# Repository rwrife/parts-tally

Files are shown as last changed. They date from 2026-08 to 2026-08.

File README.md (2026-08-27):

# Parts Tally

**Parts Tally is a USB-powered ESP32-C3 smart bin scale that counts small workshop parts by calibrated unit weight and serves a private local inventory app—no cloud account required.**

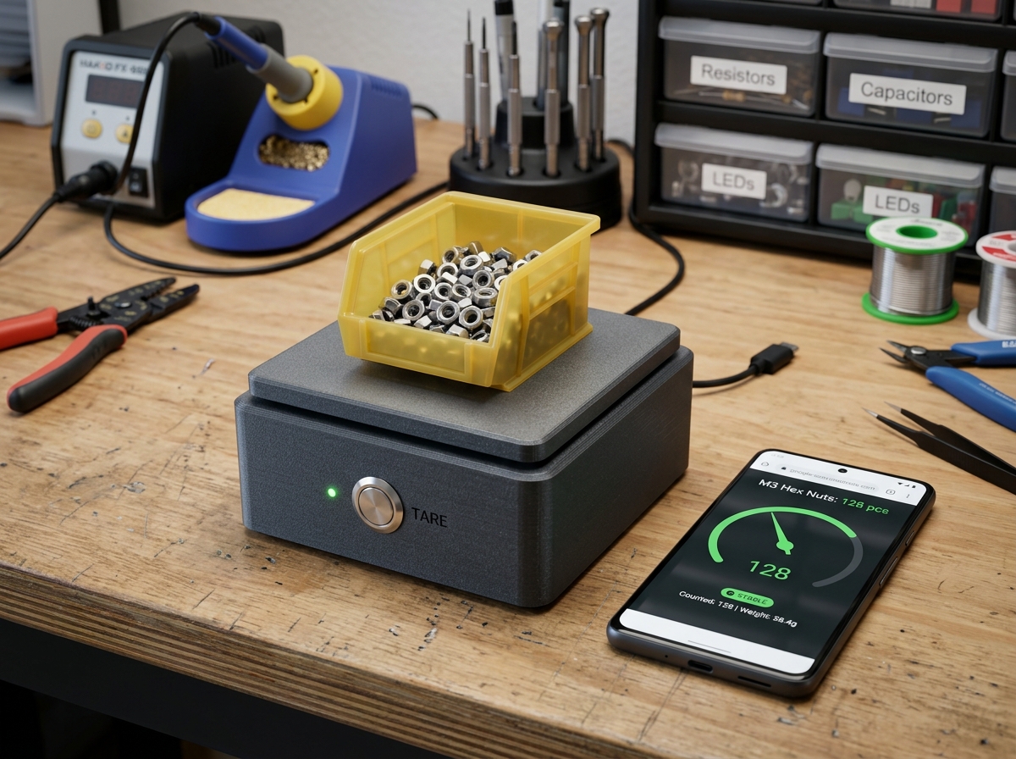
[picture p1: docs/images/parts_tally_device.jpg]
Parts Tally Concept Design


## Motivation

Counting screws, nuts, washers, crimp terminals, and other small repeated parts by hand is slow. Visual estimates are unreliable, while commercial inventory systems are often expensive or cloud-dependent. Parts Tally turns a removable parts bin into a local smart scale: select a saved part profile, tare the empty bin, and see an estimated count plus a low-stock state.

## Target users

- Home workshops and makerspaces
- Electronics benches with reels, connectors, and loose hardware
- Small repair shops that want a lightweight, account-free stock signal
- Hobbyists who need repeatable counts rather than purchasing automation

## Use cases

1. **Fast recount:** place a known bin on the platform, select its profile, and estimate count from net mass / calibrated unit mass.
2. **Low-stock check:** show green/amber/red locally against a user-defined threshold.
3. **Calibration:** weigh an empty bin, then a known sample (for example 20 washers) to derive unit mass.
4. **Portable records:** export profiles and count history as JSON or CSV from the local app.
5. **Manual correction:** override a noisy estimate and preserve an auditable correction without pretending the scale is exact.

## Intended workflow

1. Assemble the low-voltage load-cell platform and connect it by USB-C to a 5 V supply.
2. On first use, the device exposes a temporary local setup access point; the user configures Wi-Fi or continues in direct-device mode.
3. Open the phone-friendly local web app, create a part profile, tare the empty bin, and run a known-count calibration.
4. Place the loaded bin on the platform. The device filters readings, reports stability and uncertainty, then estimates count.
5. Review or correct the count, set a threshold, and export local data when desired.

## MVP

- ESP32-C3 controller with USB power, Wi-Fi, and BLE-capable hardware
- One TAL220B 5 kg 4-wire bar load cell and SparkFun SEN-15242/NAU7802 bridge ADC module
- Physical tare/calibrate button and RGB status indication
- Stable-weight detection, tare, multi-point known-count calibration, and count uncertainty
- On-device local API plus responsive installable PWA
- Local profile/history storage with JSON and CSV export/import
- Offline/direct-device mode after initial assets are loaded
- Reproducible firmware and app builds
- Editable KiCad schematic and custom carrier PCB after the module prototype is validated

## Non-goals

- Trade-certified weighing or legal-for-commerce measurements
- Medical, food-safety, life-safety, or unattended industrial process control
- Exact counting of mixed parts or parts whose unit mass varies substantially
- Mains wiring, battery charging in the first revision, or cloud accounts
- Automatic purchasing or supplier-stock claims

## Hardware at a glance

```text
5 V USB-C supply
       |
XIAO ESP32-C3 ---- planned status RGB LED
   |       |
   |       +------ tare/calibrate button
   |
   +-- SparkFun SEN-15242 / NAU7802 -- TAL220B 5 kg bar load cell
   |
   +-- local Wi-Fi HTTP/WebSocket API ------ phone/desktop PWA
```

Prototype target: approximately **USD $35–$55**, excluding a user-printed enclosure. This is a planning range, not a quote; current prices and availability must be re-verified before ordering.

## Safety limits

Parts Tally is a SELV/USB 5 V bench device. Do not connect it to mains, exceed the load cell's rated load, use it as a structural support, or rely on it for safety-critical stock decisions. Provide overload stops in the mechanical design. A printed enclosure must not carry loads through the PCB. This project is not a certified scale.

## Privacy, permissions, and storage

- No account, analytics, or cloud service is required.
- Profiles, calibration values, thresholds, and history are stored on the device and/or in browser-local storage as documented by the app implementation.
- Network access is limited to local device discovery/setup and the device API.
- BLE/Wi-Fi permissions are requested only when a chosen provisioning flow needs them.
- Export and import are explicit user actions; secrets are excluded from exports.
- Optional future integrations must remain opt-in and preserve a useful offline mode.

## Source-of-truth policy

Final BOM data belongs in **KiCad schematic symbol properties** (`Manufacturer`, `MPN`, supplier fields, and BOM notes) and is exported to `bom/bom.csv`. `bom/preliminary-bom.csv` is only a planning document and must not drift into a competing source of truth.

The hardware release uses real editable KiCad sources—not image-only drawings—including:

- `hardware/kicad/parts-tally.kicad_pro`
- `hardware/kicad/parts-tally.kicad_sch`
- `hardware/kicad/parts-tally.kicad_pcb`

The project, schematic, routed two-layer PCB, custom library, validation notes, OpenSCAD platform source, and schematic-exported BOM now exist under `hardware/kicad/`, `hardware/reports/`, `hardware/mechanical/`, and `bom/`. The tagged release workflow generates and validates Gerber/drill/CPL/PDF/assembly/render artifacts; generated outputs supplement rather than replace editable source. No assembled-board, fabricated-board, or physical-test claim is implied.

## Current status and milestones

1. Requirements, measurement model, and architecture risk review — baselined in the editable documents below; this is documentation/static evidence only
2. Datasheet-backed module-chain selection and synthetic capture harness — complete; physical fixture/bench characterization explicitly pending
3. Editable KiCad schematic and schematic-backed BOM — implemented; CI-native ERC and static review evidence are recorded under `hardware/reports/`
4. Firmware and local protocol with host-side tests
5. Accessible local PWA and import/export — implemented and software-tested with a mock transport; physical-device/browser verification remains pending
6. Carrier PCB, native DRC, and editable mechanical platform — implemented and statically validated; physical fit/assembly/bring-up remains pending
7. Tagged fabrication release package and unexecuted assembly/bring-up procedures — release-candidate automation implemented; physical evidence remains pending

Baseline contracts:

- [System architecture and count/uncertainty model](docs/architecture.md)
- [Reviewed measurable requirements](hardware/requirements.md)
- [Planned module wiring and carrier boundary](hardware/interfaces.md)
- [Datasheet-backed component selection](hardware/selection.md)
- [Planned module build and capture record](hardware/module-prototype.md)
- [Datasheet/source manifest](hardware/datasheets/manifest.json)
- [Unexecuted prototype verification plan](docs/verification-plan.md)
- [Assembly, calibration, and bring-up procedure](docs/assembly-and-bring-up.md)
- [Integrated release verification record](docs/release-verification.md)
- [Release packaging and fabrication assumptions](release/README.md)
- [Licensing and third-party notices](LICENSES.md)
- [Risk register](docs/risk-register.md)
- [Machine-readable architecture contract](docs/architecture-contract.json)

Run `python3 scripts/validate_contract.py` and `python3 -m unittest discover -s tests -v` to validate document, safety, dependency, risk, evidence-state, and synthetic capture-tool consistency.

See [PLAN.md](PLAN.md), [hardware/README.md](hardware/README.md), and the GitHub issue backlog.

## Development quickstart

The implementation toolchains will be pinned in the first project-skeleton issue. The intended commands are:

```bash
# Firmware (PlatformIO)
cd firmware
pio run
pio test -e native

# Companion PWA (TypeScript/Vite, Node 22.23.1 / npm 10.9.8)
cd app
npm ci
npm run lint
npm run typecheck
npm test
npm run build
npx playwright install chromium # first local run
npm run test:e2e
```

See `app/VERIFICATION.md` for the latest exact software verification record. App end-to-end tests use a mock device and do not establish physical integration.

## Contributing

Keep changes issue-scoped and evidence-backed. Never report physical bench testing unless a real assembled prototype and procedure were used; distinguish static analysis, simulation, firmware/app tests, and physical measurements.

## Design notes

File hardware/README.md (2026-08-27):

# Hardware

## System description

Parts Tally measures a removable bin through a 4-wire strain-gauge load cell. A 24-bit bridge ADC digitizes the differential signal. An ESP32-C3 filters readings, applies tare and known-count calibration, estimates quantity, stores local profiles, drives a status LED, and serves the local app.

The first hardware increment selected proven modules; revision A0 now includes an editable carrier layout and parametric mechanical platform so measurement and mechanical risks can be characterized before fabrication. This is still static design evidence, not prototype evidence.

## Controller choice

The selected prototype controller is **Seeed Studio XIAO ESP32-C3, SKU 113991054**. The selected ADC module is **SparkFun SEN-15242** using **Nuvoton NAU7802**; the selected carrier IC is **NAU7802SGI**. The selected load cell orderable SKU is **SparkFun SEN-14729**, containing the HT Sensor TAL220B 5 kg cell. See [`selection.md`](selection.md) and [`datasheets/manifest.json`](datasheets/manifest.json).

## Interfaces

The exact planned logical wiring map and carrier-board ownership boundary are versioned in [`interfaces.md`](interfaces.md), with pre-power and capture steps in [`module-prototype.md`](module-prototype.md). Physical connector orientation and continuity remain pending until real units exist.

- 4-wire load cell bridge to ADC: excitation +/-, signal +/-
- NAU7802 3.3 V I2C: XIAO D4/GPIO6 SDA and D5/GPIO7 SCL
- One debounced physical tare/calibrate button
- One addressable or discrete RGB status indicator with brightness limit
- USB-C 5 V input through the controller module for prototype power/programming
- 2.4 GHz Wi-Fi for local HTTP/WebSocket app; BLE reserved for evaluated provisioning only
- UART/USB recovery and accessible test points on the carrier revision

## Power plan

- SELV 5 V USB input only for MVP
- Use the controller module's regulated rail for logic, subject to measured noise/current validation
- The carrier schematic uses 3.3 V DVDD and a 3.0 V nominal internal-LDO AVDD/excitation setting; measure this boundary condition before PCB release
- Input protection, decoupling, bridge filtering, keyed load-cell connection, and reverse-current blocking are captured in the editable schematic
- No battery or charger in revision A

## Mechanical and enclosure concept

A rigid base holds one end of the TAL220B straight-bar load cell; a top plate/bin cradle attaches to the sensing end. Parametric OpenSCAD source in [`mechanical/`](mechanical/) includes M5 load-cell mounts, PCB standoffs outside the force path, cable strain relief, four non-slip feet, and four adjustable overload stops. The carrier places the XIAO antenna at a board edge with enforced two-layer copper/component keepouts; enclosure adaptations must also keep metal and fasteners out of that volume. Fit, print tolerance, stop gap, and load transfer remain physically unverified.

## Safety limits

- USB/SELV only; never connect to mains wiring
- Do not exceed the selected load cell's rated capacity
- Not structural, legal-for-trade, medical, food-safety, or life-safety equipment
- Do not use counts as the sole control for hazardous or critical stock
- Mechanical stops and a stable, non-slip base are mandatory before load testing

## Editable KiCad deliverables

The carrier-board milestone preserves:

- `kicad/parts-tally.kicad_pro`
- `kicad/parts-tally.kicad_sch`
- `kicad/parts-tally.kicad_pcb`
- project symbol/footprint tables or vendored custom libraries when needed
- ERC and DRC reports with explained exclusions
- schematic PDF and PCB renders as supplements, never substitutes
- fabrication Gerbers, drill files, CPL when applicable, and release archive

The project/schematic, routed `.kicad_pcb`, project-local symbols/footprints, generators, acceptance validators, datasheet extraction, schematic-backed BOM, mechanical source, DRC report, and review renders are present. `scripts/build_release.py` and the tagged release workflow generate and validate Gerber/drill/CPL/PDF/assembly/render outputs without treating those files as physical evidence.

Final Manufacturer, MPN, supplier, price-observation, stock-observation, datasheet, and BOM-note data lives in KiCad symbol properties. `../bom/preliminary-bom.csv` is not authoritative. From the repository root, regenerate the tracked BOM with `python3 hardware/kicad/export_bom.py`, or follow [`kicad/README.md`](kicad/README.md). Assembly order, connector maps, test points, current-limited first power, calibration, recovery, and troubleshooting are in [`../docs/assembly-and-bring-up.md`](../docs/assembly-and-bring-up.md).

## Key layout constraints for the carrier revision

- Keep bridge inputs short, paired, and away from USB/Wi-Fi/high-edge-rate nets
- Follow selected ADC reference layout and decoupling guidance
- Preserve the XIAO/ESP32-C3 antenna keepout on all copper and enclosure metal
- Separate mechanical mounting loads from the PCB
- Add named test points for rails, ADC clock/data, bridge excitation, and ground
- Provide clear connector pin-1/polarity labels and accessible programming recovery

## Current evidence

The editable KiCad project, schematic, routed carrier PCB, project-local symbols/footprints, manufacturer-document/source manifest, schematic-exported BOM, targeted validators, OpenSCAD mechanical source, and static review evidence now exist. See [`kicad/README.md`](kicad/README.md), [`mechanical/README.md`](mechanical/README.md), [`reports/schematic-validation.md`](reports/schematic-validation.md), and [`reports/layout-validation.md`](reports/layout-validation.md).

Native KiCad 9 reports zero ERC/DRC violations and zero unconnected PCB items; repository validators pass. The issue #7 release workflow regenerates Gerber/drill/CPL/PDF/assembly/render outputs from the tagged sources and verifies archive checksums. These are static checks only. No electrical/EMC simulation, physical fixture/assembly, continuity result, measurement, fabrication, calibration, load test, or field evidence exists yet. The design remains explicitly untested in hardware.

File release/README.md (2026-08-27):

# Parts Tally release candidate packaging

`release/manifest.json` freezes the board/firmware/protocol/app compatibility set. The release archive is generated from a tagged checkout by `scripts/build_release.py`; generated files are not preferred editable source.

## Build

Use KiCad 9.0.x with Python and `pcbnew` available. The GitHub workflow uses the pinned `kicad/kicad:9.0` image on an amd64 runner.

```bash
python3 scripts/build_release.py \
  --version v0.1.0-rc.1 \
  --source-ref v0.1.0-rc.1 \
  --source-revision "$(git rev-parse HEAD)" \
  --output dist
python3 scripts/validate_release.py \
  --bundle dist/parts-tally-v0.1.0-rc.1.zip
```

The archive contains:

- Gerber X2 copper, mask, paste, silkscreen, and Edge.Cuts layers;
- separate plated/non-plated Excellon drills plus an SVG drill map;
- KiCad and JLCPCB-format BOMs plus a normalized placement file;
- schematic PDF, assembly SVGs, and PCB renders;
- ERC/DRC/parity reports and a command log;
- editable KiCad/OpenSCAD sources, assembly/bring-up instructions, release report, and license notices;
- a per-file `SHA256SUMS` plus an archive checksum.

## Fabrication/assembly assumptions

The selected validation profile is JLCPCB's documented standard two-layer capability. The source rules are more conservative than its published minimums: 0.15 mm minimum track, 0.20 mm clearance, 0.60/0.30 mm via, and 0.50 mm copper-edge clearance.

This RC is suitable for **quote/DFM review**, not an unattended order:

1. Keep 100 × 60 mm, two layers, 1.6 mm nominal FR-4 unless a reviewed change is made.
2. Review the rendered files and confirm the outline, polarity, pin 1, antenna keepout, and drill split.
3. J1 has two bottom-tented, unfilled 0.60/0.30 mm through-vias inside VBUS pads. For PCBA, obtain explicit assembly-process approval for solder-wicking risk or use documented hand solder/rework. Do not represent tenting as plugging/filling.
4. The JLCPCB BOM intentionally leaves `LCSC Part #` blank for user-sourced items. It is a parity-checked assembly aid, not a guarantee that every part is available for turnkey PCBA.
5. Re-check C189895/SM04B-GHS-TB(LF)(SN), all blank supplier IDs, prices, stock, substitutions, rotations, and feeder class at checkout.
6. No substitute connector/module/ADC inherits this review. Re-run ERC, DRC, BOM/CPL parity, and datasheet pin/package review after any substitution.
7. Order a stencil only if the chosen assembly path needs one. For hand assembly, inspect USB-C and SOIC solder joints before power.

## Evidence boundary

A release archive, render, successful build, static analyzer, or simulated fixture is not physical evidence. Bench and field verification remain pending until an identified physical assembly is tested with dated raw measurements under `docs/verification-plan.md` and `docs/assembly-and-bring-up.md`.

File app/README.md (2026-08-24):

# Parts Tally companion PWA

This is the installable, responsive local companion for the Parts Tally device. It implements the HTTP/WebSocket contract in [`../docs/protocol.md`](../docs/protocol.md) and validates device status, events, and backup data at runtime against generated copies of [`../docs/schemas/api-v1`](../docs/schemas/api-v1).

## Reproducible development

Node 22.23.1 and npm 10.9.8 are pinned in `package.json`; every dependency is an exact version in `package-lock.json`.

```bash
cd app
npm ci
npm run generate
npm run lint
npm run typecheck
npm test
npm run test:a11y
npm run build
npx playwright install chromium   # first local run only
npm run test:e2e
```

`npm run generate` refreshes the runtime JSON Schema copies and their aggregate SHA-256 marker. UI components depend on `DeviceTransport`; only `src/protocol/httpTransport.ts` constructs `fetch` or `WebSocket`. Playwright uses the same adapter interface with an in-memory mock device. Those tests are software evidence only and do not claim a physical ESP32, load cell, ADC, radio, or browser/device combination was tested.

## Data boundaries and privacy

- Profiles, calibration, thresholds, history, measurements, and faults returned by a connected device are device-authoritative.
- The browser caches only the selected address, device ID, and the newest 100 validated profile/history/status records so an offline user can identify the device and inspect a clearly marked snapshot. Cached measurements are never presented as a live count.
- Device secrets, Wi-Fi passwords, setup tokens, session tokens, and authorization headers are memory-only and are not written to browser storage, JSON, CSV, the service-worker cache, or logs.
- JSON backup schema v3 contains device name, profiles, calibration, thresholds, and up to 256 device history entries. Import rejects incompatible schema versions and secret-bearing fields, displays the device preview, then requires an explicit apply action within the protocol's 30-second window.
- CSV export contains history columns only. Both exports require a user action.
- There are no accounts, analytics, ads, telemetry, cloud API, or background tracking. The app requests no camera, microphone, contacts, location, notification, or BLE permission.

## Offline and installation behavior

The generated service worker precaches the application shell (HTML, JavaScript, CSS, and icon). After one successful HTTPS or localhost load, a supporting browser can reopen and install the shell without Internet access. API responses are deliberately not service-worker cached. A device still must be reachable over its direct AP or trusted LAN for authentication, mutations, and current measurements. Browsers may evict installed-site data; JSON backup remains the portable copy.

The device protocol is plaintext HTTP/WebSocket. Use a trusted local network: an on-path observer can see bearer traffic. HTTPS-hosted public pages may also block plaintext local-device requests as mixed content, so device-hosted or explicitly trusted local serving is the practical deployment model.

## Platform scope and limitations

- Android Chromium: install prompts and standalone display are expected, but local-network permission prompts and background suspension vary by vendor/version.
- iOS/iPadOS Safari: installation is via Share → Add to Home Screen; service-worker storage can be evicted and WebSockets are normally suspended when backgrounded. There is no background counting or notification promise.
- Desktop Chromium supports installation; Firefox can use the web app and offline cache but does not consistently offer desktop PWA installation; Safari behavior varies by current macOS release.
- The automated matrix is mobile and desktop Chromium emulation. It does not prove Safari/iOS, Firefox, Android hardware, local-network routing, captive-portal behavior, or physical device integration.

## Accessibility and measurement safety

The UI is keyboard-operable, uses native landmarks/labels/tables/forms, visible focus, at least 44 px controls, text-and-icon state cues, an aria-live update region, responsive layouts, and reduced-motion handling. Vitest runs axe checks, but automation does not replace manual screen-reader, zoom, contrast, touch, and real-device testing.

Every protocol no-count state withholds the numeric count: uncalibrated, unstable, stale, disconnected, saturated, overload indicated, below tare, calibration invalid, and excessive uncertainty. Parts Tally is USB 5 V SELV-only, not legal-for-trade, not certified, and not suitable for safety-critical stock or measurement decisions. Observe load-cell ratings and mechanical overload protection.

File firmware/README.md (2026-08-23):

# Parts Tally firmware

Pinned PlatformIO/C++17 project for Seeed XIAO ESP32-C3 (`seeed_xiao_esp32c3`, Arduino) and native tests. Install exactly `platformio==6.1.18`, then run `pio test -d firmware -e native` and `pio run -d firmware -e seeed_xiao_esp32c3`. Platforms and the ArduinoJson 7.4.2/WebSockets 2.7.1 dependencies are pinned in `platformio.ini`.

Hardware is behind narrow ADC, button, active-low RGB, clock, atomic storage and transport interfaces. Pins mirror `hardware/interfaces.md`: SDA 6, SCL 7, button 3, RGB 4/5/10 and UART TX/RX 21/20. The standard-C++ domain implements health-first faults, sustained-step acceptance, P95-P5/slope/outlier diagnostics, the >=2 s/>=20 sample gate, safe tare/calibration, deterministic rounding, conservative uncertainty and explicit null-count states. Persistence is versioned/checksummed, bounds history to 256 by default and never exports secret members.

## Target integration status

The target build contains the NAU7802 register/DRDY/fault adapter, verified two-slot Preferences records, full-NVS factory erasure, entropy-backed setup session, setup AP, HTTP route dispatch, and sequenced WebSocket server. These paths compile but have not run on a physical XIAO/NAU7802 assembly, so register waveforms, calibration completion, AP association, NVS interruption behavior, route latency, RF coexistence, and RGB/button timings remain bench checks. `/api/v1` policy and route behavior are independently exercised by native tests.

The direct AP starts on every boot. Hold dedicated GPIO3 during power-up to create the five-minute setup session, fetch `/api/v1/setup/session`, then call `/api/v1/setup/provision`. Provisioning supports empty SSID/password direct-only mode or starts asynchronous STA while retaining the AP. Later sessions are obtained from unauthenticated `POST /api/v1/session` using the persisted device secret and exact Origin/JSON checks. WebSocket clients connect to the exact `ws://192.168.4.1:81/api/v1/events` path and send `{"type":"authenticate","token":"SESSION"}` as their initial message; authorization and expiry are tracked per client, and setup sessions cannot stream events.

## Physical reset and USB recovery

The target implements this factory-reset gesture on dedicated GPIO3: power up while holding for 10 seconds, blink red/blue for the final three seconds, cancel if released early, erase the complete NVS partition (settings, profiles, thresholds, history, and Wi-Fi/device secrets), and restart only after successful erasure. A short release requests local tare; an arbitrary later long press cannot factory-reset. No network route resets the device. Host tests cover the state machine, but physical timing and erasure still require target/bench verification. Credentials persist in NVS and are excluded from normal logs/status/export/JSON backup/CSV, but NVS is not a secure element or a defense against physical flash extraction.

OTA is omitted. For USB recovery, power only from USB 5 V SELV, connect GPIO9/BOOT to GND, briefly press RESET, release BOOT, identify the serial port, then run `pio run -d firmware -e seeed_xiao_esp32c3 -t upload --upload-port PORT`. Press RESET without BOOT and inspect serial at 115200. If enumeration fails, use a known data cable, disconnect carrier peripherals, and repeat. Flashing is not guaranteed to erase NVS. BOOT is not the user button. Never connect mains.

This workshop aid is not legal-for-trade, certified, or suitable for safety-critical inventory decisions.

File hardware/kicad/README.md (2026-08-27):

# Parts Tally KiCad source

This directory contains the editable KiCad 9 schematic and routed two-layer carrier PCB for revision A0. The design is static-analysis/DRC reviewed but has not been fabricated, assembled, electrically measured, calibrated, or field tested.

## Files

- `parts-tally.kicad_pro` — KiCad project metadata and board rules.
- `parts-tally.kicad_sch` — editable schematic and BOM source of truth.
- `parts-tally.kicad_pcb` — editable 100 × 60 mm routed board source.
- `lib/parts-tally.kicad_sym` — project-local XIAO ESP32-C3 and NAU7802 symbols.
- `lib/parts-tally.pretty/XIAO_ESP32C3.kicad_mod` — project-local module footprint.
- `generate_schematic.py` — reproducible schematic generator.
- `generate_pcb.py` — reproducible board outline, placement, rules, labels, mounting holes, and antenna keepouts from the KiCad XML netlist.
- `pre_route_critical.py` — fixed VBUS/I2C/+5 V escapes around the USB locator holes and XIAO antenna keepout.
- `route_pcb.py` — netclass-aware Specctra DSN/SES exchange and idempotent GND-pour fill.
- `finish_route.py` — deterministic local TP2 branch left by the autorouter.
- `validate_hardware.py` — schematic pin map, net-label, NC, BOM-property, and extraction checks.
- `validate_pcb.py` — PCB/netlist parity, geometry, mounting, keepout, zone, route-width, and analog-pair checks.
- `export_bom.py` — deterministic export from schematic properties to `../../bom/bom.csv`.

The XIAO library source and adaptation are documented in `lib/README.md`.

## Board design summary

- 100 × 60 mm, two copper layers, four 3.2 mm M3 mounting holes.
- U1 sits at the top-right edge with four layer-specific rule areas. Copper, tracks, vias, and components are prohibited in the transformed XIAO/ESP32-C3 antenna regions.
- J1 is a **power-only** USB-C UFP. Its locator-hole geometry requires two bottom-tented 0.60/0.30 mm via-in-pad transitions to tie the duplicated VBUS pad locations on B.Cu. D+/D-/SBU remain intentionally NC.
- VBUS and protected +5 V use 0.50 mm trunks with short 0.20 mm branches/neck-downs; low-current 3.3 V distribution uses 0.20 mm routing. Thirteen 0.15 mm FreeRouting neck-down segments occur only at constrained fine-pitch pads and remain above the selected prototype process minimum.
- `/LC_S+` and `/LC_S-` measure 10.01/11.04 mm (1.04 mm delta). `/AIN+` and `/AIN-`, including filter branches, measure 37.71/30.91 mm (6.80 mm delta). These are low-bandwidth bridge signals, not timing-matched digital pairs.
- Solid-connected GND pours cover F.Cu and B.Cu; five GND vias join the planes. The bottom plane is the preferred return path.
- TP1–TP10 expose VBUS, protected +5 V, 3V3, GND, AVDD, I2C, bridge inputs, and VBG.
- J2 pin order is 1 E+, 2 E-, 3 S+, 4 S-. Verify the real harness continuity and wire colors before power.

## Validate the committed design

Use KiCad 9 and Python 3.11+:

```bash
python3 -m venv .venv
. .venv/bin/activate
pip install -r hardware/kicad/requirements.txt
python hardware/kicad/validate_hardware.py
python hardware/kicad/export_bom.py --check

kicad-cli sch erc --exit-code-violations \
  -o /tmp/parts-tally-erc.rpt hardware/kicad/parts-tally.kicad_sch
kicad-cli sch export netlist --format kicadxml \
  -o /tmp/parts-tally.xml hardware/kicad/parts-tally.kicad_sch
python hardware/kicad/validate_pcb.py \
  hardware/kicad/parts-tally.kicad_pcb --netlist /tmp/parts-tally.xml
kicad-cli pcb drc --severity-all --all-track-errors --exit-code-violations \
  -o /tmp/parts-tally-drc.rpt hardware/kicad/parts-tally.kicad_pcb
```

The GitHub workflow runs the native KiCad commands in `kicad/kicad:9.0`, avoiding host-version ambiguity. Review evidence is in `../reports/layout-validation.md` and `../reports/generated/`.

## Regenerate placement and reroute

The committed `.kicad_pcb` is the reviewed editable layout source. The placement and critical escapes are reproducible; FreeRouting is nondeterministic, so a new autoroute is a new design revision and must pass all checks and visual review.

```bash
kicad-cli sch export netlist --format kicadxml \
  -o /tmp/parts-tally.xml hardware/kicad/parts-tally.kicad_sch
python hardware/kicad/generate_pcb.py \
  --netlist /tmp/parts-tally.xml --output hardware/kicad/parts-tally.kicad_pcb
python hardware/kicad/pre_route_critical.py hardware/kicad/parts-tally.kicad_pcb
python hardware/kicad/route_pcb.py export-dsn \
  hardware/kicad/parts-tally.kicad_pcb /tmp/parts-tally.dsn
java -jar freerouting-2.3.0.jar --gui.enabled=false \
  -de /tmp/parts-tally.dsn -do /tmp/parts-tally.ses \
  -mp 30 -mt 4 -us Hybrid -hr 1:1 -is prioritized
python hardware/kicad/route_pcb.py import-ses \
  hardware/kicad/parts-tally.kicad_pcb /tmp/parts-tally.ses
python hardware/kicad/finish_route.py hardware/kicad/parts-tally.kicad_pcb
python hardware/kicad/route_pcb.py add-ground-zones \
  hardware/kicad/parts-tally.kicad_pcb
```

The recorded local route used FreeRouting 2.3.0 on Java 25 and KiCad 9.0.9. Do not accept an autorouter success code as evidence: run KiCad DRC and inspect the report.

## Sourcing and mechanics

Every populated symbol carries `Manufacturer`, `MPN`, supplier/source, supplier PN, datasheet, dated cost/stock observations, and BOM notes. `bom/bom.csv` is generated from those properties. `bom/non-schematic-items.csv` separately tracks the load cell, mating parts, printed pieces, cable restraint, feet, overload stops, and fasteners. Re-check all stock and prices before ordering.

Editable enclosure/platform source is under `../mechanical/`; force flows from top plate → load cell → base and does not pass through the PCB. Preserve the antenna no-metal/no-fastener volume when adapting the enclosure.

## Important limitations

This remains a PCB-layout/static-analysis deliverable. Native ERC/DRC and structural checks pass, while the installed KiCad MCP analyzer lacks `pcbnew` and no local EMC/SPICE analyzer scripts are available. Issue #7 adds a tagged KiCad 9 workflow that regenerates and validates the Gerber/drill/CPL archive; those generated files are not preferred editable source or proof of fabrication. There is no assembled prototype, continuity record, USB current measurement, RF/EMC measurement, load test, calibration, thermal test, or field test. The device remains USB/SELV-only and is not legal-for-trade or safety certified.

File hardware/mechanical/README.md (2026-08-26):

# Mechanical platform source

`parts-tally-platform.scad` is the editable, parametric revision-A0 mechanical source for the carrier, TAL220B load cell, top plate/bin cradle, strain relief, non-slip feet, PCB mounts, and adjustable overload stops. Attached bosses, rails, brackets, and contact pads overlap their parent plate by 0.1 mm so each export is one printable manifold volume rather than a collection of merely coplanar shells.

## Evidence and dimensions

- The manufacturer TAL220B drawing at `https://cdn.sparkfun.com/assets/e/5/f/5/6/TAL220B.pdf` (tracked SHA-256 `641b4150169e53e4e1fd33bc859d30ca371204243dc30b9987d6048ffd021181`) specifies a 55 × 12.7 × 12.7 mm body, 40 mm mounting-hole centre spacing, and M5 passages.
- PCB size and hole coordinates come from `../kicad/parts-tally.kicad_pcb`: 100 × 60 mm; board coordinates (4,4), (64,4), (4,56), and (96,56) mm.
- The XIAO antenna reference volume is derived from the KiCad rule areas. It is a mechanical keep-clear volume: no metal, fastener, cable loop, or shield may enter it.

## Force path

The top plate connects only to the load cell's free end. The load cell's fixed end connects to the base. Both printed M5 passages are centered on the drawing's ±20 mm load-cell hole centers; export-time OpenSCAD assertions fail if either mount origin drifts out of alignment. Four solid 12 mm underside pads provide collision surfaces; there are no through-access holes at the contact points. Each lower boss models a 6.2 × 6 mm M4 heat-set-insert pocket plus a 13.2 mm engaged/protruding nylon-tip M4 set screw and jam-nut reference. The modeled screw-tip plane—not the bare boss top—is `stop_nominal_gap` below the pad. Adjust and lock the screws before installing the top platform. Verify all dimensions against the purchased inserts/screws. The PCB is mounted on separate M3 standoffs below the platform and is not a structural member.

`stop_nominal_gap = 0.8` mm is only a printable setup target. Set the real stop gap using a current-limited, controlled load procedure so contact occurs below the TAL220B 120% full-scale safe-overload boundary. Print tolerance is not calibration evidence.

## Export

Open in OpenSCAD and set `part` to `base`, `platform`, `stop_gauge`, or `assembly`. Command-line examples:

```bash
openscad -D 'part="base"' -o generated/parts-tally-base.stl parts-tally-platform.scad
openscad -D 'part="platform"' -o generated/parts-tally-platform.stl parts-tally-platform.scad
openscad -D 'part="assembly"' --imgsize=1600,1000 -o generated/parts-tally-assembly.png parts-tally-platform.scad
python validate_stl.py generated/parts-tally-base.stl generated/parts-tally-platform.stl
```

The validator checks each ASCII STL for finite/non-collinear triangles, one edge-connected shell, exactly two oppositely directed facets per edge, and a single-cycle link around every vertex. It rejects empty, degenerate, open, disconnected, inconsistently wound, and topologically non-manifold output. It does not replace slicer review or detect every possible triangle self-intersection.

## Fabrication gaps

This CAD is static/manufacturer-drawing evidence only. Before fabrication, measure the purchased cell, selected bin, connector/cable bend radii, enclosure wall process, printer/material shrinkage, and fastener stack. No fixture has been printed, assembled, loaded, or measured. Keep the device USB/SELV-only and do not use it as a structural or certified scale.

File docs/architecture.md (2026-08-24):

# Parts Tally system architecture

**Architecture version:** 1.1
**Baseline date:** 2026-08-20
**Status:** Firmware, protocol, and companion PWA implemented with native, contract, accessibility, and mock-browser tests; ESP32-C3 target compile implemented; physical verification pending

This document defines the module-prototype boundary and the later carrier-board boundary. It is not evidence that either assembly exists. The companion machine-readable summary is [`architecture-contract.json`](architecture-contract.json).

## 1. Safety and product boundary

Parts Tally is a USB-powered, SELV-only workshop aid. It is not legal-for-trade, safety-certified, medical, food-safety, life-safety, or suitable for hazardous-process control. It never switches mains and has no battery charger. A displayed count is an estimate derived from calibrated unit mass, not an authoritative inventory or weight.

The design must preserve explicit `unstable`, `stale`, `disconnected`, `saturated`, `overload_indicated`, `uncalibrated`, and `calibration_invalid` states. None may be silently converted into a count.

## 2. Architecture overview

```text
USB 5 V SELV
    |
    +--> controller module power/regulation ----> status LED + button
    |                |
    |                +--> local storage (settings/profiles/history)
    |                +--> local HTTP/WebSocket transport --> PWA
    |
    +--> bridge ADC/reference/excitation --> 4-wire load cell
                    |                         |
                    +--> raw samples          +--> mechanical load path
                              |
                              v
                 health checks -> filtering -> stability gate
                              -> tare/calibration -> mass + uncertainty
                              -> count estimate or explicit no-count state
```

### Subsystem ownership

| Subsystem | Owns | Must not own |
|---|---|---|
| Mechanical assembly | Base, fixed/sensing load-cell mounts, top plate/bin cradle, overload stops, feet, cable strain relief | PCB structural loads or count calculation |
| Load cell + bridge ADC | Excitation, differential bridge conversion, raw conversion samples, hardware fault indications where available | Tare, rounding, profiles, network behavior |
| Firmware drivers | ADC/button/LED/clock/storage/transport adapters and target-specific recovery | Measurement policy embedded in GPIO/network code |
| Measurement domain | Health checks, filtering, stability, tare, calibration, mass, count, uncertainty, no-count decisions | HTTP/WebSocket or flash APIs |
| Device services | Versioned persistence, bounded history, provisioning, authenticated `/api/v1`, event sequencing | Browser-only state as authoritative calibration |
| Companion PWA | Guided setup/calibration, status, corrections, thresholds, export/import preview, accessibility | Direct hardware access or hidden count inference |

## 3. Power and electrical boundaries

1. Input is a compliant 5 V USB SELV source only.
2. The module prototype is powered through the selected controller board's supported USB input.
3. The selected module chain is XIAO ESP32-C3 113991054 plus SparkFun SEN-15242/NAU7802 and SEN-14729/TAL220B. It uses 3.3 V I2C logic and begins with 3.0 V nominal bridge excitation; the boundary-condition voltage and noise remain measurement gates.
4. Normal current is a design target below 500 mA, not a measured claim. Peak and steady current must be measured on real hardware before release.
5. Recovery remains available over the controller's documented USB/UART path without LAN access.
6. The carrier revision adds protection, decoupling, named test points, connector protection, and ground/return strategy from manufacturer application guidance.

## 4. Measurement data flow

### 4.1 Terms

For each accepted ADC sample:

- `r[i]`: raw ADC code with monotonic timestamp.
- `f[i]`: filtered code after fault rejection and bounded outlier filtering.
- `T`: stored tare code for a specific bin/profile.
- `S`: calibrated scale factor in grams per code.
- `m = (f - T) * S`: net mass in grams.
- `Ncal`: known calibration sample count, at least 10.
- `mcal`: stable net mass of the known sample.
- `u = mcal / Ncal`: calibrated unit mass in grams per piece.
- `B`: measured stable noise band in grams, defined as `P95 - P5` over a stationary window after filtering.

No implementation may substitute an arbitrary constant for `S`, `u`, or `B` and still call the result calibrated.

### 4.2 Sample health and filtering

The pipeline processes timestamped samples in this order:

1. Reject or fault stale, missing, impossible, saturated, or disconnected samples before filtering.
2. Apply a bounded outlier rule that cannot conceal a sustained step. The exact algorithm is selected and golden-tested in issue #4.
3. Compute a rolling center, `P95 - P5` noise band, slope, outlier rate, and sample age.
4. Reset the stability dwell timer after a step, health fault, excessive spread, excessive slope, or excessive outlier rate.

The initial ADC baseline is 10 SPS, channel 1, PGA 128; 80 SPS is a separate comparison condition. Stability/noise thresholds are not frozen without characterization. The implementation must use named, persisted, bounded parameters and record the active values in diagnostics.

### 4.3 Stability contract

A reading is `stable` only when all conditions are true:

- at least two seconds and at least 20 accepted samples are in the current stationary window;
- no sensor health fault is active;
- sample age is within the configured stale limit;
- `P95 - P5` is at or below the characterized stability-band limit;
- absolute fitted slope is at or below the characterized drift limit;
- no unacknowledged load step occurred during the dwell period; and
- the outlier rate is within the characterized limit.

The two-second/20-sample floor is a baseline requirement. Issue #2 may tighten it with recorded evidence. It may not be weakened merely to make noisy data appear stable.

### 4.4 Tare and zero behavior

- Tare is accepted only from a stable, healthy, unsaturated reading.
- Tare is profile/bin-specific and records raw tare, timestamp/uptime context, firmware/schema version, and active measurement parameters.
- A net mass whose magnitude is within the active zero band may be displayed as zero mass.
- A negative net mass outside the zero band yields `below_tare` and withholds count; it is not clamped into a valid count.
- A changed bin, fixture, or load path requires a new tare and may require recalibration.

### 4.5 Known-count calibration

Calibration is committed only when:

1. empty-bin tare is valid;
2. the known sample contains `Ncal >= 10` identical pieces;
3. the sample reading is stable and healthy;
4. `mcal > 0` and neither tare nor sample approaches ADC saturation;
5. derived unit mass `u` is at least `20 * B`; and
6. stored values pass finite/range/schema checks.

A failed condition produces an explicit reason and preserves the previous valid calibration.

### 4.6 Count and uncertainty model

For a valid stable net mass and calibration:

```text
q = m / u
n = nearest integer to q, with exact half ties rounded away from zero
```

Negative `n` is never emitted as inventory. The firmware instead reports `below_tare` or zero within the zero band.

The baseline conservative uncertainty is:

```text
Um = max(B, drift_allowance, calibration_residual)
Uq = ceil(Um/u + abs(m)*Uu/(u*u) + 0.5)
```

where `Uu` is the stored unit-mass uncertainty from repeated calibration evidence or a conservative sample-variation bound. The final response contains both `estimatedCount = n` and `uncertaintyPieces = Uq`; it never drops uncertainty to imply exactness.

If repeated calibration evidence is unavailable, `Uu` uses a documented conservative default and the profile is marked `provisional`. Issue #2 must characterize the initial default before release.

### 4.7 Minimum usable part and no-count rules

The minimum usable unit mass for a setup is:

```text
u_min = max(20 * B, characterized_resolution_floor)
```

Count is withheld when any of these applies:

| State | Trigger | Required behavior |
|---|---|---|
| `uncalibrated` | No valid tare/scale/unit mass | Show guided calibration; no count |
| `unstable` | Stability contract fails | Show mass/raw diagnostics if safe; no authoritative count |
| `stale` | Last accepted sample exceeds limit | No count; report age |
| `disconnected` | Open bridge/module/transport evidence | No count; recovery guidance |
| `saturated` | ADC near or at conversion rail | No count; remove load/check wiring |
| `overload_indicated` | Validated raw/mass threshold exceeded | No count; remove load and inspect mechanical stops |
| `below_tare` | Negative mass beyond zero band | No count; check bin/tare |
| `calibration_invalid` | Non-finite/out-of-range/corrupt/migrated-invalid record | Preserve fault and require recalibration |
| `uncertainty_excessive` | `Uq` exceeds configured profile limit | Withhold count; report diagnostics and require a better calibration/part/setup |

## 5. Firmware task and interface boundaries

The implementation in issue #4 uses dependency-injected interfaces:

- `IAdcReader` returns timestamped raw samples and hardware fault metadata.
- `IMeasurementPipeline` consumes samples and returns health, stability, mass, count, uncertainty, and diagnostics.
- `ICalibrationStore` persists versioned tare/calibration records atomically.
- `IClock` provides monotonic time separately from optional wall-clock time.
- `IStorage` provides bounded, migration-tested persistence.
- `IProtocolTransport` maps typed domain commands/events to HTTP/WebSocket.
- `IButton` and `IStatusIndicator` preserve local tare/recovery/status access.

Measurement acquisition must not block watchdog/network servicing. Network failure must not stop local sampling or physical status. Storage writes must not occur on every sample.

## 6. Storage and data authority

| Data | Authority | Browser cache allowed? | Exported? |
|---|---|---|---|
| Device settings/schema | Device | Read-only copy | Yes, excluding secrets |
| Calibration profiles and tare | Device | Read-only/cache for UX | Yes |
| Thresholds | Device | Pending edit until acknowledged | Yes |
| Bounded history/corrections | Device | Paginated cache | Optional JSON; CSV |
| Wi-Fi credentials/device secret/session tokens | Device secure/platform storage | No | Never |
| PWA preferences/selected device | Browser | Yes | Optional app settings only |

Every persistent record has a schema version. Migrations are atomic and tested against corruption/interruption. A corrupt calibration never falls back to a plausible-looking count.
Wi-Fi and device credentials are retained in ESP32 NVS and excluded from logs, status, JSON
backup/export, and CSV. NVS is not a secure element or encryption boundary; physical flash
extraction can expose those secrets.

## 7. Provisioning, API, and app boundary

- Every boot retains a direct AP; a power-up button hold opens the physical-presence setup session,
  and stored credentials additionally start a nonblocking STA attempt.
- No cloud account or Internet connection is required.
- After provisioning, mutating `/api/v1` operations require a per-device secret/session and idempotency identifier.
- WebSocket events are sequenced; clients refresh status after a gap.
- UI components use a typed transport adapter and never call HTTP/WebSocket directly.
- Core button/status behavior remains available without LAN or Internet.
- Protocol v1 documents plaintext-HTTP residual LAN risk; authenticated TLS is not claimed.

The finalized contract is in [`protocol.md`](protocol.md). Framework-independent guards, routes,
and schemas are implemented, and the direct AP/STA plus HTTP/WebSocket adapters compile for the
target. Their execution on ESP32 hardware remains bench work.

## 8. Mechanical load path

```text
bin -> top plate/cradle -> sensing end of load cell
                         -> fixed end of load cell -> rigid base -> feet -> bench
```

The PCB, USB connector, ADC board, cable, and enclosure walls are outside the force path. Adjustable mechanical stops engage before damaging deflection. Off-center and overload tests are prohibited until the fixture, stops, and rated-load evidence exist.

## 9. Module prototype versus carrier revision

| Concern | Module prototype | Carrier revision |
|---|---|---|
| Controller | Seeed XIAO ESP32-C3 SKU 113991054 | Same validated module or justified exact replacement |
| ADC | SparkFun SEN-15242 / Nuvoton NAU7802 | NAU7802SGI plus Rev. 2.6 reference application components in KiCad |
| Wiring | Short labeled harness per `hardware/interfaces.md` | Keyed connector and named nets/test points |
| Power | Supported controller USB input | Reviewed USB/protection/regulation/decoupling |
| RF | Physical clearance around module antenna | Enforced copper/component/mechanical keepout |
| Evidence | Datasheet review + synthetic harness, then bench data if hardware exists | ERC/DRC/analyzers, fabrication, then bench evidence |

## 10. Verification stages and gates

1. **Documentation/static:** this architecture, requirements, risk register, protocol, and contract checks.
2. **Datasheet/selection (#2):** exact MPNs/SKUs, pinouts, application circuits, voltage/current, package, lifecycle, sourcing, and fixture dimensions.
3. **Synthetic/software (#2/#4/#5):** raw-capture parser, golden sample streams, firmware native tests, target compile, protocol compatibility, PWA tests/build.
4. **Schematic/layout (#3/#6):** real KiCad sources, ERC/DRC/analyzers, footprint/pad/pin verification, BOM/datasheet coverage.
5. **Bench:** real assembled fixture with dated raw data for the procedures in `verification-plan.md`.
6. **Field:** separate prolonged workshop use; never inferred from bench or simulation.

No later stage may be claimed from an earlier stage's evidence.

## 11. Open decisions delegated by dependency order

- #2 residual bench work: actual purchased revisions, excitation/noise/RF characterization, fixture evidence, and characterized stability thresholds. These remain explicitly unexecuted because no hardware is available.
- #3: protection/regulation, exact button/status/carrier-connector selections, footprints, debug/test points, and schematic-backed BOM.
- #4: filtering implementation, storage schema, authentication/session details, logging, recovery, and target build.
- #5: accessible workflows, caching behavior, and offline/PWA platform limits.
- #6: PCB stackup/layout/keepouts and mechanical dimensions/overload stops.
- #7: real bring-up, fabrication outputs, licenses, release manifest, and remaining gaps.

## 12. Current evidence

Completed: requirements/architecture contracts; manufacturer-document selection of XIAO 113991054, SEN-15242/NAU7802SGI, and SEN-14729/TAL220B; exact planned module wiring; a source/hash manifest; tested raw-capture/analysis software with synthetic fixtures; firmware native tests and ESP32-C3 target compile; and the installable companion PWA with static, unit/component, accessibility, production-build, and mock-browser verification.

Not completed: PCB layout, electrical simulation, fabrication, assembly, continuity checks, execution of the PWA against physical device networking, execution of the NAU7802/NVS/network adapters on hardware, bench measurements, or field testing. Firmware/app tests and a target compile are software evidence only. Datasheet review is not physical validation.

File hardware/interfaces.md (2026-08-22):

# Module prototype wiring and carrier boundary

**Interface map version:** 1.2<br>
**Status:** module prototype map retained; carrier schematic pin assignments added and statically reviewed; assembly/continuity/bench evidence absent

This file defines logical nets and ownership. Exact selection evidence is in [`selection.md`](selection.md), document hashes/links in [`datasheets/manifest.json`](datasheets/manifest.json), and the pre-power/capture record in [`module-prototype.md`](module-prototype.md). Wire color alone is never pinout evidence.

## Selected module-prototype map

```text
USB 5 V SELV
  -> Seeed XIAO ESP32-C3 SKU 113991054 USB-C

XIAO 3V3 + GND
  -> SparkFun SEN-15242 3V3/VCC + GND

XIAO D4 / GPIO6 / SDA
  -> SEN-15242 SDA / NAU7802 SDIO
XIAO D5 / GPIO7 / SCL
  -> SEN-15242 SCL / NAU7802 SCLK

SEN-15242 E+ / E-
  -> TAL220B red / black excitation leads
TAL220B green / white signal leads
  -> SEN-15242 A+ / A-
```

Selected electrical defaults are 3.3 V DVDD/Qwiic logic, 3.0 V nominal AVDD/bridge excitation, channel 1, PGA 128, and 10 SPS. These are datasheet-reviewed starting settings, not measured values or final thresholds. The carrier uses a dedicated button and discrete RGB indicator; BOOT/RESET remains reserved for recovery.

## Wiring record

| Logical connection | Source terminal/pin | Destination terminal/pin | Voltage/domain | Verification source | Current evidence |
|---|---|---|---|---|---|
| USB input | Compliant USB-C supply | XIAO USB-C | 5 V SELV | Seeed 113991054 datasheet pp. 4–5 | Datasheet/static only |
| ADC supply | XIAO `3V3` | SEN-15242 `3.3V/VCC` | 3.3 V | Seeed p. 5; SparkFun board schematic p. 1 | Datasheet/static only |
| Common ground | XIAO `GND` | SEN-15242 `GND` | 0 V | Board schematics/labels | Static only; continuity pending |
| I2C data | XIAO D4/GPIO6/SDA | SEN-15242 SDA/NAU7802 SDIO | 3.3 V open drain | Seeed pinout workbook; Nuvoton Rev. 2.6 p. 6 | Datasheet/static only |
| I2C clock | XIAO D5/GPIO7/SCL | SEN-15242 SCL/NAU7802 SCLK | 3.3 V open drain | Same | Datasheet/static only |
| Excitation positive | SEN-15242 `E+` | TAL220B red | ~3.0 V nominal | TAL220B p. 1; SparkFun hookup guide | Datasheet/static only |
| Excitation negative | SEN-15242 `E-` | TAL220B black | excitation return | Same | Datasheet/static only |
| Signal positive | TAL220B green | SEN-15242 `A+` | differential analog | Same | Datasheet/static only; polarity trial pending |
| Signal negative | TAL220B white | SEN-15242 `A-` | differential analog | Same | Datasheet/static only; polarity trial pending |
| Physical user input | PTS810 active-low button, 10 kΩ pull-up, 100 nF debounce | XIAO D1/GPIO3 | 3.3 V logic | KiCad schematic; Seeed pin map | Static only; firmware and bench timing pending |
| User status red | ASMT-YTC7 red cathode through 220 Ω | XIAO D2/GPIO4 | 3.3 V active-low sink | KiCad schematic; Broadcom AV02-3819EN | Static only; current/brightness measurement pending |
| User status green | ASMT-YTC7 green cathode through 220 Ω | XIAO D3/GPIO5 | 3.3 V active-low sink | Same | Static only; current/brightness measurement pending |
| User status blue | ASMT-YTC7 blue cathode through 220 Ω | XIAO D10/GPIO10 | 3.3 V active-low sink | Same | Static only; current/brightness measurement pending |
| UART debug | J3 pin 3 TX / pin 4 RX | XIAO D6/GPIO21 and D7/GPIO20 | 3.3 V logic | KiCad schematic; Seeed pin map | Static only; target communication pending |

## Harness and physical controls

- Use CAB-17261 or individually continuity-verified jumpers; record connector orientation and pin labels on the real assembly.
- Keep excitation and signal conductors paired/short and away from USB, antenna, and digital edges.
- Add strain relief so cable movement cannot pull ADC/load-cell terminals.
- Preserve manufacturer antenna clearance from load-cell metal, fasteners, wiring loops, and enclosure features.
- Mount electronics outside the force path and away from overload-stop contact.
- Carrier TP1–TP10 provide access for USB VBUS, protected 5 V, 3V3, GND, AVDD/bridge excitation, I2C data/clock, differential inputs, and VBG; layout/access review remains pending.
- The SEN-15242 spring terminal is a prototype convenience, not the carrier's keyed connector decision.

## Carrier-board boundary

The carrier schematic accepts:

- XIAO ESP32-C3 SKU 113991054 or a separately reviewed exact replacement;
- Nuvoton NAU7802SGI in SOP-16 and the Rev. 2.6 application/reference components;
- one keyed four-position load-cell connector with mating-half documentation;
- one dedicated physical button and one dedicated accessible status indicator;
- USB/recovery access and named test points;
- mechanical mounting that carries no scale force.

The carrier schematic owns protection, decoupling, 3.3 V/AVDD generation, I2C pull-up ownership, filter values, test points, net names, connector mapping, and symbol/footprint properties. The PCB owns return paths, analog spacing, antenna keepout rule areas, connector access, and silkscreen orientation.

## Interface invariants

1. Swapping `S+`/`S-` may change sign but is corrected in the documented wiring, not hidden as an unexplained software quirk.
2. Swapping excitation and signal pairs is prohibited.
3. No GPIO is assigned without checking controller revision and boot/recovery constraints; D4/D5 are selected only for I2C.
4. Never put 5 V Qwiic pull-ups onto XIAO SDA/SCL.
5. A disconnected, stale, saturated, calibration-error, or overload-indicated sensor produces no count.
6. Networking is not required for the physical status/recovery path.
7. The exact built wiring and part markings are recorded with characterization data.
8. 3.0 V AVDD/excitation is a boundary condition that must be measured before PCB release.

## Evidence boundary

This map is implemented in `kicad/parts-tally.kicad_sch` and supported by manufacturer documents. It is not a continuity result, assembly record, bench test, or field test. No physical prototype or photos are available.

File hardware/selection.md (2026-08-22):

# Datasheet-backed measurement-chain selection

**Selection revision:** 1.1<br>
**Reviewed:** 2026-08-21T00:42:08Z<br>
**Evidence class:** manufacturer-document review and current web sourcing; no physical assembly or measurements

## Decision

Use this exact module-prototype chain:

| Function | Manufacturer | Exact orderable MPN/SKU | Selected configuration |
|---|---|---|---|
| Controller board | Seeed Technology Co., Ltd. | **113991054** — Seeed Studio XIAO ESP32-C3 | USB-C 5 V input; 3.3 V rail; D4/GPIO6 SDA and D5/GPIO7 SCL |
| Bridge ADC module | SparkFun Electronics | **SEN-15242** — SparkFun Qwiic Scale, NAU7802 | 3.3 V Qwiic bus, channel 1, PGA 128, start at 10 SPS; characterize 80 SPS separately |
| Bridge ADC for later carrier | Nuvoton Technology Corporation | **NAU7802SGI** | SOP-16, 150 mil; reproduce and validate the Rev. 2.6 application circuit in KiCad |
| Load cell | SparkFun Electronics orderable SKU; HT Sensor underlying cell | **SEN-14729**, containing **TAL220B 5 kg** | Four-wire full bridge; 3–10 V excitation; planned 3.0 V nominal excitation from the ADC module |
| Controller-to-ADC cable | SparkFun Electronics | **CAB-17261** — flexible Qwiic female-jumper cable | Female Qwiic end at SEN-15242; individual jumpers to XIAO header pins |

The carrier schematic now selects **PTS810SJM250SMTRLFS** for the dedicated button, **ASMT-YTC7-0AA02** for the discrete RGB status indicator, and **SM04B-GHS-TB(LF)(SN)** for the keyed load-cell connector. YTC7 replaces the obsolete but electrically pin-compatible YTC2 draft selection. Reusing BOOT/RESET as the product control remains rejected because those pins are part of recovery. J2's exact enclosure/strain-relief interaction remains a PCB/mechanical review item, and its LCSC listing was out of stock on 2026-08-21.

## Why NAU7802 rather than HX711

| Criterion | HX711 | NAU7802 | Decision effect |
|---|---|---|---|
| Supply/interface compatibility | 2.6–5.5 V; DVDD should match MCU supply; custom DOUT/PD_SCK interface | 2.7–5.5 V; standard I2C-style interface; fixed address 0x2A; DVDD follows host logic | Both work at 3.3 V; NAU7802 fits the XIAO I2C pins and allows register diagnostics/calibration |
| Gain/input range | Channel A gain 64/128; at 5 V, ±40/±20 mV; channel B gain 32 | PGA 1–128; full scale ±0.5 × VREF/PGA | Both support a 1 mV/V bridge; final span/headroom still requires real tare/platform data |
| Output rate | 10 or 80 SPS | 10, 20, 40, 80, or 320 SPS | NAU7802 permits controlled latency/noise studies; 10 SPS is the initial low-noise baseline |
| Filtering/noise | Simultaneous 50/60 Hz rejection; 50 nV RMS at 10 SPS and 90 nV at 80 SPS, gain 128 | Simultaneous 50/60 Hz rejection; 50 nV RMS at 10 SPS and 150 nV at 80 SPS, gain 128 | Neither datasheet number predicts assembled performance; run NOISE-01 with Wi-Fi states |
| Calibration/diagnostics | Pin-selected channel/gain; saturation codes documented | Internal/system calibration modes, CAL_ERR, data-ready state, temperature sensor, register configuration | NAU7802 exposes more health and configuration evidence for fail-closed firmware |
| Library support | SparkFun/community libraries exist; simple timing-sensitive DOUT/PD_SCK driver | SparkFun maintains a dedicated register-aware Arduino library and hookup guide for SEN-15242 | NAU7802 exposes more configuration and fault evidence through the selected library path |
| Current sourcing on review date | SparkFun SEN-13879 reported in stock at USD 4.95 and the HX711 IC appeared in stock at LCSC. The old BOM URL incorrectly pointed at retired predecessor SEN-13230 | SEN-15242 reported in stock at USD 5.95; NAU7802SGI appeared in stock at DigiKey/LCSC | Availability does not disqualify HX711; select NAU7802 for interface/diagnostics and correct the malformed old sourcing record |
| Package/carrier suitability | SOP-16 only in the reviewed Avia document | NAU7802SGI SOP-16; Nuvoton also documents PDIP-16 and QFN-16 variants | SOP-16 is hand-assembly friendly and has current manufacturer documentation |

### Source basis

- **NAU7802 Rev. 2.6, p. 4:** 2.7–5.5 V, AVDD regulator, RMS noise, PGA, rejection, I2C, temperature range, package variants.
- **NAU7802 Rev. 2.6, p. 6:** pin table (VIN1±, SDIO, SCLK, DRDY, DVDD, AVDD/LDO).
- **NAU7802 Rev. 2.6, pp. 12–13:** DVDD/AVDD and I2C power/interface behavior.
- **NAU7802 Rev. 2.6, p. 24:** 16-pin bridge application circuit and optional 330 pF filter at 3.3 V AVDD.
- **NAU7802 Rev. 2.6, p. 28:** conversion-rate register values (10/20/40/80/320 SPS) and CAL_ERR.
- **NAU7802 Rev. 2.6, p. 38:** NAU7802SGI ordering code and SOP-16 package.
- **HX711 manufacturer datasheet, pp. 1–5:** supply, noise/rates, pinout, input range, serial timing, saturation, and reference application.

## Electrical and application-circuit checks

### Controller

Seeed's 113991054 product datasheet identifies the exact SKU, 21 mm × 17.8 mm board, 5 V VIN, 3.3 V output capability, 75 mA typical Wi-Fi-active consumption, and −40 to +85 °C operating range (pp. 1, 4–5). The manufacturer pinout workbook maps D4 to GPIO6/SDA and D5 to GPIO7/SCL. The prototype remains USB/SELV-only; the battery input/charger is unused.

### ADC module and logic

Power SEN-15242 from XIAO **3V3**, never 5 V while it is connected to the XIAO I2C pins. SparkFun's Qwiic Scale schematic warns that the module can accept 2.7–5.5 V but a Qwiic bus must not exceed 3.3 V. The board provides 2.2 kΩ I2C pull-ups (hookup guide, “I2C Jumper”). Do not add another strong pull-up bank during the module experiment.

The Nuvoton datasheet requires DVDD to be at least 0.3 V above the selected internal AVDD setting. With 3.3 V module power, configure **3.0 V nominal AVDD** rather than the SparkFun library's commonly shown 3.3 V setting. This also sits at the TAL220B's documented 3 V minimum excitation. Because both constraints meet at the boundary, actual bridge excitation must be measured and any low-voltage behavior recorded before PCB release. If 3.0 V cannot be maintained, the design must use a reviewed external/reference topology rather than silently violating either document.

Initial ADC settings:

- channel 1, PGA 128;
- internal RC oscillator;
- 10 SPS baseline for the documented 50/60 Hz rejection and lowest stated RMS noise;
- perform internal offset calibration after power-up and after sample-rate, gain, supply, or material temperature changes; reject data when `CAL_ERR` is set;
- discard at least the documented post-reset settling conversions before accepting stability;
- compare 80 SPS only as a separate latency/noise condition; do not merge its thresholds with 10 SPS data.

The carrier schematic follows Nuvoton Rev. 2.6 p. 24: 47 Ω series input resistors, 0.1 µF differential input filtering, 0.1 µF VBG bypass, 1 µF DVDD/AVDD capacitors, and the optional 330 pF PGA-output filter between VIN2P and VBG. Firmware must enable `PGA_CAP_EN`; SparkFun-specific jumpers were not reproduced. These values are schematic/static evidence, not measured performance.

### Load cell

The HT Sensor TAL220B sheet specifies for the family/order option reviewed:

- 5 kg selected capacity; aluminum parallel beam, IP65;
- safe overload 120% FS and ultimate overload 150% FS;
- rated output 1.0 ± 0.1 mV/V; excitation 3–10 VDC;
- combined error/non-linearity/hysteresis/repeatability each ±0.05% FS; creep ±0.1% FS over 3 minutes;
- −10 to +55 °C operating and −10 to +40 °C compensated range;
- nominal 200 mm four-wire cable: red E+, black E−, green S+, white S−.

SparkFun's SEN-14729 product record identifies the purchased 5 kg variant as 55 mm × 12.7 mm × 12.7 mm with two M5 through holes. Mechanical CAD must still trace the hole locations and mounting direction from the manufacturer drawing; the dimensions do not prove fixture fit. The project target of 10–35 °C is covered by the selected cell and electronics, but no thermal performance is inferred.

At 3.0 V excitation and 1.0 mV/V nominal rated output, the nominal full-load bridge span is 3.0 mV. This is comfortably below the NAU7802 gain-128 ratiometric full-scale magnitude of 0.5 × VREF/128 (about 11.7 mV for a 3.0 V reference). This is a datasheet calculation, not a measured headroom result; platform/bin dead load, offset, gain tolerance, wiring, and mechanical preload remain bench inputs.

## Availability, lifecycle, and cost snapshot

Observed 2026-08-20T00:24:42Z; web status is volatile and must be checked again immediately before ordering.

| Item | Source evidence | Unit estimate | Availability/lifecycle confidence |
|---|---|---:|---|
| Seeed 113991054 | Seeed product page metadata | USD 4.99 | “In stock” on manufacturer page; exact SKU established |
| SparkFun SEN-15242 | SparkFun product page metadata | USD 5.95 | “In stock” on manufacturer page; product and open hardware/library active |
| SparkFun SEN-14729 | SparkFun product page metadata | USD 15.50 | “In stock” on manufacturer page; some regional resellers report replacement/EOL, so re-check SparkFun/DigiKey before purchase |
| SparkFun CAB-17261 | SparkFun product/search record | USD 1.95 | Planning estimate; stock quantity not captured, so verify before order |
| NAU7802SGI carrier IC | Nuvoton product page plus DigiKey/LCSC listings | TBD—verify at schematic BOM quantity | Current Nuvoton product page/PLP and distributor listings found; no guarantee for future release |
| SparkFun SEN-13879 / HX711 (comparison only) | SparkFun current product page plus Avia datasheet/LCSC listing | USD 4.95 module; not selected | Module and IC reported in stock. Prior CSV mixed SEN-13879 with retired SEN-13230 URL; corrected here |

Selected electrical/cable planning subtotal: **USD 28.39** before USB supply, mechanical parts, shipping, tax, button, status indicator, carrier connector, and fabrication. The module-only subtotal excluding the optional jumper cable is USD 26.44. This supports but does not prove the USD 35–55 complete module-prototype target; all omitted items remain `TBD—verify`.

## Residual risks passed to schematic/firmware/mechanics

1. **Supply/filter margin:** 3.3 V DVDD and 3.0 V AVDD/excitation place the load cell at its minimum specified excitation. Measure excitation/noise; do not assume SparkFun defaults are optimal.
2. **RF coupling:** acquire separate Wi-Fi-off, idle, and active captures. Keep bridge leads short/paired and physically away from the XIAO antenna/USB cable.
3. **Single I2C address:** NAU7802 uses 0x2A. Record bus ownership and pull-ups in the schematic.
4. **Fault inference:** the ADC does not provide a complete load-cell disconnect guarantee. Firmware must combine saturation/stale/calibration/range behavior and later physical fault fixtures.
5. **Mechanical overload:** 120% safe overload is not permission to operate above 5 kg. A derated working load and stops require fixture geometry/tolerance evidence.
6. **Exact purchased cell:** SEN-14729 is the orderable SparkFun SKU, while the underlying HT Sensor ordering code is not fully printed on the storefront. Photograph/record markings only after a real unit exists and block substitutions from inheriting this validation.
7. **No prototype evidence:** no modules, fixture, instruments, photos, raw physical samples, or continuity checks are available in this repository. All bench rows remain unexecuted.

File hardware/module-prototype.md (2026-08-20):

# Planned module-prototype build and capture record

**Wiring revision:** MP-1.0<br>
**Status:** planned and statically reviewed; no physical assembly, continuity result, photograph, or bench data exists

## Exact module wiring

| From | To | Domain | Evidence |
|---|---|---|---|
| USB-C compliant 5 V SELV source | XIAO ESP32-C3 SKU 113991054 USB-C | 5 V input | Seeed 113991054 datasheet pp. 4–5 |
| XIAO `3V3` | SEN-15242 `3.3V/VCC` | 3.3 V logic supply | Seeed datasheet p. 5; SparkFun Qwiic Scale schematic p. 1 |
| XIAO `GND` | SEN-15242 `GND` | 0 V reference | Board pin labels/schematics |
| XIAO D4 / GPIO6 / SDA | SEN-15242 `SDA/SDIO` | 3.3 V open-drain I2C data | Seeed pinout workbook; NAU7802 Rev. 2.6 p. 6 |
| XIAO D5 / GPIO7 / SCL | SEN-15242 `SCL/SCLK` | 3.3 V open-drain I2C clock | Seeed pinout workbook; NAU7802 Rev. 2.6 p. 6 |
| SEN-15242 `E+` | TAL220B red | ~3.0 V excitation positive | TAL220B p. 1; SparkFun hookup guide “Load Cell Connections” |
| SEN-15242 `E-` | TAL220B black | excitation return | Same |
| SEN-15242 `A+` | TAL220B green | differential signal positive | Same |
| SEN-15242 `A-` | TAL220B white | differential signal negative | Same |

Use CAB-17261 or separately continuity-verified jumpers between the Qwiic connector and the XIAO header. Wire color is an assembly aid, never sufficient evidence. Record connector orientation and continuity on the actual units before applying power.

## Diagram

```text
USB 5 V SELV
    |
    v
Seeed XIAO ESP32-C3 (113991054)
  3V3  ------------------------------> 3V3/VCC
  GND  ------------------------------> GND
  D4 / GPIO6 / SDA ------------------> SDA       SparkFun Qwiic Scale
  D5 / GPIO7 / SCL ------------------> SCL       (SEN-15242 / NAU7802)
                                                    E+ ---> red   TAL220B
                                                    E- ---> black TAL220B
                                                    A+ <--- green TAL220B
                                                    A- <--- white TAL220B
```

This diagram is a planned wiring record, not a photograph or proof of assembly.

## Pre-power gate

Do not energize a build until all boxes can be completed against real units:

- [ ] Record XIAO, SEN-15242, and SEN-14729/TAL220B markings/revisions and purchase source.
- [ ] Build a rigid two-ended TAL220B fixture with the load direction from the manufacturer drawing, a separate force path, non-slip base, strain relief, and adjustable overload stops.
- [ ] Confirm electronics/cables are outside the force path and antenna clearance is unobstructed.
- [ ] Inspect for shorts/damage; identify XIAO 3V3/GND/D4/D5 by board orientation, not assumed header order.
- [ ] With power absent, continuity-check Qwiic GND/SDA/SCL/VCC and each load-cell lead to its terminal.
- [ ] Confirm no 5 V pull-up reaches SDA/SCL.
- [ ] First power from a current-limited USB source; record instrument make/model/settings and observed USB 5 V, 3V3, AVDD/E+, and current.
- [ ] While powered and current-limited, configure NAU7802 AVDD to 3.0 V nominal, channel 1, gain 128, 10 SPS; check calibration completion and `CAL_ERR`.
- [ ] Verify signed response with a small safe load. Correct S+/S− wiring if polarity is reversed; do not hide an unexplained reversal in software.
- [ ] Complete the metadata required by `docs/verification-plan.md` before calling any capture bench evidence.

No item above is checked in this revision because no physical hardware is available.

## Raw capture workflow

The capture tool accepts an integer raw code per line, `elapsed_s,raw_code`, or JSON lines. A future serial stream can be recorded without dropping provenance:

```bash
pio device monitor --raw | \
  python3 scripts/capture_samples.py evidence/raw/noise-wifi-off.csv \
    --condition wifi-off \
    --trial zero-01 \
    --metadata hardware_revision=MP-1.0 \
    --metadata controller_sku=113991054 \
    --metadata adc_sku=SEN-15242 \
    --metadata load_cell_sku=SEN-14729 \
    --metadata firmware_revision=${FIRMWARE_REVISION} \
    --metadata fixture_revision=${FIXTURE_REVISION} \
    --metadata adc_rate_sps=10 \
    --metadata pga=128 \
    --metadata ambient_c=${MEASURED_AMBIENT_C} \
    --metadata instrument=${INSTRUMENT_AND_ASSET_ID} \
    --metadata operator=${OPERATOR} \
    --metadata usb_supply=${USB_SUPPLY_AND_ASSET_ID}
```

The CSV and `.meta.json` sidecar are both evidence. The capture tool writes through temporary files, replaces the CSV/sidecar fail-closed, and records the CSV SHA-256 in the sidecar. Never edit raw rows to improve a result; append a new trial and document anomalies.

Analyze without invented stability thresholds:

```bash
python3 scripts/analyze_capture.py evidence/raw/noise-wifi-off.csv \
  --evidence-stage bench \
  --window-samples 20 \
  --output evidence/reports/noise-wifi-off.json
```

For `--evidence-stage bench`, the analyzer verifies the sidecar filename, sample count, SHA-256, signed 24-bit format, zero ignored input lines, and non-placeholder setup metadata before producing a report. The firmware capture stream must therefore contain only supported sample records; do not hide diagnostics with `--ignore-unparseable`. This computes noise, drift, outlier, repeatability, and rolling-window facts but deliberately reports stability as `not_evaluated_thresholds_missing`.

After NOISE-01 establishes reviewed raw-code thresholds, provide both together:

```bash
python3 scripts/analyze_capture.py evidence/raw/noise-wifi-off.csv \
  --evidence-stage bench \
  --window-samples 20 \
  --max-band <characterized-P95-minus-P5-codes> \
  --max-abs-slope <characterized-codes-per-second> \
  --output evidence/reports/noise-wifi-off.json
```

A generated report is not sufficient bench evidence unless its raw capture, sidecar, setup, revisions, instruments, ambient, fixture, and procedure are also present.

## Synthetic verification now available

The tracked `tests/fixtures/synthetic_capture.csv` contains two zero and two reference trials. It is intentionally synthetic and exercises the same metrics and threshold gating:

```bash
python3 scripts/analyze_capture.py tests/fixtures/synthetic_capture.csv \
  --evidence-stage synthetic-software \
  --window-samples 10 --max-band 4 --max-abs-slope 5 \
  --output /tmp/synthetic-report.json
python3 -m unittest discover -s tests -v
```

These commands verify software behavior only. They do not characterize NAU7802, TAL220B, Wi-Fi interaction, mechanics, or the module prototype.

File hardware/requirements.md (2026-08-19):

# Hardware and system requirements

**Requirements version:** 1.0
**Baseline date:** 2026-08-19
**Status:** Reviewed measurable targets; implementation and physical verification pending

The original target list was reviewed for ambiguity and testability before component selection or schematic capture. Requirement IDs remain stable for traceability. Rationale for material wording changes appears at the end.

## Electrical

| ID | Requirement | Verification |
|---|---|---|
| E-01 | Operate only from a compliant USB 5 V SELV source; include no mains interface or onboard battery charging. | Schematic/power-tree review; input inspection; bring-up checklist. |
| E-02 | Design for normal input current below 500 mA. Before release, measure and report steady and peak current for startup, idle sampling, active Wi-Fi, calibration, and status-indicator extremes; do not claim compliance from estimates alone. | Current-limited first power plus recorded instrument data. |
| E-03 | Support exactly one full-bridge, 4-wire load cell through a keyed or unambiguously labeled connector whose mating half, orientation, and E+/E-/S+/S- mapping are documented. | Datasheet/pinout review; continuity record; schematic/PCB inspection. |
| E-04 | Detect stale, open/disconnected, persistently out-of-range, and saturated sensor data and withhold count in each state. | Synthetic fixtures plus DISC-01 and SAT-01. |
| E-05 | Provide a physical tare/calibrate/recovery input and text/icon/color-capable local status behavior that remains usable without Internet or LAN. | Firmware target test plus WIFI-01 and accessibility review. |
| E-06 | Expose manufacturer-supported USB/UART recovery and accessible, labeled test points for USB input, each regulated rail, ground, ADC clock/data, bridge excitation, and safe bridge-input observation. | Schematic/PCB review and bring-up access inspection. |
| E-07 | Carrier schematic/PCB must pass KiCad ERC/DRC and applicable analyzers with zero unexplained violations; every narrow waiver is tracked with rationale and scope. | Recorded tool reports from exact source revision. |

## Measurement

| ID | Requirement | Verification |
|---|---|---|
| M-01 | The initial candidate full-scale load is 5 kg. The released safe working load must be explicitly derated from the selected load-cell datasheet, fixture geometry, fasteners, and overload-stop evidence. | Datasheet/fixture calculation plus controlled OVR-01 evidence. |
| M-02 | Tare must include the intended base-independent platform/bin dead load with documented headroom from ADC and mechanical limits. Tare is accepted only while stable and healthy. | Datasheet/span analysis; tare misuse tests; bench headroom record. |
| M-03 | Known-count calibration requires at least 10 identical samples and records sample count, stable net mass, unit mass, uncertainty/provisional state, tare/profile identity, active parameters, schema version, and time context. | Persistence/schema tests and COUNT-01 records. |
| M-04 | Publish stable/unstable and all no-count fault states. Never silently convert unstable, stale, disconnected, saturated, overload-indicated, below-tare, or invalid-calibration data into an authoritative count. | Golden synthetic tests, protocol/UI tests, physical fault tests. |
| M-05 | Initial repeatability target: for uniform parts whose calibrated unit mass is at least 20 times the measured stable P95-P5 noise band, stable estimates are within ±1 piece in the declared bench trial set. Report uncertainty and all misses; this target is pending REP-01/COUNT-01 evidence. | NOISE-01, REP-01, COUNT-01 with raw data. |
| M-06 | Characterize and publish zero/span noise, warm-up drift, at least 10-minute creep, repeatability, hysteresis, off-center loading, cable disturbance, and Wi-Fi activity effects using the procedures in `docs/verification-plan.md`. | Raw bench data and generated summary. |
| M-07 | Detect configured overload/out-of-range indication and withhold count. Mechanical overload stops remain mandatory; firmware indication is not structural protection. | Synthetic threshold tests and safe OVR-01. |
| M-08 | Count uses the reviewed tare/unit-mass/rounding/uncertainty model in `docs/architecture.md`; exact half ties round away from zero and negative inventory counts are never emitted. | Deterministic unit/golden tests. |
| M-09 | Minimum usable unit mass is `max(20 * measured stable noise band, characterized resolution floor)`; lighter/variable parts are rejected or clearly marked unsuitable rather than assigned false precision. | Calibration validation tests and COUNT-01. |

## Mechanical

| ID | Requirement | Verification |
|---|---|---|
| K-01 | Target a prototype base no larger than 180 mm × 140 mm; publish actual overall and bin-contact dimensions when CAD exists. | CAD measurement and assembly drawing. |
| K-02 | Force path runs only through bin/top plate, sensing/fixed load-cell mounts, rigid base, and feet—not PCB, connectors, enclosure walls, or cable. | CAD review and physical load-path inspection. |
| K-03 | Use replaceable common metric fasteners where compatible with the selected load cell; publish editable CAD, fastener schedule, and dimensioned assembly drawings. | Source/archive inspection and assembly trial. |
| K-04 | Provide non-slip feet, cable strain relief, and openings/bend radii that do not pinch or load the sensor cable. | CAD/assembly inspection plus CABLE-01. |
| K-05 | Preserve controller manufacturer antenna keepout from copper, components, load-cell metal, fasteners, cables, and enclosure features; carrier constraints must be enforceable rule areas rather than notes alone. | Datasheet citation, PCB keepout audit, mechanical clearance inspection. |
| K-06 | Provide adjustable or dimensionally controlled overload stops that engage before damaging cell deflection while not contacting during validated normal loading. | Drawing/tolerance review and safe OVR-01/post-test checks. |

## Connectivity and data

| ID | Requirement | Verification |
|---|---|---|
| C-01 | Physical tare/recovery/status and ongoing measurement remain usable when Internet and LAN are unavailable; no cloud account/service is required. | WIFI-01 and target behavior test. |
| C-02 | First-run setup is local and requires deliberate physical presence for credential establishment/reset. | Provisioning and security tests. |
| C-03 | API uses versioned `/api/v1`; mutating operations require an authenticated per-device session after provisioning, request validation, and idempotency/replay controls. | Protocol compatibility/security tests. |
| C-04 | Device/app recover from Wi-Fi interruption and event sequence gaps without losing valid profiles/calibration or inventing history. | WIFI-01, persistence and mock-device E2E tests. |
| C-05 | Export profiles/history as versioned JSON and counts/history as CSV with explicit units/corrections; credentials, session tokens, and Wi-Fi settings are excluded. | Export/import schema and secret-scanning tests. |
| C-06 | Retention limits are bounded and documented; users can preview import, clear history with confirmation, and distinguish device-authoritative data from browser cache. | Persistence tests and app E2E/accessibility checks. |
| C-07 | Stable/unstable, disconnected, saturated, overload, stale, authentication, and incompatible-version states are conveyed by text/icon and not color alone. | Automated accessibility checks and component/E2E tests. |

## Environmental and use limits

| ID | Requirement | Verification |
|---|---|---|
| V-01 | Indoor dry workshop/office use only; no condensation, washdown, outdoor, or hazardous-location claim. | Documentation/release review. |
| V-02 | Initial validated-use target is 10–35 °C non-condensing. Selected parts must have manufacturer ratings covering a wider margin; bench evidence must record ambient temperature rather than extrapolate. | Datasheet audit and bench logs. |
| V-03 | Product and UI state that it is not legal-for-trade or certified for commerce, medical, food-safety, hazardous-process, life-safety, or structural use. | Documentation/UI/release string checks. |
| V-04 | App warns that mixed, corroded, wet, contaminated, damaged, or materially variable parts may not count reliably. | Content and accessibility tests. |

## Cost and reproducibility

| ID | Requirement | Verification |
|---|---|---|
| R-01 | Module-prototype planning target is USD $35–$55 excluding user-printed enclosure. Every estimate has source/date or `TBD—verify`; re-price before ordering. | Timestamped sourcing record and BOM review. |
| R-02 | Target total under USD $75 including ordinary cables/fasteners and excluding phone/computer/tools; separately list non-schematic items and assumptions. | Consolidated electrical/non-electrical cost rollup. |
| R-03 | Before pre-fab signoff, every populated electrical BOM line has Manufacturer, exact MPN, package/footprint, supplier/source, datasheet, and validation/BOM note in KiCad symbol properties. | Schematic-backed BOM and datasheet coverage audit. |
| R-04 | KiCad schematic properties are electrical BOM source of truth; tracked `bom/bom.csv` is exported from them. Preliminary planning CSV never becomes competing truth. | Reproducible export/diff check. |
| R-05 | Release includes editable KiCad/mechanical CAD, firmware/app source, pinned build instructions, license notices, generated fabrication outputs, checksums, and a manifest tying compatible revisions. | Tagged archive and integrity validation. |
| R-06 | Evidence labels distinguish documentation/static analysis, datasheet review, simulation, software tests, target compile, bench testing, and field testing. | PR/release report validation. |

## Review rationale and changes from initial targets

| Change | Rationale |
|---|---|
| E-02 now names operating modes and requires measured peak/steady evidence. | “Below 500 mA” was not testable without modes, instrumentation, and an explicit no-estimate rule. |
| E-03/E-06 now require connector orientation, mating half, and named test points. | Generic “support” and “expose” language could pass while remaining unbuildable or unsafe to probe. |
| M-02/M-03 now define acceptance gates and stored metadata. | Tare/calibration needed deterministic rejection, traceability, and corruption behavior. |
| M-05 defines the noise band as stable P95-P5 and ties the target to a declared trial set. | “Noise band” and “verified by bench trials” were ambiguous and could hide cherry-picked results. |
| M-08/M-09 added. | Count rounding, uncertainty, negative values, and minimum usable mass were previously architecture prose rather than requirements. |
| K-06 added. | “Stops mandatory” lacked a testable normal-clearance/damaging-deflection relationship. |
| C-02/C-03/C-07 tightened. | Local-first did not by itself define physical presence, authenticated mutation, event/auth fault accessibility, or replay behavior. |
| R-06 added. | Prevents static/synthetic evidence from being reported as physical prototype testing. |
| All physical verification references named plan IDs. | Makes later evidence reproducible and exposes every pending gap. |

## Current evidence

Only this reviewable baseline and its automated contract checks exist. Component selection, datasheet verification, electrical design, software implementation, simulation, fabrication, bench characterization, and field testing are pending their dependency-ordered issues.

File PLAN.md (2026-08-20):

# Parts Tally implementation plan

## Scope

Build a reproducible, local-first parts-counting platform in two increments:

1. **Module prototype:** XIAO ESP32-C3 + external bridge-ADC breakout + 5 kg bar load cell, mounted under a mechanically isolated platform. This validates noise, creep, calibration, filtering, and the app workflow before PCB commitment.
2. **Carrier-board revision:** an editable KiCad project that hosts the chosen controller/module, bridge ADC, protected load-cell connector, USB/power interface as appropriate, button, status LED, programming/debug access, and test points.

## Architecture

The versioned baseline is [docs/architecture.md](docs/architecture.md), with measurable requirements in [hardware/requirements.md](hardware/requirements.md), logical prototype/carrier interfaces in [hardware/interfaces.md](hardware/interfaces.md), planned evidence in [docs/verification-plan.md](docs/verification-plan.md), and residual risks in [docs/risk-register.md](docs/risk-register.md). `docs/architecture-contract.json` is checked in CI to prevent drift in safety scope, dependency gates, no-count states, test IDs, and evidence labels.

### Measurement path

`load cell bridge -> 24-bit ADC -> ESP32-C3 sampler -> outlier/filter/stability pipeline -> calibrated mass -> count estimate + uncertainty`

Calibration records include empty-bin tare, sample count, sample net mass, derived unit mass, timestamp, and optional tolerance. Count output must be withheld or marked unstable when drift/noise exceeds configured limits.

### Device services

- Non-blocking measurement task and watchdog-safe state machine
- Persistent configuration and profile storage with schema versioning
- Temporary setup AP for first-run provisioning; local LAN API thereafter
- Versioned JSON command/event protocol over HTTP and WebSocket
- Physical button actions available even when networking is unavailable
- Signed/hash-checked firmware artifacts and documented USB recovery path

### Companion app

- TypeScript PWA built with Vite and a small accessible component layer
- Responsive calibration wizard, live stable/unstable indication, profile list, thresholds, history, and import/export
- IndexedDB or browser storage only for app preferences/cache; authoritative device records are explicitly identified
- No mandatory backend, account, telemetry, or Internet dependency

## Technology choices

- **ESP32-C3 / XIAO ESP32C3:** inexpensive Wi-Fi/BLE-capable RISC-V MCU module with USB development path and a small module-prototype footprint.
- **PlatformIO + Arduino framework initially:** fast module bring-up and host-native tests; hardware-facing code remains behind interfaces so ESP-IDF migration is possible.
- **SparkFun SEN-15242 / NAU7802 selected:** 3.3 V I2C module with register calibration/diagnostics; initial 10 SPS/PGA128 and 3.0 V AVDD settings. HX711/SEN-13879 remains a documented comparison, not an additional requirement.
- **KiCad:** editable schematic/PCB, native symbol properties as the BOM source of truth, ERC/DRC evidence, and fabrication exports.
- **TypeScript/Vite PWA:** phone and desktop access without app-store distribution or cloud hosting.
- **JSON/CSV:** human-portable local backups with explicit schema versions.

## Planned repository layout

```text
app/                    PWA source and tests
bom/                    preliminary planning BOM, then exported bom.csv
config/                 example non-secret device/app configuration
 docs/                  protocol, bring-up, assembly, verification
firmware/               PlatformIO project and native tests
hardware/
  kicad/                real .kicad_pro/.kicad_sch/.kicad_pcb sources
  mechanical/           printable/measured fixture sources
  README.md
  requirements.md
```

No fake KiCad source files will be committed merely to satisfy a filename checklist.

## Milestones and dependency order

1. **Requirements and risk review**
   - Define load range, count accuracy targets, stability criteria, overload strategy, local networking, and cost gate.
2. **Datasheet-backed selection and module experiment**
   - Validate controller, bridge ADC, load cell, interfaces, voltage levels, mechanics, lifecycle, and availability.
3. **Schematic and BOM**
   - Create real KiCad sources, populate manufacturer/MPN fields, complete power/protection/debug/test-point design, run ERC, and export `bom/bom.csv`.
4. **Firmware and protocol**
   - Implement measurement pipeline, calibration, persistence, provisioning/API, update/recovery, native tests, and target build.
5. **Companion PWA**
   - Build setup/calibration/count/history/export workflows with accessible keyboard/screen-reader/touch behavior and mocked-device tests.
6. **PCB and mechanical integration**
   - Define outline/mounting, preserve RF keepout, route analog bridge signals carefully, provide ground strategy/testability, run DRC, and publish renders marked as renders.
7. **Bring-up and release**
   - Assembly, measured test procedure, troubleshooting, real evidence, Gerbers/drills/CPL as applicable, schematic PDF, validated BOM, release archives, and licenses.

## Testing strategy

### Static analysis

- KiCad ERC and DRC, with every waiver documented
- KiCad schematic/PCB analyzers and cross-domain checks
- BOM coverage validation against schematic properties and manufacturer datasheets
- Firmware formatting/static analysis and TypeScript lint/type checks

### Simulation and software tests

- Host-native tests for filtering, stability detection, calibration, count rounding/uncertainty, persistence migrations, and protocol parsing
- Golden vectors with synthetic drift, vibration, overload, and disconnect cases
- PWA unit/component tests and mock-device end-to-end flows
- Protocol schema compatibility tests

### Bench testing (only after hardware exists)

- Repeatability and hysteresis at multiple loads
- Warm-up drift, creep over time, off-center loading, cable disturbance, and power-cycle recovery
- Known-count trials across several uniform part types
- Wi-Fi loss/recovery and local-only behavior
- Overload-stop and enclosure load-path inspection

Field use is separate from bench validation and will not be claimed until performed.

## Packaging and distribution

- Firmware: versioned binary plus source-build instructions and hashes
- PWA: static bundle served by the device or installable from a local host; no mandatory public service
- Hardware: tagged KiCad sources, schematic PDF, Gerber/drill archive, CPL if assembly is supported, schematic-exported BOM, assembly drawings, and enclosure source
- Release archive: licenses and a manifest tying firmware, app, and board revisions together

## Risks and mitigations

This summary is navigational. The versioned [risk register](docs/risk-register.md) is authoritative for risk IDs, owners, verification stages, and residual status.

| Risk | Mitigation |
|---|---|
| Unit-mass variation makes counts misleading | Report uncertainty, require known-count calibration, allow correction, document unsuitable parts |
| Load-cell creep, vibration, or off-center force | Stability gate, filtering, warm-up guidance, rigid fixture, overload stops, bench characterization |
| Analog noise from Wi-Fi/USB power | Short differential wiring, quiet supply/layout, ground strategy, sampling schedule, compare ADC candidates |
| Platform load reaches PCB | Separate mechanical load path; PCB only senses/connects |
| Lost local credentials or bad update | Physical recovery/provisioning action, USB flashing path, versioned config backups |
| Sourcing changes | Manufacturer/MPN properties, datasheets, lifecycle/availability check before each release |
| Scope expansion into warehouse software | Keep MVP single-device, local profiles/history, no purchasing/ERP/cloud service |

## Explicit non-goals

- Certified measurement or sale-by-weight
- Mixed-part recognition, camera classification, or AI-based counting
- Multi-tenant cloud fleet management
- Battery charging, mains power, or unattended safety control
- Production claims before real prototypes and measured evidence

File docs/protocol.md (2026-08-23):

# Parts Tally local protocol v1

**Status:** implemented in firmware and native/contract-tested; target networking, NVS, button,
ADC, and WebSocket behavior still require physical verification.

The device exposes a direct AP on every boot and serves local UTF-8 JSON over HTTP under
`/api/v1`; WebSocket events use port 81 at `/api/v1/events`. If stored Wi-Fi credentials exist,
the target also starts an asynchronous STA association without taking down the AP. LAN failure
therefore does not remove the direct API. No Internet service is required. Transport is plaintext,
so a trusted local network is required and an on-path observer can see bearer traffic.

## Sessions and provisioning

Holding the dedicated GPIO3 button at power-up opens a five-minute physical-presence setup
session. `GET /api/v1/setup/session` requires no bearer but returns the setup token only while that
session is active. A setup token is accepted only under `/api/v1/setup/*`; an authenticated token is
accepted only on normal API routes.

`POST /api/v1/setup/provision` requires the setup bearer, exact configured Origin,
`application/json`, and an idempotency key. Its envelope includes `wifiSsid`, `wifiPassword`, and a
new `deviceSecret` of 16–128 characters. An empty SSID with an empty password selects direct-only
mode. Success atomically persists credentials, invalidates setup scope, starts STA when an SSID was
provided, and returns a fresh five-minute authenticated token.

`POST /api/v1/session` requires no prior bearer or idempotency key, but does require exact Origin,
`application/json`, the standard command envelope, and the persisted `deviceSecret`. Success returns
a fresh entropy-generated five-minute authenticated token. Wrong credentials return 401. Target
tokens come from `esp_random`; native tests inject deterministic token generation.

All other routes require an unexpired authenticated bearer. Mutations also require exact Origin,
`application/json`, a body no larger than 8192 bytes, and an `Idempotency-Key` of 1–128 characters.
The last 64 successful/client-error mutation results are replayed; server failures are not cached,
so the same idempotency key can retry after storage recovery. Reuse for different request content
returns 409.

## Routes

- `GET /api/v1/status`
- `GET /api/v1/profiles`
- `GET /api/v1/history?after=SEQUENCE&limit=COUNT` (`after` is an unsigned 64-bit decimal;
  `limit` defaults to 50 and must be 1–100; each parameter may appear at most once and no other
  query parameters are accepted)
- `GET /api/v1/export`
- `POST /api/v1/actions/tare`
- `POST /api/v1/actions/calibrate` (`knownCount` is 10–1,000,000; a fresh device with no scale
  factor also requires finite positive `knownSampleMassGrams` and derives its scale from that mass)
- `POST /api/v1/profiles`
- `PATCH /api/v1/profiles/{id}`
- `DELETE /api/v1/profiles/{id}`
- `POST /api/v1/counts/{eventId}/correction` (requires profile, bounded count, and a nonempty
  reason of at most 200 characters)
- `POST /api/v1/import/preview`
- `POST /api/v1/import/apply` (requires the exact preview token, unchanged import payload, same
  authenticated session, and use within 30 seconds)
- `DELETE /api/v1/history` (requires exact `CLEAR HISTORY` confirmation)

Mutation bodies contain `protocol`, `requestId`, and `deviceId`. Route-body schemas are in
`docs/schemas/api-v1`; checked fixtures cover every route family. Export/import schema v3 preserves
device name, complete profile calibration fields, per-profile thresholds, and up to 256 history
entries. Every history entry has a unique `eventId`; a correction has its own event ID and stores
the referenced count event in `relatedEventId`. Import validates those references, profile
ownership, and uniqueness. It rejects secret-bearing fields at any depth and keeps the device's
current credentials.

Wi-Fi SSID/password and device secret persist in ESP32 NVS but are absent from status, normal logs,
JSON export/import backup, and CSV data. NVS persistence is not encryption or a secure element: an
attacker with physical access and flash-extraction capability may recover credentials. Session
tokens are short-lived and not persisted.

## Measurements, events, and local button

No-count states are `uncalibrated`, `unstable`, `stale`, `disconnected`, `saturated`,
`overload_indicated`, `below_tare`, `calibration_invalid`, and `uncertainty_excessive`. In each,
`estimatedCount` and `uncertaintyPieces` are `null`.

WebSocket clients connect to the exact `/api/v1/events` path without credentials in the URL, then
must immediately send `{"type":"authenticate","token":"..."}`. Authorization is tracked per
client; setup tokens never authorize streaming, and expired or superseded authenticated sessions
receive no broadcasts.

The target broadcasts sequenced `measurement.updated` events at no more than 4 Hz and emits
`fault.raised` or `status.updated` on state transitions. Other defined event types are
`measurement.stability_changed`, `profile.changed`, `threshold.changed`, `fault.cleared`, and
`device.restarting`. A sequence gap makes clients refresh status, profiles, and their history cursor.
Stable count changes create bounded, persisted count-history events; corrections require both an
existing profile and the event ID of a count event owned by that same profile.

A short release of GPIO3 requests a local tare. Factory reset is recognized only when GPIO3 was
already held at power-up and remains held for ten seconds; releasing cancels it. Later long presses
do not erase storage. Reset erases NVS and restarts. These behaviors are host-tested state-machine
logic, not a claim of measured physical timing.

The device is USB 5 V SELV-only, not legal-for-trade, and not suitable for safety-critical use.

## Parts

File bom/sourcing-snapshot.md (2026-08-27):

# Sourcing snapshot — 2026-08-22 UTC

This file records what was actually checked while preparing the issue #3 schematic. It is not a quotation, purchase order, lifecycle guarantee, or fabrication status.

## Live LCSC product-page observations

The following public product pages were fetched on 2026-08-21–22 UTC. The first published price break and displayed stock were copied into the KiCad symbol properties and exported BOM.

| LCSC | MPN | First price break | Displayed stock | Source |
|---|---|---:|---:|---|
| C5180029 | NAU7802SGI | 1 @ $1.7781 | 1,427 | https://www.lcsc.com/product-detail/C5180029.html |
| C3020560 | USB4105-GF-A | 1 @ $1.0659 | 926 | https://www.lcsc.com/product-detail/C3020560.html |
| C189895 | SM04B-GHS-TB(LF)(SN) | 1 @ $1.1182 | **0** | https://www.lcsc.com/product-detail/C189895.html |
| C17313 | MF-MSMF050-2 | 10 @ $0.0668 each | 47,400 | https://www.lcsc.com/product-detail/C17313.html |
| C15759 | B140-13-F | 5 @ $0.0856 each | 59,660 | https://www.lcsc.com/product-detail/C15759.html |
| C107696 | RC0603FR-07220RL | 100 @ $0.0061 each | 417,400 | https://www.lcsc.com/product-detail/C107696.html |
| C3335156 | TSW-104-07-G-S | 1 @ $0.6472 | 337 | https://www.lcsc.com/product-detail/C3335156.html |
| C97949 | GRM31CR61A106KA01L | 1 @ $0.3351 | 22 | https://www.lcsc.com/product-detail/C97949.html |
| C5555828 | ASMT-YTC7-0AA02 | 1 @ $1.7772 | 79 overseas stock | https://jlcpcb.com/partdetail/BroadcomLimited-ASMT_YTC70AA02/C5555828 |

J2's preferred LCSC listing was out of stock and is explicitly flagged in the schematic/BOM. An alternate source must be verified before ordering.

The original draft selected ASMT-YTC2-0AA02, which a current authorized-distributor lookup identified as obsolete. It was replaced with ASMT-YTC7-0AA02. Broadcom AV02-3819EN confirms the same 3.0 × 2.8 mm PLCC-6 geometry and exact lead sequence used by the KiCad symbol/footprint; JLCPCB listed C5555828 as an in-stock extended part on 2026-08-22 UTC.

## Other lines

DigiKey and manufacturer pages were discoverable, but no distributor API credentials were available in the scheduled environment and DigiKey blocked automated price/stock retrieval. Those BOM costs are clearly marked as public-listing/search **estimates**, and stock is marked unverified rather than invented. Re-check all such lines before ordering. The Seeed module price is the public direct-store list price observed during this review.

`bom/non-schematic-items.csv` deliberately uses `TBD` wherever an enclosure, harness, supply, or hardware choice has not been sourced. No stock, price, assembly, prototype, or fabrication result is claimed for those items.

## Layout-milestone public-search refresh — 2026-08-26T00:25:19Z

Public search results were refreshed for the four layout-critical assembled parts. Search-index snippets are transient and sometimes disagree, so this was not treated as an API-backed quote and the dated quantity-one observations in KiCad were not overwritten:

- C3020560 / USB4105-GF-A: the exact LCSC result reported “in stock” and “from $0.6043”; another indexed URL reported $0.6584. No exact stock count was exposed.
- C5180029 / NAU7802SGI: the exact LCSC result reported “in stock” and “from $0.8277”; a category URL reported $0.8792. No exact stock count was exposed.
- C189895 / SM04B-GHS-TB(LF)(SN): exact and category results both reported “in stock,” but indexed prices conflicted ($1.0754 versus $0.2887). The BOM retains its dated out-of-stock observation and requires checkout-time verification rather than converting an unstable snippet into a sourcing claim.
- 113991054 / XIAO ESP32-C3: the manufacturer page reported USD $4.99 and “1+ in stock”; LCSC still mapped the MPN to C18212168 without exposing a defensible quantity/price in the result.

The local LCSC resolver was not used because it required accepting bulk-catalog terms on the user's behalf. Current public observations must still be rechecked immediately before ordering.

## Release-candidate public-search refresh — 2026-08-27 UTC

The release run again declined the bulk catalog because accepting third-party catalog terms was not authorized. Public search results were used only to recheck exact mappings:

- **C189895 / JST SM04B-GHS-TB(LF)(SN):** the exact LCSC result said “Out of Stock,” while another indexed LCSC URL called the same MPN “In-stock”; the JLCPCB result confirmed the exact extended-part mapping but exposed no reliable quantity. This remains an unresolved checkout-time blocker for turnkey PCBA, not a basis for substitution.
- **C5180029 / Nuvoton NAU7802SGI:** the exact mapping resolved, but snippets mixed current and alternate C2614351 pages and conflicting prices/quantities. No BOM stock/price was updated.
- **C3020560 / GCT USB4105-GF-A:** the exact mapping resolved and public snippets reported stock, but counts/prices varied. No API-grade quote was available and no BOM stock/price was updated.

No stock, price, lifecycle, purchase, or fabrication claim is inferred from this refresh. Recheck every line through the chosen supplier immediately before ordering and review all blank JLCPCB BOM identifiers as user-sourced parts.

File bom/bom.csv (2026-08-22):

Reference | Qty | Value | Footprint | Manufacturer | MPN | Supplier | Supplier PN | Estimated Unit Cost USD | Extended Cost USD | Price Observed UTC | Stock Observed | Cost Basis | Datasheet | BOM Comments
C1 | 1 | 4.7uF 10V X5R | Capacitor_SMD:C_1206_3216Metric | Murata | GRM31CR61A475KA01L | DigiKey | 490-3902-1-ND | 0.20 | 0.2000 | 2026-08-21 | Not verified — distributor API credentials unavailable | Public distributor listing/search estimate; not a quote | https://www.murata.com/en-global/products/capacitor/mlcc/overview/lineup | Protected 5 V bulk capacitor; total carrier input capacitance remains below 10 uF nominal.
C2,C4,C10 | 3 | 100nF 50V X7R | Capacitor_SMD:C_0603_1608Metric | Murata | GRM188R71H104KA93D | DigiKey | 490-1519-1-ND | 0.02 | 0.0600 | 2026-08-21 | Not verified — distributor API credentials unavailable | Public distributor listing/search estimate; not a quote | https://search.murata.co.jp/Ceramy/image/img/A01X/G101/ENG/GRM188R71H104KA93-01.pdf | High-frequency bypass on protected 5 V rail. | High-frequency bypass on the 3V3 rail. | Button hardware debounce; firmware still applies bounded debounce and long-press timing.
C3 | 1 | 10uF 10V X5R | Capacitor_SMD:C_1206_3216Metric | Murata | GRM31CR61A106KA01L | LCSC | C97949 | 0.3351 | 0.3351 | 2026-08-21 | 22 | 1 @ $0.3351 | https://search.murata.co.jp/Ceramy/image/img/A01X/G101/ENG/GRM31CR61A106KA01-01.pdf | Local bulk capacitor on the XIAO 3V3 output; regulator is on the module.
C5,C6 | 2 | 1uF 16V X7R | Capacitor_SMD:C_0603_1608Metric | Murata | GRM188R71C105KA12D | DigiKey | TBD—verify before order | 0.08 | 0.1600 | 2026-08-21 | Not verified — distributor API credentials unavailable | Public distributor listing/search estimate; not a quote | https://www.murata.com/en-global/products/capacitor/mlcc/overview/lineup | DVDD local bypass; Nuvoton Rev. 2.6 p.24. | AVDD/LDO local bypass; low-ESR, Nuvoton Rev. 2.6 pp.6,24.
C7,C8 | 2 | 100nF 50V X7R | Capacitor_SMD:C_0603_1608Metric | Murata | GRM188R71H104KA93D | DigiKey | TBD—verify before order | 0.02 | 0.0400 | 2026-08-21 | Not verified — distributor API credentials unavailable | Public distributor listing/search estimate; not a quote | https://www.murata.com/en-global/products/capacitor/mlcc/overview/lineup | VBG bypass per Nuvoton Rev. 2.6 p.24. | Differential bridge-input filter after the two 47 Ω series resistors.
C9 | 1 | 330pF 50V C0G | Capacitor_SMD:C_0603_1608Metric | Murata | GRM1885C1H331JA01D | DigiKey | TBD—verify before order | 0.05 | 0.0500 | 2026-08-21 | Not verified — distributor API credentials unavailable | Public distributor listing/search estimate; not a quote | https://www.murata.com/en-global/products/capacitor/mlcc/overview/lineup | Optional PGA-output Cfilter between VIN2P and VBG; enable PGA_CAP_EN; Nuvoton p.24.
C11 | 1 | 1uF 16V X7R | Capacitor_SMD:C_0603_1608Metric | Murata | GRM188R71C105KA12D | DigiKey | 490-3897-1-ND | 0.08 | 0.0800 | 2026-08-21 | Not verified — distributor API credentials unavailable | Public distributor listing/search estimate; not a quote | https://www.murata.com/en-global/products/capacitor/mlcc/overview/lineup | Local VBUS input bypass; total nominal input capacitance remains below 10 uF.
D1 | 1 | SMF5.0A | Diode_SMD:D_SOD-123F | Littelfuse | SMF5.0A | DigiKey | F8583CT-ND | 0.30 | 0.3000 | 2026-08-21 | Not verified — distributor API credentials unavailable | Public distributor listing/search estimate; not a quote | https://www.littelfuse.com/assetdocs/tvs-diodes-smf-datasheet?assetguid=7eb8a5b6-bdd0-4561-8f19-0c3cc6f9b2af | VBUS transient clamp; place at J1 with short return to ground.
D2 | 1 | B140-13-F | Diode_SMD:D_SMA | Diodes Incorporated | B140-13-F | LCSC | C15759 | 0.0856 | 0.0856 | 2026-08-21 | 59660 | 5 @ $0.0856 each | https://www.diodes.com/assets/Datasheets/ds13002.pdf | Series reverse-current block prevents carrier USB input from being back-fed by U1 USB.
D3 | 1 | RGB STATUS | LED_SMD:LED_Avago_PLCC6_3x2.8mm | Broadcom Limited | ASMT-YTC7-0AA02 | JLCPCB | C5555828 | 1.7772 | 1.7772 | 2026-08-22 | 79 | 1 @ $1.7772; JLCPCB extended part | https://docs.broadcom.com/docs/AV02-3819EN | Current YTC7 replacement for obsolete YTC2. Datasheet lead map: 1 KB, 2 KG, 3 KR, 4 AR, 5 AG, 6 AB. Independently driven active-low cathodes; text/icon fault detail remains in the PWA.
F1 | 1 | 500mA hold | Fuse:Fuse_1812_4532Metric | Bourns | MF-MSMF050-2 | LCSC | C17313 | 0.0668 | 0.0668 | 2026-08-21 | 47400 | 10 @ $0.0668 each | https://www.bourns.com/docs/product-datasheets/mf-msmf.pdf | 500 mA hold / 1 A trip PPTC; preserves <500 mA normal-current design target.
J1 | 1 | USB-C POWER ONLY | Connector_USB:USB_C_Receptacle_GCT_USB4105-xx-A_16P_TopMnt_Horizontal | Global Connector Technology | USB4105-GF-A | LCSC | C3020560 | 1.0659 | 1.0659 | 2026-08-21 | 926 | 1 @ $1.0659 | https://gct.co/files/drawings/usb4105.pdf | Power-only UFP. CC1/CC2 each use 5.1k Rd. D+/D-/SBU are intentionally NC. Shell to GND.
J2 | 1 | LOAD CELL E+/E-/S+/S- | Connector_JST:JST_GH_SM04B-GHS-TB_1x04-1MP_P1.25mm_Horizontal | JST | SM04B-GHS-TB(LF)(SN) | LCSC | C189895 | 1.1182 | 1.1182 | 2026-08-21 | 0 | 1 @ $1.1182; out of stock | https://www.jst-mfg.com/product/pdf/eng/eGH.pdf | Keyed carrier connector. Pin 1 E+, 2 E-, 3 S+ (green), 4 S- (white). LCSC C189895 was out of stock when checked; verify DigiKey/alternate stock before ordering. Mating housing and contacts are external BOM items.
J3 | 1 | UART DEBUG 3V3 | Connector_PinHeader_2.54mm:PinHeader_1x04_P2.54mm_Vertical | Samtec | TSW-104-07-G-S | JLCPCB | C3335156 | 0.6472 | 0.6472 | 2026-08-21 | 337 | 1 @ $0.6472 | https://suddendocs.samtec.com/prints/tsw-1xx-xx-xxx-x-xx-xx-mkt.pdf | Optional 3.3 V UART header: pin 1 3V3, 2 GND, 3 TX (D6/GPIO21), 4 RX (D7/GPIO20). Do not apply 5 V logic.
R1,R2 | 2 | 5.1k 1% | Resistor_SMD:R_0603_1608Metric | Yageo | RC0603FR-075K1L | DigiKey | 311-5.10KHRCT-ND | 0.02 | 0.0400 | 2026-08-21 | Not verified — distributor API credentials unavailable | Public distributor listing/search estimate; not a quote | https://www.yageo.com/upload/media/product/productsearch/datasheet/rchip/PYu-RC_Group_51_RoHS_L_16.pdf | USB-C CC1 Rd; 5.1 kΩ to GND per USB Type-C sink power role. | USB-C CC2 Rd; 5.1 kΩ to GND per USB Type-C sink power role.
R3,R4 | 2 | 47R 1% | Resistor_SMD:R_0603_1608Metric | Yageo | RC0603FR-0747RL | DigiKey | 311-47.0HRCT-ND | 0.02 | 0.0400 | 2026-08-21 | Not verified — distributor API credentials unavailable | Public distributor listing/search estimate; not a quote | https://www.yageo.com/upload/media/product/productsearch/datasheet/rchip/PYu-RC_Group_51_RoHS_L_16.pdf | Bridge input series filter resistor per Nuvoton Rev. 2.6 p.24.
R5,R6 | 2 | 4.7k 1% | Resistor_SMD:R_0603_1608Metric | Yageo | RC0603FR-074K7L | DigiKey | 311-4.70KHRCT-ND | 0.02 | 0.0400 | 2026-08-21 | Not verified — distributor API credentials unavailable | Public distributor listing/search estimate; not a quote | https://www.yageo.com/upload/media/product/productsearch/datasheet/rchip/PYu-RC_Group_51_RoHS_L_16.pdf | Carrier-owned 3.3 V I2C pull-up; do not parallel strong module pull-ups.
R7 | 1 | 10k 1% | Resistor_SMD:R_0603_1608Metric | Yageo | RC0603FR-0710KL | DigiKey | 311-10.0KHRCT-ND | 0.02 | 0.0200 | 2026-08-21 | Not verified — distributor API credentials unavailable | Public distributor listing/search estimate; not a quote | https://www.yageo.com/upload/media/product/productsearch/datasheet/rchip/PYu-RC_Group_51_RoHS_L_16.pdf | External pull-up for dedicated active-low button.
R8,R9,R10 | 3 | 220R 1% | Resistor_SMD:R_0603_1608Metric | Yageo | RC0603FR-07220RL | LCSC | C107696 | 0.0061 | 0.0183 | 2026-08-21 | 417400 | 100 @ $0.0061 each | https://www.yageo.com/upload/media/product/productsearch/datasheet/rchip/PYu-RC_Group_51_RoHS_L_16.pdf | RGB channel current limiting; final brightness/current is a bench-verification item.
SW1 | 1 | TARE/CAL/RECOVERY | Button_Switch_SMD:SW_SPST_PTS810 | C&K (Littelfuse) | PTS810SJM250SMTRLFS | DigiKey | CKN10502CT-ND | 0.20 | 0.2000 | 2026-08-21 | Not verified — distributor API credentials unavailable | Public distributor listing/search estimate; not a quote | https://www.ckswitches.com/media/1476/pts810.pdf | Dedicated user button, active low; firmware differentiates short/long hold. Not the XIAO BOOT/RESET control.
U1 | 1 | Seeed XIAO ESP32-C3 | parts-tally:XIAO_ESP32C3 | Seeed Technology Co., Ltd. | 113991054 | Seeed Studio | 113991054 | 4.99 | 4.9900 | 2026-08-21 | Not verified — distributor API credentials unavailable | Public distributor listing/search estimate; not a quote | https://files.seeedstudio.com/Bazaar/product_pdf/113991054.pdf | Module USB-C is the supported programming/recovery port; battery pads are DNP/unused.
U2 | 1 | NAU7802SGI | Package_SO:SOIC-16_3.9x9.9mm_P1.27mm | Nuvoton Technology Corporation | NAU7802SGI | LCSC | C5180029 | 1.7781 | 1.7781 | 2026-08-21 | 1427 | 1 @ $1.7781 | https://www.nuvoton.com/export/resource-files/en-us--DS_NAU7802_DataSheet_EN_Rev2.6.pdf | Configure internal LDO for 3.0 V AVDD, channel 1, PGA128, internal RC, 10 SPS; check CAL_ERR.

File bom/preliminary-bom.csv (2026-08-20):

candidate_status | quantity | function | candidate_part_or_module | manufacturer | mpn_or_sku | package_or_module | estimated_unit_cost_usd | price_observed_utc | source_url | notes
Selected module prototype | 1 | Wi-Fi/BLE MCU and USB development board | Seeed Studio XIAO ESP32-C3 | Seeed Technology Co. Ltd. | 113991054 | XIAO module board | 4.99 | 2026-08-20T00:24:42Z | https://www.seeedstudio.com/Seeed-XIAO-ESP32C3-p-5431.html | Manufacturer page reported InStock; exact SKU and datasheet reviewed; USB 5V SELV input; use 3V3/D4-SDA/D5-SCL; battery input unused
Selected module prototype | 1 | Strain-gauge bridge digitizer | SparkFun Qwiic Scale - NAU7802 | SparkFun Electronics | SEN-15242 | Qwiic breakout module | 5.95 | 2026-08-20T00:24:42Z | https://www.sparkfun.com/sparkfun-qwiic-scale-nau7802.html | Manufacturer page rendered In stock; selected over HX711 for I2C/register calibration and diagnostic behavior; underlying carrier IC NAU7802SGI; start at 3.3V DVDD / 3.0V AVDD, PGA128, 10SPS
Comparison only — do not order | 0 | Alternative bridge digitizer | SparkFun Load Cell Amplifier - HX711 | SparkFun Electronics | SEN-13879 | Breakout module | 4.95 | 2026-08-20T00:24:42Z | https://www.sparkfun.com/sparkfun-load-cell-amplifier-hx711.html | Current page rendered In stock. Prior CSV incorrectly paired active SEN-13879 with retired predecessor SEN-13230 URL. HX711 remains viable but is not selected; do not populate as an additional requirement
Selected module prototype | 1 | Force/weight sensor | Load Cell 5kg Straight Bar TAL220B | SparkFun Electronics orderable SKU; HT Sensor underlying cell | SEN-14729 | Straight-bar load cell | 15.50 | 2026-08-20T00:24:42Z | https://www.sparkfun.com/load-cell-5kg-straight-bar-tal220b.html | Manufacturer page rendered In stock; TAL220B datasheet reviewed: 5kg, 3-10V excitation, 1.0±0.1mV/V, 120% safe overload, red E+/black E-/green S+/white S-. Re-check actual markings and availability before order
Selected module prototype | 1 | Controller-to-ADC harness | Flexible Qwiic Cable Female Jumper 4-pin | SparkFun Electronics | CAB-17261 | Qwiic-to-female-jumper cable | 1.95 | 2026-08-20T00:24:42Z | https://www.sparkfun.com/products/17261 | Planning price from current indexed SparkFun record; stock quantity not captured—verify before ordering; continuity-check actual cable and never trust color alone
Deferred to schematic/mechanics | 1 | Local status indicator | Dedicated RGB status indicator | TBD | TBD | TBD | TBD—verify |  |  | No part selected in issue #2; choose exact LED/module after GPIO/current/brightness/enclosure review. Do not repurpose recovery LED as sole product status
Deferred to schematic/mechanics | 1 | Tare/calibrate input | Dedicated momentary pushbutton | TBD | TBD | Panel or PCB mount | TBD—verify |  |  | No part selected in issue #2; choose exact button after enclosure/debounce/recovery review. Do not repurpose BOOT/RESET as sole product control
Deferred to carrier board | 1 | Load-cell connector | 4-position keyed locking connector pair | TBD | TBD | TBD | TBD—verify |  |  | SEN-15242 spring terminals are used only for the module prototype. Select carrier connector/mating half with keyed pinout and strain relief after mechanical interface review
Non-schematic item | 1 | USB-C 5V cable and compliant supply | User-supplied or sourced | TBD | TBD | External | TBD—verify |  |  | SELV only; record supply/cable and current-limit settings in every bench setup; excluded from selected electrical subtotal
Non-schematic item | 1 | Base/top plate and overload-stop set | Locally fabricated | TBD | TBD | Editable mechanical fixture | TBD—verify |  |  | No fixture exists; publish editable CAD later; rigid load path must bypass electronics and stops must protect the cell before physical loading
Non-schematic item | 1 | Fastener/feet/strain-relief set | TBD | TBD | M5 cell mounting plus enclosure hardware | TBD—verify |  |  | TAL220B product record states two M5 through holes; exact lengths/tolerances follow the future fixture drawing; do not order from this placeholder

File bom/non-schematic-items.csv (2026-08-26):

Reference | Qty | Item | Manufacturer | MPN | Supplier_or_source | Estimated_unit_cost_USD | Status | Notes
EXT1 | 1 | 4-wire 5 kg load cell | HT Sensor Technology | TAL220B-5KG | SparkFun SEN-14729 | TBD | prototype item | Bench characterization/calibration required; wire colors must be continuity-checked before connection.
EXT2 | 1 | JST GH mating housing | JST | GHR-04V-S | DigiKey 455-1564-ND | TBD | required | Mates with J2; order contacts separately.
EXT3 | 4 | JST GH crimp contact | JST | SSHL-002T-P0.2 | DigiKey 455-2148-1-ND | TBD | required | Requires suitable crimp tooling or pre-crimped leads.
EXT4 | 1 | USB-C cable and SELV USB supply | TBD | TBD | User-supplied | TBD | required | Use a compliant SELV USB source; no mains circuitry is present on the carrier.
EXT5 | 1 | Printed base and top plate/bin cradle | OpenSCAD source | parts-tally-platform.scad | User-fabricated | TBD | design source complete | Material/process and bin fit remain unverified; loads bypass the PCB.
EXT6 | 2 | M5 load-cell fastener set | TBD | ISO metric M5 | Hardware supplier | TBD | required | Length and washer stack must be selected after measuring the purchased TAL220B and printed bosses.
EXT7 | 4 | M3 PCB standoff and screw set | TBD | ISO metric M3 | Hardware supplier | TBD | required | Fits 3.2 mm PCB holes; keep separate from scale force path.
EXT8 | 4 | M4 nylon-tip overload set screw jam nut and heat-set insert set | TBD | M4 x 16 set screw plus insert | Hardware supplier | TBD | required | Modeled insert pocket is 6.2 x 6 mm and modeled screw engagement/projection is 13.2 mm; verify purchased hardware. Adjust the tip below the 120% FS safe-overload boundary before installing the platform; do not rely on the printed 0.8 mm gap alone.
EXT9 | 4 | Non-slip foot with M4 attachment | TBD | TBD | Hardware supplier | TBD | required | Actual durometer, height, and mounting style require selection and level verification.
EXT10 | 2 | M3 cable-clamp fastener | TBD | ISO metric M3 | Hardware supplier | TBD | required | Secures the load-cell cable without pinching it; verify bend radius and pull relief.

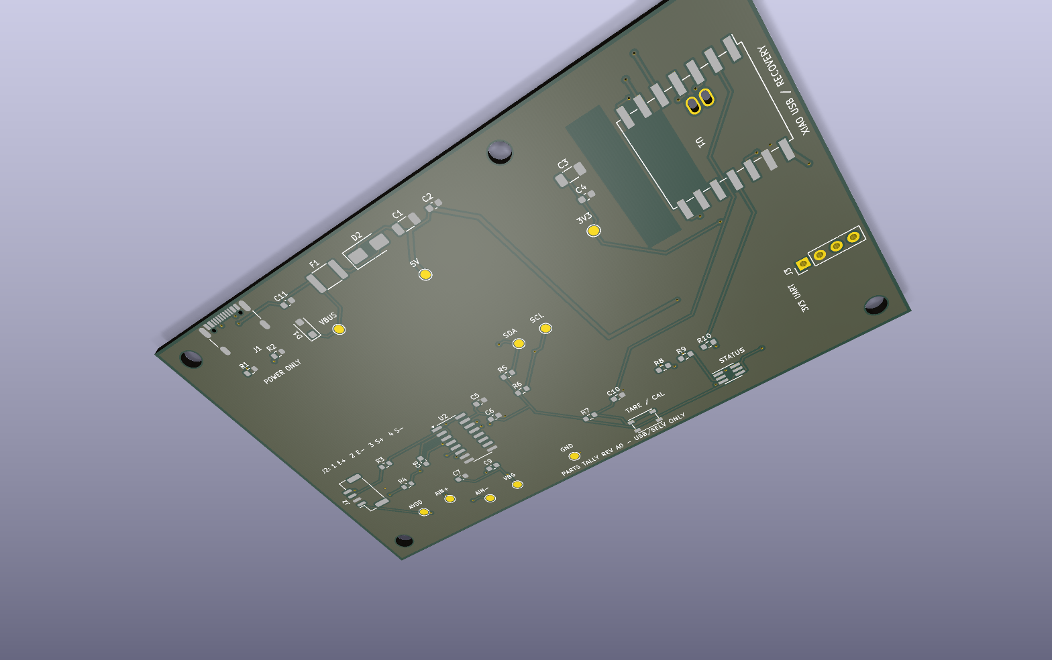
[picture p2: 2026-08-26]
hardware/reports/generated/parts-tally-isometric.png

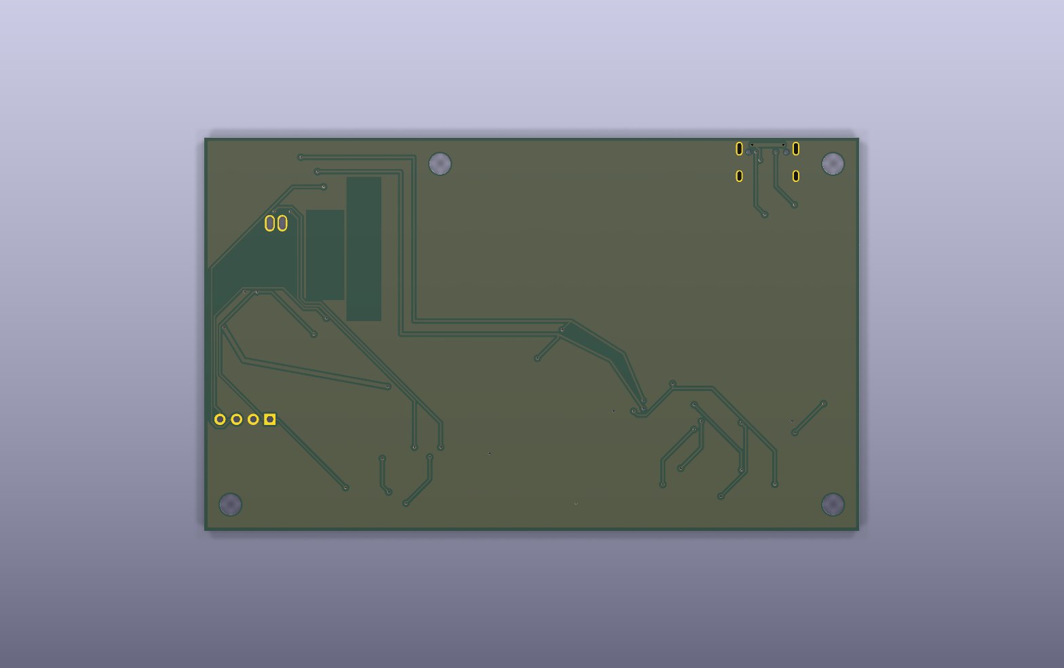
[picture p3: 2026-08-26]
hardware/reports/generated/parts-tally-bottom.png

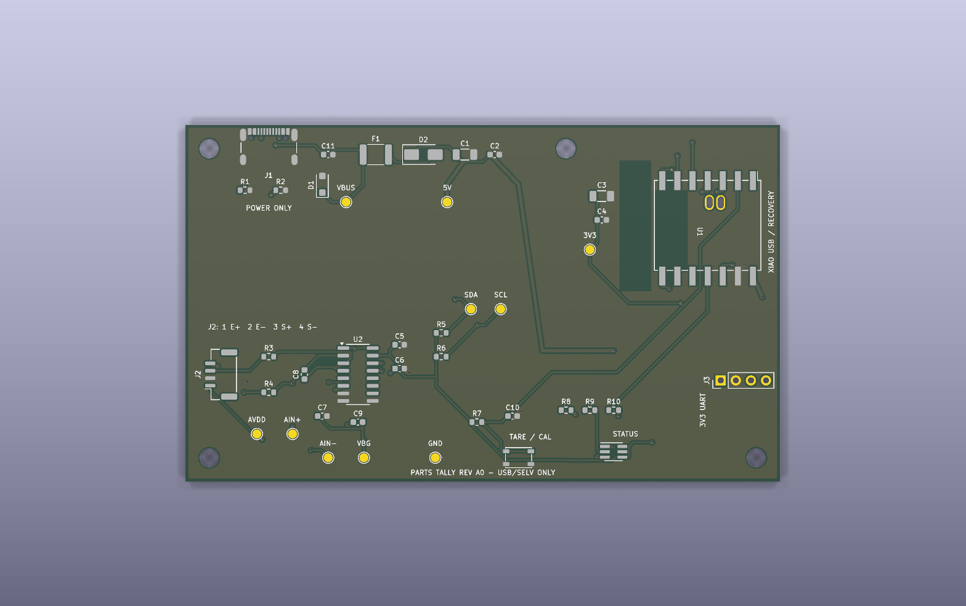
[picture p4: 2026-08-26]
hardware/reports/generated/parts-tally-top.png

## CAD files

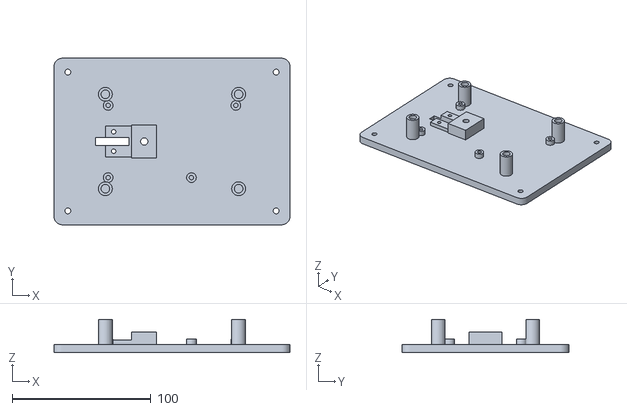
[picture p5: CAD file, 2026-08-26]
hardware/mechanical/generated/parts-tally-base.stl
170.0 x 120.0 x 24.0

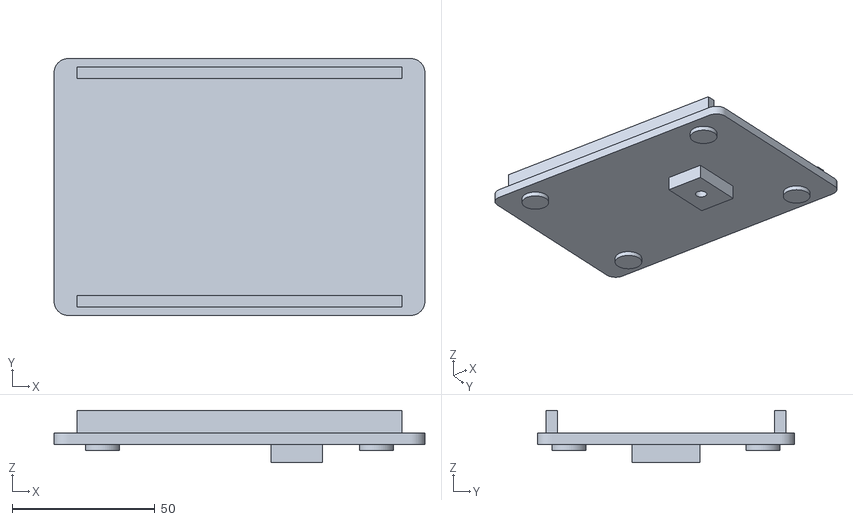
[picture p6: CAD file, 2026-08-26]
hardware/mechanical/generated/parts-tally-platform.stl
130.0 x 90.0 x 18.3

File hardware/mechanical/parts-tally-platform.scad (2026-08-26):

// Parts Tally parametric scale platform, revision A0.
// Editable source; all dimensions are millimetres.
//
// Manufacturer basis: HT Sensor TAL220B drawing (SparkFun-hosted PDF,
// SHA-256 641b4150...21181) gives 55 x 12.7 x 12.7 mm body, 40 mm
// mounting-hole spacing, and M5 passages.  Measure the purchased cell before
// fabrication.  This model is unbuilt and carries no physical-test claim.

$fn = 48;
part = "assembly"; // assembly | base | platform | cell | board | stop_gauge
join_overlap = 0.1; // ensure touching features compile as one printable solid

base_size = [170, 120, 6];
base_corner_r = 6;
platform_size = [130, 90, 4];
platform_corner_r = 5;
platform_z = 34;

load_cell_size = [55, 12.7, 12.7];
load_cell_hole_spacing = 40;
load_cell_hole_d = 5.2;
load_cell_z = 15;
fixed_hole_x = -load_cell_hole_spacing / 2;
free_hole_x = load_cell_hole_spacing / 2;
free_bracket_height = platform_z-load_cell_z-load_cell_size[2];
cell_mount_size = [18, 24];
fixed_mount_origin = [fixed_hole_x-cell_mount_size[0]/2,
                      -cell_mount_size[1]/2];
free_mount_origin = [free_hole_x-cell_mount_size[0]/2,
                     -cell_mount_size[1]/2];
assert_epsilon = 0.000001;

// Keep both printed M5 passages exactly collinear with the load-cell drawing.
// These assertions run during every OpenSCAD export and fail closed if a
// future origin/size edit moves either mount away from its cell hole.
assert(abs(fixed_mount_origin[0]+cell_mount_size[0]/2-fixed_hole_x) < assert_epsilon);
assert(abs(fixed_mount_origin[1]+cell_mount_size[1]/2) < assert_epsilon);
assert(abs(free_mount_origin[0]+cell_mount_size[0]/2-free_hole_x) < assert_epsilon);
assert(abs(free_mount_origin[1]+cell_mount_size[1]/2) < assert_epsilon);

pcb_size = [100, 60, 1.6];
pcb_z = 10;
// Coordinates are the actual KiCad hole locations translated by board centre.
pcb_holes = [[-46,-26], [14,-26], [-46,26], [46,26]];
pcb_standoff_od = 7;
pcb_hole_d = 3.2;

foot_holes = [[-75,-50], [75,-50], [-75,50], [75,50]];
foot_hole_d = 4.2;
stop_positions = [[-48,-34], [-48,34], [48,-34], [48,34]];
stop_boss_od = 10;
stop_contact_pad_od = 12;
stop_contact_pad_thickness = 2;
stop_nominal_gap = 0.8; // set physically below 120% FS; do not trust print tolerance
stop_contact_plane_z = platform_z-stop_contact_pad_thickness;
stop_boss_height = 18;
stop_boss_top = base_size[2]+stop_boss_height;
stop_insert_od = 6.2; // verify against the selected M4 heat-set insert
stop_insert_depth = 6;
stop_set_screw_d = 4;
stop_set_screw_contact_z = stop_contact_plane_z-stop_nominal_gap;
stop_set_screw_length = stop_set_screw_contact_z-(stop_boss_top-stop_insert_depth);
assert(abs(stop_contact_plane_z-stop_set_screw_contact_z-stop_nominal_gap) < assert_epsilon);
assert(stop_set_screw_length > 12 && stop_set_screw_length < 16);
assert(stop_contact_pad_od > stop_set_screw_d);

module rounded_plate(size, radius, height) {
    linear_extrude(height)
        hull()
            for (x=[-size[0]/2+radius, size[0]/2-radius],
                 y=[-size[1]/2+radius, size[1]/2-radius])
                translate([x,y]) circle(r=radius);
}

module base() {
    difference() {
        union() {
            rounded_plate([base_size[0], base_size[1]], base_corner_r, base_size[2]);
            // PCB standoffs are separate from the load-cell force path.
            for (p=pcb_holes)
                translate([p[0], p[1], base_size[2]-join_overlap])
                    difference() {
                        cylinder(h=pcb_z-base_size[2]+join_overlap, d=pcb_standoff_od);
                        cylinder(h=pcb_z-base_size[2]+0.2, d=pcb_hole_d);
                    }
            // Fixed-end cell support: only this boss loads the base.
            translate([fixed_mount_origin[0], fixed_mount_origin[1],
                       base_size[2]-join_overlap])
                cube([cell_mount_size[0], cell_mount_size[1],
                      load_cell_z-base_size[2]+join_overlap], center=false);
            // Adjustable overload-stop bosses bypass both cell and PCB at limit.
            for (p=stop_positions)
                translate([p[0],p[1],base_size[2]-join_overlap])
                    difference() {
                        cylinder(h=stop_boss_height+join_overlap, d=stop_boss_od);
                        translate([0,0,stop_boss_height-stop_insert_depth])
                            cylinder(h=stop_insert_depth+join_overlap,
                                     d=stop_insert_od);
                    }
            // Two-piece cable clamp land; cable exits toward the left side.
            translate([-48,-11,base_size[2]-join_overlap])
                cube([20,22,3+join_overlap]);
        }
        for (p=foot_holes)
            translate([p[0],p[1],-0.1]) cylinder(h=base_size[2]+0.2, d=foot_hole_d);
        // Fixed M5 cell passage.
        translate([fixed_hole_x,0,-0.1])
            cylinder(h=load_cell_z+1, d=load_cell_hole_d);
        // Strain-relief cable channel and M3 clamp holes.
        translate([-55,-3,-0.1]) cube([24,6,base_size[2]+4]);
        for (y=[-7,7]) translate([-42,y,-0.1]) cylinder(h=base_size[2]+5,d=3.2);
    }
}

module platform() {
    difference() {
        union() {
            rounded_plate([platform_size[0], platform_size[1]], platform_corner_r,
                          platform_size[2]);
            // Bin cradle rails keep a removable bin centred without claiming a fit.
            for (y=[-platform_size[1]/2+5, platform_size[1]/2-5])
                translate([-platform_size[0]/2+8,y-2,platform_size[2]-join_overlap])
                    cube([platform_size[0]-16,4,8+join_overlap]);
            // Free-end bracket connects only to the load cell.
            translate([free_mount_origin[0],free_mount_origin[1],
                       -free_bracket_height])
                difference() {
                    cube([cell_mount_size[0],cell_mount_size[1],
                          free_bracket_height+join_overlap]);
                    translate([cell_mount_size[0]/2,cell_mount_size[1]/2,-0.1])
                        cylinder(h=platform_z, d=load_cell_hole_d);
                }
            // Solid underside pads provide a real collision surface for the
            // adjustable M4 stop heads; adjustment is made before installing
            // the top platform, so no access hole defeats the stop.
            for (p=stop_positions)
                translate([p[0],p[1],-stop_contact_pad_thickness])
                    cylinder(h=stop_contact_pad_thickness+join_overlap,
                             d=stop_contact_pad_od);
        }
    }
}

module load_cell_reference() {
    color([0.7,0.7,0.72])
    difference() {
        translate([-load_cell_size[0]/2,-load_cell_size[1]/2,0]) cube(load_cell_size);
        for (x=[fixed_hole_x,free_hole_x])
            translate([x,0,-0.1]) cylinder(h=load_cell_size[2]+0.2,d=load_cell_hole_d);
    }
}

module pcb_reference() {
    color([0.05,0.35,0.15,0.75])
    difference() {
        translate([-pcb_size[0]/2,-pcb_size[1]/2,0]) cube(pcb_size);
        for (p=pcb_holes)
            translate([p[0],p[1],-0.1]) cylinder(h=pcb_size[2]+0.2,d=pcb_hole_d);
    }
    // XIAO antenna mechanical keepout, transformed from the KiCad rule area.
    // No fastener, cable loop, shield, or metal enclosure feature may enter.
    color([1,0.3,0.1,0.28])
        translate([23,-19,pcb_size[2]]) cube([12,28,12]);
}

module feet_reference() {
    color([0.1,0.1,0.1])
    for (p=foot_holes)
        translate([p[0],p[1],-3]) cylinder(h=3,d=16);
}

module stop_hardware_reference() {
    // Reference only: M4 nylon-tip set screws in heat-set inserts, locked with
    // jam nuts. The screw-tip plane—not the boss top—defines the nominal gap.
    for (p=stop_positions) {
        color([0.75,0.55,0.18])
            translate([p[0],p[1],stop_boss_top-stop_insert_depth])
                cylinder(h=stop_insert_depth,d=stop_insert_od);
        color([0.55,0.57,0.6])
            translate([p[0],p[1],stop_boss_top-stop_insert_depth])
                cylinder(h=stop_set_screw_length,d=stop_set_screw_d);
        color([0.45,0.45,0.47])
            translate([p[0],p[1],stop_boss_top])
                cylinder(h=3,d=7,$fn=6);
    }
}

module stop_gap_gauge() {
    // Print only as a setup aid; verify the real stop under controlled loading.
    cube([30,12,stop_nominal_gap]);
}

module assembly() {
    color([0.18,0.2,0.22]) base();
    feet_reference();
    translate([0,0,load_cell_z]) load_cell_reference();
    translate([0,0,pcb_z]) pcb_reference();
    stop_hardware_reference();
    color([0.82,0.84,0.86,0.75]) translate([0,0,platform_z]) platform();
}

if (part == "base") base();
else if (part == "platform") platform();
else if (part == "cell") load_cell_reference();
else if (part == "board") pcb_reference();
else if (part == "stop_gauge") stop_gap_gauge();
else assembly();

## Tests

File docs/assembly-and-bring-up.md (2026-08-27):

# Parts Tally A0 assembly, calibration, and bring-up

**Applies to:** carrier A0, firmware 0.2.0, protocol `parts-tally/v1`, app 0.1.0
**Evidence state:** instructions and acceptance plan only; no physical prototype, continuity record, instrument data, or field result exists.

This is a USB/SELV-only, non-certified counting aid. It is not legal-for-trade. Never connect mains, exceed the TAL220B 5 kg rated load, use the platform structurally, or use the count as the sole control for safety-critical stock.

## 1. Parts and tools

Use the exact schematic-backed parts in `bom/bom.csv` and non-schematic items in `bom/non-schematic-items.csv`. Before ordering, re-check every supplier ID and stock observation; C189895 has conflicting public availability results. Required bench equipment:

- current-limited 5 V SELV USB supply or USB power analyzer with current limiting;
- DMM with continuity/diode/voltage modes and identified probes;
- 3.3 V UART adapter (never 5 V logic) for J3 if USB recovery is insufficient;
- known masses or uniform counted parts whose provenance/count is recorded;
- rigid printed base/platform, specified fasteners, strain relief, non-slip feet, and four adjusted overload stops;
- ESD-safe soldering/rework equipment and magnification.

Record instrument make/model/asset ID, settings, UTC time, operator, ambient temperature, all hardware markings, firmware commit, fixture revision, and applied references before calling any result bench evidence.

## 2. Board and connector orientation

### Power and controller

```text
USB-C J1 VBUS
  -> D1 TVS and C11
  -> F1 500 mA hold PPTC
  -> D2 reverse-current Schottky
  -> TP2 +5V_XIAO -> U1 XIAO regulator
  -> TP3 +3V3 -> U2 DVDD and digital pull-ups
  -> U2 internal LDO -> TP5 AVDD_3V0 / bridge excitation
```

J1 is power-only: D+/D-/SBU are intentionally unconnected. Use U1's own USB-C port for programming/recovery. Do not connect both USB inputs without first reviewing the intended power path.

### Load-cell connector J2

View pin numbering from the board silkscreen/assembly drawing and verify the purchased connector drawing; do not infer it from wire color alone.

```text
J2 pin 1  E+  AVDD_3V0  -> TAL220B red    (excitation +)
J2 pin 2  E-  GND        -> TAL220B black  (excitation return)
J2 pin 3  S+  LC_S+      -> TAL220B green  (signal +)
J2 pin 4  S-  LC_S-      -> TAL220B white  (signal -)
```

Continuity-check every harness conductor end-to-end before insertion. Swapping S+/S- reverses sign; correct the documented harness rather than hiding an unexplained reversal in firmware. Swapping excitation and signal pairs is prohibited.

### UART J3 and user controls

```text
J3.1 +3V3     J3.2 GND     J3.3 UART_TX (D6/GPIO21)
J3.4 UART_RX (D7/GPIO20; 3.3 V logic only)
SW1 dedicated active-low tare/calibrate/recovery input (D1/GPIO3)
D3 red/green/blue channels are active-low through R8/R9/R10 (220 ohm)
```

### Named test points

| TP | Net | Expected powered state | Purpose |
|---|---|---|---|
| TP1 | VBUS | approximately USB input, nominal 5 V | connector-side input |
| TP2 | +5V_XIAO | below TP1 by F1/D2 losses | protected module input |
| TP3 | +3V3 | nominal 3.3 V | controller/ADC logic |
| TP4 | GND | 0 V reference | probe reference |
| TP5 | AVDD_3V0 | nominal 3.0 V after firmware config | ADC analog supply/excitation |
| TP6 | I2C_SDA | 3.3 V idle; open-drain traffic | bus data |
| TP7 | I2C_SCL | 3.3 V idle; open-drain traffic | bus clock |
| TP8 | AIN+ | low-level bridge input; do not short/inject | filtered ADC input + |
| TP9 | AIN- | low-level bridge input; do not short/inject | filtered ADC input - |
| TP10 | VBG | ADC reference node; compare only with NAU7802 procedure | diagnostic/reference |

These are expected design states, not measured tolerances. Record actual values and the DMM reference point. Stop on negative/unstable rails, excessive current, smoke, heat, odor, or unexpected continuity.

## 3. Mechanical assembly

1. Print `hardware/mechanical/parts-tally-platform.scad` outputs using a documented material/process. Inspect for cracks, warping, blocked insert pockets, and dimensional error.
2. Fit the two TAL220B mounting passages at the documented 40 mm center spacing. Confirm the load direction against the manufacturer drawing.
3. Attach the fixed end to the base and the sensing end only to the platform. The force path must be bin -> platform -> sensing end -> fixed end -> base -> feet. The PCB and cables must not carry load.
4. Mount the PCB on independent M3 standoffs. Preserve the XIAO antenna no-metal/no-fastener volume.
5. Install strain relief without pinching the load-cell cable. Keep bridge conductors paired and away from USB/radio wiring.
6. Install M4 inserts, nylon-tip set screws, jam nuts, and solid platform contact pads. The CAD's 0.8 mm nominal gap is not an acceptance measurement.
7. With a controlled conservative proof load below the TAL220B 120% FS safe-overload boundary, adjust all four stops evenly and lock them. Never use the 150% ultimate overload as a test target.
8. Confirm no rocking, PCB contact, cable tension, or fastener contact bypasses the load cell.

## 4. Soldering and assembly controls

1. Inspect bare boards against Edge.Cuts, drill map, assembly SVGs, and Gerbers before population.
2. Verify polarized/oriented parts: D1/D2, D3 pin 1/channel map, J1, J2 pin 1, U2 pin 1, U1 orientation, and J3 pin 1.
3. J1 has two bottom-tented but unfilled through-vias in VBUS pads. Obtain assembler approval for solder wicking or hand-solder/rework and inspect both sides. Tenting is not plugging.
4. Clean flux around U2 bridge inputs and high-impedance/reference nodes. Inspect for solder bridges and contamination under magnification.
5. Do not install the load cell until unpowered board checks pass.

## 5. Bring-up checklist

Every box below is initially unchecked. A future operator must copy this checklist into a dated unit record rather than editing this baseline to imply execution.

### A. Unpowered inspection and continuity

- [ ] Record PCB serial/markings, exact populated MPNs, assembly source, and photos of the real unit.
- [ ] Inspect orientation, solder joints, antenna keepout, via-in-pad joints, connector damage, and mechanical separation.
- [ ] Confirm no short between GND and TP1/TP2/TP3/TP5; record resistance after capacitor charging settles.
- [ ] Confirm J1 shell/GND and J2 pin 2 connect to TP4.
- [ ] Confirm J2 pins 1/2/3/4 reach TP5/GND/bridge paths as documented and are not mutually shorted.
- [ ] Continuity-check all four harness wires and connector orientation.
- [ ] Confirm the load cell/fixture/stops/strain relief are installed and the PCB is outside the force path.

### B. Current-limited USB first power

- [ ] Disconnect the load cell initially unless the reviewed procedure requires it connected.
- [ ] Set a documented 5 V current limit; begin conservatively and never exceed the design's 500 mA normal-current target.
- [ ] Apply power while observing current. Stop immediately on current limiting, heat, odor, smoke, unstable rails, or unexpected LED behavior.
- [ ] Record TP1, TP2, TP3, quiescent/current-limited supply current, and component temperatures by a stated method.
- [ ] Program firmware 0.2.0 through U1 USB-C; retain full build/upload logs and binary hash.

### C. Programmer and recovery

- [ ] Verify normal USB enumeration and upload.
- [ ] If normal upload fails, use the XIAO manufacturer's BOOT/RESET recovery sequence; SW1 is not a substitute for board recovery controls.
- [ ] If needed, connect J3 using 3.3 V UART only and cross TX/RX correctly.
- [ ] Verify factory reset/session recovery does not create an authoritative count and preserves explicit setup state.

### D. ADC and raw readings

- [ ] Configure U2 for 3.0 V nominal AVDD, channel 1, PGA 128, internal RC, 10 SPS, and required calibration; reject `CAL_ERR`.
- [ ] Record TP5 and bridge excitation across J2 pins 1-2. Stop if the load-cell 3 V minimum or U2 DVDD-to-AVDD margin is not met.
- [ ] Verify SDA/SCL idle near 3.3 V and capture bus traffic if diagnostics are needed.
- [ ] Record unedited signed 24-bit raw readings at zero load; verify no stale/disconnected/saturated fault.
- [ ] Apply a small safe load. Confirm the sign and return-to-zero response; correct S+/S- wiring if reversed.

### E. Tare and calibration

- [ ] Warm up for the characterized period; until WARM-01 exists, record elapsed warm-up rather than claiming it is sufficient.
- [ ] Place the intended empty bin, wait for a stable state, and tare.
- [ ] Add at least 10 identical known parts; use more when unit mass/noise requires it. Enter the exact known count.
- [ ] Reject calibration while unstable, disconnected, stale, saturated, overload-indicated, or below the `20B` unit-mass/noise criterion.
- [ ] Remove/reapply the sample and record raw code, net grams, estimated count, uncertainty, state, and actual count.

### F. Network/app and known-count trials

- [ ] Provision only on the intended local network/direct mode; record firmware/app revisions.
- [ ] Connect app 0.1.0 to protocol `parts-tally/v1`; verify explicit disconnected/stale/fault UI states.
- [ ] Exercise reconnect and event-gap refresh without retaining a stale authoritative count.
- [ ] Run COUNT-01 with at least three uniform part types and preserve every miss/correction.
- [ ] Execute the remaining `docs/verification-plan.md` matrix (repeatability, hysteresis, drift, creep, off-center, cable, disconnect, saturation, overload indication, Wi-Fi interruption).

## 6. Calibration procedure and evidence capture

Use `scripts/capture_samples.py` exactly as documented in `hardware/module-prototype.md`. Preserve the CSV and `.meta.json` sidecar together. For bench classification, metadata must be non-placeholder and the analyzer verifies sample count, input format, sidecar name, and SHA-256. Never edit raw rows; create a new trial and document anomalies.

Do not choose stability/noise thresholds from synthetic fixtures. NOISE-01 establishes `B` and drift limits from real Wi-Fi-off/idle/active captures. The ±1 piece objective applies only when unit mass and the declared uncertainty trial set support it.

## 7. Troubleshooting and recovery

| Symptom | Safe checks | Recovery / escalation |
|---|---|---|
| Supply current limit trips | Remove USB; inspect J1, D1, F1, D2, U1 orientation and rail shorts | Do not increase the limit to force startup; isolate the short and repeat unpowered checks |
| TP1 present, TP2 absent/low | Check F1 continuity, D2 polarity/drop, solder wicking at J1 vias | Repair only with documented rework; replace damaged protection parts |
| TP3 absent | Check U1 orientation, +5V_XIAO, module USB conflict | Recover/program U1 separately; do not backfeed 3V3 |
| TP5 absent/wrong | Confirm U2 DVDD, firmware LDO setting, CAL_ERR, C5/C6/U2 joints | Stop bridge tests; correct config/assembly before connecting the load cell |
| I2C NACK at 0x2A | Check 3.3 V pull-ups, SDA/SCL continuity/swap, U2 supply and address | Power-cycle after correcting wiring; do not add stronger pull-ups blindly |
| Raw code saturated/stale | Check J2 mapping, open/short bridge, excitation, U2 state | Withhold count; repair harness/sensor or ADC path and recalibrate |
| Load produces negative sign | Reconfirm physical load direction and J2 pins 3/4 | Correct S+/S- harness documentation; do not silently mask an unknown reversal |
| Reading changes with cable motion | Check strain relief, connector seating, cable routing/contamination | Fix mechanics and rerun CABLE-01/NOISE-01 |
| Count shown while faulted | Capture protocol/UI evidence | Treat as release blocker; firmware/app must withhold authoritative count |
| App cannot reconnect | Check local URL, credentials/session expiry, event gap handling | Use explicit refresh/re-auth; verify physical status remains useful offline |
| Firmware upload fails | Use U1 USB-C, known cable, manufacturer BOOT/RESET recovery | Use 3.3 V UART diagnostics only; preserve upload logs |
| Platform bottoms or rocks | Remove load; inspect feet, load path, stop adjustment | Rebuild/adjust fixture below safe load; do not continue calibration |

## 8. Completion boundary

This document is complete as an executable procedure, but every physical checkbox remains unexecuted. A future release may change bench/field status only by adding dated raw evidence, setup metadata, instrument identification, actual results, anomalies, and hashes. Renders, static validation, software tests, and simulated data never satisfy that requirement.

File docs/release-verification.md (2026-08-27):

# Integrated release verification record

**Release candidate:** v0.1.0-rc.1
**Compatibility:** carrier A0 / firmware 0.2.0 / protocol `parts-tally/v1` / app 0.1.0
**Evidence cutoff:** populated by the issue #7 PR and tagged release workflow

## Verdict

The release process is reproducible and fail-closed: a package is produced only after native KiCad ERC/DRC/schematic parity, repository hardware/BOM validators, BOM/CPL parity, manifest/document contracts, and archive integrity pass. Firmware/app checks run in their pinned workflows. This supports an **RC for fabrication quote/DFM and first-article build**, not a declaration that hardware works.

## Static analysis

Required commands:

```bash
python3 scripts/validate_contract.py
python3 -m unittest discover -s tests -v
python3 hardware/kicad/validate_hardware.py
python3 hardware/kicad/export_bom.py --check
python3 scripts/validate_release.py
pio check -d firmware -e native --fail-on-defect high
pio test -d firmware -e native
pio run -d firmware -e seeed_xiao_esp32c3
cd app && npm ci && npm run lint && npm run typecheck && npm test && npm run build && npm run test:e2e
```

The release workflow additionally runs KiCad 9 ERC, exports the XML netlist, executes `validate_pcb.py`, runs DRC with all severities/all track errors/schematic parity, plots fabrication files, normalizes CPL, checks exact BOM/CPL parity, compiles the OpenSCAD solids, validates manifold topology, and verifies every archive checksum/ZIP member.

Exact run URLs and tool output are recorded in the PR and tag Actions pages. The archive includes KiCad ERC/DRC reports and the exact fabrication command log. Results must not be copied into this source file before the corresponding run exists.

## Datasheet/BOM verification

- The schematic remains the BOM source of truth and `bom/bom.csv` is checked for drift.
- Every populated symbol carries Manufacturer, MPN, supplier/source, supplier PN, Datasheet, dated cost/stock observation, and BOM comments.
- NAU7802SGI has a 96/100 structured extraction with all 16 pins checked against Nuvoton Rev. 2.6.
- Critical XIAO, USB-C, JST GH, RGB LED, protection, and load-cell mappings are backed by manufacturer documents cited in `hardware/datasheets/manifest.json` and `hardware/reports/schematic-validation.md`.
- The bulk LCSC catalog was not accessed because accepting third-party catalog terms was not authorized. Public searches on 2026-08-27 confirmed the exact C189895/JST mapping but returned contradictory stock snippets; no current stock or price claim is made.
- Full structured extraction is not available for every passive/module. Those checks remain manufacturer-link/manual consistency checks, not machine-extracted verification.

## Fabrication/DFM basis

Selected comparison profile: documented JLCPCB standard two-layer capability. Design values are 0.15 mm minimum track, 0.20 mm minimum clearance, 0.60/0.30 mm vias, 0.50 mm copper-edge clearance, 100 × 60 mm, two layers, and 1.6 mm nominal board thickness. Native DRC is authoritative; the release validator also checks the frozen profile is not below published process minima.

The principal assembly exception is J1's two bottom-tented, unfilled through-vias in VBUS pads. Tenting does not equal filling/plugging. PCBA requires explicit assembler process acceptance or documented hand rework and inspection. CPL rotations remain an operator review item during first-order assembly review.

## Simulation

**Not performed.** No SPICE simulator was installed on the execution host, no validated component models/parasitics were available for a meaningful whole-chain result, and no simulated result is substituted for physical characterization. Static application-circuit calculations are identified as such in the hardware review.

## Bench testing

**Not performed — no physical prototype exists.** There is no assembly record, continuity result, instrument record, rail/current measurement, ADC capture, load fixture, calibration, repeatability, hysteresis, warm-up, creep, off-center, disconnect, overload, reconnect, or known-count evidence. `docs/assembly-and-bring-up.md` and `docs/verification-plan.md` preserve the unexecuted procedures.

## Field testing

**Not performed — no physical prototype exists.** There is no field deployment, environmental observation, long-term drift record, user trial, radio-range result, or operational safety evidence.

## Known limitations / release gaps

1. First-article fabrication, assembly, mechanical fit, stop adjustment, and continuity are pending.
2. USB current/inrush, diode losses, 3.3 V rail, 3.0 V AVDD/excitation boundary, RGB brightness/current, and thermal behavior are unmeasured.
3. Load-cell noise, RF coupling, calibration quality, drift, creep, hysteresis, off-center response, and useful unit-mass limits are uncharacterized.
4. Conducted/radiated EMC and antenna detuning are unmeasured; only static keepout/return-path evidence exists.
5. J2 availability and all prices/stock must be rechecked before ordering; no substitution inherits this review.
6. The PCBA BOM includes user-sourced blanks; an operator must review part matching and rotations.
7. The device is USB/SELV-only, not certified, not legal-for-trade, and unsuitable for safety-critical stock control.

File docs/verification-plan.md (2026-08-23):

# Prototype verification plan

**Plan version:** 1.1
**Baseline date:** 2026-08-20
**Execution status:** UNEXECUTED — no physical prototype, instrument data, or raw samples are present

This plan defines evidence required by later issues. A checked-in plan, synthetic fixture, render, successful build, or static analyzer is not bench evidence.

## Evidence rules

Every executed bench record must include:

- UTC date/time, operator, hardware/firmware/app revisions, controller/ADC/load-cell MPNs and revisions;
- fixture drawing/revision, fasteners, overload-stop setting, bin/platform identity, applied masses/known parts;
- USB supply, ambient temperature, warm-up time, instrument make/model/asset identifier and relevant settings;
- unedited timestamped raw ADC samples plus derived outputs and active filter/stability parameters;
- exact command/script version, pass/fail calculation, anomalies, and links to photos only when photos depict the real setup;
- separate declarations for static analysis, simulation, software tests, bench tests, and field tests.

Raw data must be retained in an open format. Reports may summarize but never replace it.

## Safety prerequisites for physical work

Do not execute load tests until all are true:

1. exact load-cell datasheet/rated load and wiring are verified;
2. rigid base, fixed/sensing mounts, top plate, non-slip feet, strain relief, and mechanical overload stops are installed;
3. PCB/modules/cables are outside the force path;
4. unpowered inspection and continuity checks pass;
5. first power uses a current-limited USB source;
6. overload tests use a controlled fixture and stop below the manufacturer's damaging limit.

## Static and synthetic gate

| ID | Stage | Procedure | Pass criterion | Current status |
|---|---|---|---|---|
| DOC-01 | Documentation/static | Run `python3 scripts/validate_contract.py` and `python3 -m unittest discover -s tests -v`. | Both exit 0; all required IDs/documents/contracts agree. | Implemented by this issue; result belongs in PR evidence. |
| SYN-01 | Synthetic software | Feed deterministic zero, step, vibration, drift, creep, disconnect, saturation, stale, and restart fixtures to the measurement domain. | Golden outputs preserve no-count states, bounded recovery, and deterministic count/uncertainty. | Implemented in software: native golden tests assert zero, sustained steps, vibration, drift, creep, disconnect, saturation, overload, stale, restart/migration/corruption, calibration, count rounding, malformed messages, all route families, security, idempotency, sessions, export, and import. Physical characterization remains pending. |
| PROTO-READY-01 | Pre-bench | Review datasheets, wiring, mechanical load path, stops, instrument list, and raw capture path. | Reviewer signs all prerequisites; exact revisions recorded. | Partial: exact selected chain, planned wiring, capture path, and datasheet review exist. No purchased revisions, fixture/stops, instruments, continuity, or signoff exist. |

## Characterization matrix

Unless a selected datasheet imposes a tighter limit, use loads at approximately 0%, 10%, 25%, 50%, 75%, and 90% of the validated safe working load. Do not infer kilograms from raw ADC codes before calibration.

| ID | Measurement | Repeatable procedure | Planned metric / pass rule | Current status |
|---|---|---|---|---|
| NOISE-01 | Zero-load noise | Warm up per selected-device guidance; record at least 10 minutes at empty stable tare with Wi-Fi off, idle, and active traffic conditions. | Report sample rate, raw/code and gram standard deviation, P95-P5 band `B`, peak-to-peak, slope, outlier rate, and RF-condition deltas. Establish thresholds; no advance pass value is fabricated. | Unexecuted |
| REP-01 | Repeatability | Apply/remove each reference load at least 10 times, approaching consistently and allowing stability gate to settle. | For parts meeting `u >= 20B`, known-count estimates meet the ±1-piece target in the declared confidence/trial set; report all misses. | Unexecuted |
| HYS-01 | Hysteresis | Measure the same points on ascending and descending load cycles, at least 3 cycles. | Report maximum same-point difference in grams and pieces; acceptance threshold set from load-cell datasheet/application needs before execution. | Unexecuted |
| WARM-01 | Warm-up drift | From cold power-on, record unloaded and one mid-load reference for at least 30 minutes without retare. | Report offset/span change versus time and derived minimum warm-up guidance. Release requirement is evidence-based guidance, not assumed zero drift. | Unexecuted |
| CREEP-01 | 10-minute creep | Apply a stable mid/high reference load and record continuously for at least 10 minutes after initial settling. | Report change at 1, 5, and 10 minutes plus slope and count effect; set/verify policy for count withholding or guidance. | Unexecuted |
| OFFCENTER-01 | Off-center loading | Place the same safe reference load at center and documented corners/edges of the intended bin contact area. | Report maximum deviation and count impact. Any test risking fixture damage is skipped, not improvised. | Unexecuted |
| CABLE-01 | Cable disturbance | At zero and a reference load, perform a scripted gentle cable movement without changing applied load. | No silent authoritative count change; report induced band/offset and validate strain relief/recovery. | Unexecuted |
| DISC-01 | Disconnect/open bridge | Safely disconnect each supported sensor/module connection using an approved fixture. | Device reaches `disconnected` or another explicit no-count fault within a characterized time; no stale count remains authoritative; reconnection is explicit. | Unexecuted |
| SAT-01 | ADC saturation/out-of-range | Use a safe electrical fixture or bounded mechanical condition approved from the datasheet; do not overload the cell. | `saturated`/out-of-range is reported and count withheld; recovery requires valid stable samples. | Unexecuted |
| OVR-01 | Overload indication/stops | Exercise the validated overload-indication threshold while mechanical stops protect the load cell. Never exceed rated/damaging limits. | `overload_indicated`, count withheld, stops engage as designed, and post-test zero/span checks show no damage. | Unexecuted |
| WIFI-01 | Wi-Fi interruption | During stable sampling, disable AP/LAN, create event gaps, reconnect, and repeat power/network transitions. | Physical status and local measurement continue; profiles/calibration persist; client detects sequence gap and refreshes without inventing missed history. | Unexecuted |
| COUNT-01 | Known-count trials | For at least three uniform part types spanning usable unit masses, calibrate with documented `Ncal`, then blind-test multiple counts and corrections. | Report estimated count, uncertainty, actual count, stable/no-count state, errors, and whether ±1 target applies. Mixed/variable parts are explicitly unsuitable. | Unexecuted |

## Calibration misuse and recovery checks

Later firmware/app tests must also cover:

- known count below 10;
- calibration while unstable, disconnected, stale, saturated, or overload-indicated;
- negative net mass beyond zero band;
- unit mass below `20B`;
- corrupt, interrupted, old-schema, and non-finite calibration records;
- bin/profile mismatch and changed mechanical fixture;
- request replay/idempotency, credential rotation, factory reset, and USB recovery;
- import preview with incompatible schema and secret-like fields.

Each must fail safely, retain the last valid state where appropriate, and avoid producing an authoritative count.

## Requirement traceability

| Requirement | Primary test evidence |
|---|---|
| E-02 | Supply current measurements during NOISE-01/WIFI-01 plus first-power log |
| E-04 | DISC-01, SAT-01, stale synthetic fixture |
| M-02/M-03 | PROTO-READY-01, calibration misuse tests, COUNT-01 |
| M-04/M-05 | NOISE-01, REP-01, COUNT-01, synthetic tests |
| M-06 | WARM-01, CREEP-01, HYS-01, OFFCENTER-01, CABLE-01 |
| M-07 | SAT-01, OVR-01 |
| K-02/K-04/K-05 | Fixture inspection, OFFCENTER-01, CABLE-01, RF condition comparison |
| C-01/C-04 | WIFI-01 and power-cycle synthetic/target tests |
| V-02 | Ambient record across all bench tests; selected-part ratings review |

## Pending evidence statement

As of this baseline, all physical rows are **Unexecuted**. There is no claim of module assembly, sensor characterization, prototype testing, fabrication, or field use. Issue #2 may execute only the subset supported by hardware actually available; missing work remains a named gap.

The issue #2 software subset is repeatable with:

```bash
python3 scripts/analyze_capture.py tests/fixtures/synthetic_capture.csv \
  --evidence-stage synthetic-software --window-samples 10 \
  --max-band 4 --max-abs-slope 5 --output /tmp/synthetic-report.json
python3 -m unittest discover -s tests -v
```

This is synthetic software evidence only. It does not change any physical row to executed.

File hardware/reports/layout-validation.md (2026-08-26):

# Carrier PCB and mechanical layout validation

**Project:** Parts Tally revision A0 (KiCad 9, single-sheet schematic, two-layer PCB)

**Review date:** 2026-08-26 UTC

**Scope:** issue #6 carrier PCB, static PCB/schematic cross-check, and editable mechanical source

**Physical evidence:** none

## Verdict and blockers

**No critical or warning-level electrical/layout blocker was found by the checks that ran.** The editable PCB is ready for peer review and issue #7 fabrication-package work, but it is **not fabrication-approved or prototype-tested**.

| Severity | Item | Required action |
|---|---|---|
| WARNING before fabrication | J1’s locator holes force two 0.60/0.30 mm through-vias into VBUS pads. The B.Cu ends are tented, but unfilled via-in-pad can wick solder. | In issue #7, confirm the assembler’s tenting/plugging process or select hand-solder/rework guidance before ordering. |
| WARNING before ordering | Current public results for JST C189895 conflict between in-stock and out-of-stock snippets. | Recheck the exact JST MPN and source at checkout; do not silently substitute the footprint. |
| TEST GAP | No board, fixture, or enclosure has been built. | Execute continuity, power, noise, RF, mechanical fit, overload-stop, calibration, and stability tests on hardware. |

## Overview

The 100 × 60 mm board carries a power-only USB-C input, protected 5 V path, Seeed XIAO ESP32-C3 module, NAU7802 bridge ADC, keyed JST GH load-cell connector, RGB status LED, button, UART header, and ten named test points. U1 is at a board edge with explicit copper/track/via and component rule areas on both layers. Parametric OpenSCAD source provides a 170 × 120 mm printed base, load-cell mounts, 130 × 90 mm bin platform, PCB standoffs outside the force path, cable clamp, feet, and adjustable overload stops.

## Previous review delta

The 2026-08-22 schematic review explicitly lacked a PCB, DRC, mechanical CAD, EMC-layout basis, and manufacturing layout evidence.

- **Fixed/new evidence:** editable routed `.kicad_pcb`; 0-violation native DRC; exact schematic↔PCB pad-net validator; antenna rule areas; GND pours; M3 board mounts; review renders; editable mechanical source.
- **Still open:** physical module/connector fit, AVDD/excitation measurement, bridge noise, USB inrush, RF interaction, thermal behavior, calibration/drift, harness continuity, overload-stop setup, and complete fabrication DFM.
- **No prior PCB analyzer JSON:** a structured run-to-run PCB diff was not possible.

During the 2026-08-26 inherited-work review, the base's fixed-end M5 passage was found offset from the TAL220B drawing center because a non-centered boss origin was interpreted as its center. The same review found that the first stop formula produced a 4.8 mm gap, access holes removed the intended contact surfaces, and a later draft measured the gap from the bare boss rather than the adjustment hardware. The source now places fixed/free passages at the drawing's ±20 mm centers and models each stop as an M4 heat-set insert, nylon-tip set screw, jam nut, and solid 12 mm underside pad. The asserted 0.8 mm nominal gap is from the modeled screw-tip plane to the pad. Both OpenSCAD solids were recompiled successfully. These defects were resolved before publication; purchased-hardware fit and real stop adjustment remain unverified.

## Verification basis

### Tools actually run

| Check | Evidence basis | Result |
|---|---|---|
| `validate_hardware.py` | raw schematic + manufacturer-backed assertions from issue #3 | PASS: 45 symbols, 31 populated BOM components, 106 labeled connections, 15 intentional NCs, 16 NAU7802 pins, 6 RGB pins, 16 XIAO footprint pads, exact critical pad sets |
| KiCad 9 ERC | native KiCad | 0 violations |
| `validate_pcb.py` | raw PCB + exported KiCad XML netlist | PASS: 128 physical pads / 124 unique IDs checked against 123 schematic nodes plus J2's explicitly unnetted `MP` hold-down ID; 41 schematic footprints + 4 board-only holes |
| KiCad 9 DRC | native KiCad, all severities and all track errors | **0 violations, 0 unconnected items, 0 footprint errors** |
| KiCad 9 schematic parity | native KiCad | **0 parity issues** after H1–H4 were marked board-only |
| OpenSCAD CLI + `validate_stl.py` | source compile + independent mesh topology | base: 4,672 facets/2,322 vertices; platform: 1,212 facets/608 vertices; each is one edge-connected, consistently wound 2-manifold shell with 0 boundary/overused/orientation/vertex-link errors |
| KiCad render/SVG export | generated review artifacts | top, bottom, isometric PNGs and top/bottom copper SVGs generated successfully |

### Datasheet basis inherited and rechecked

The critical pin/application review remains grounded in the manufacturer sources recorded in `hardware/datasheets/manifest.json` and `hardware/reports/schematic-validation.md`:

- **NAU7802SGI, Nuvoton Rev. 2.6:** pin table p.6, limits p.7, I2C p.13, channel-1 application p.24, package p.37. Structured extraction exists at `hardware/datasheets/extracted/NAU7802SGI.json`.
- **XIAO ESP32-C3 113991054:** Seeed pin documentation/schematic for D4 SDA, D5 SCL, D6 TX, D7 RX, 3V3/GND/VUSB.
- **USB4105-GF-A, JST GH, ASMT-YTC7, and protection parts:** manufacturer URLs are stored on schematic symbols. Physical pad-net parity was checked for every PCB pad; the manufacturer documents, not KiCad libraries, remain physical pinout ground truth.
- **TAL220B-5KG:** manufacturer drawing dimensions used by the OpenSCAD source are 55 × 12.7 × 12.7 mm, 40 mm hole-center spacing, and 5.2 mm passages for M5 hardware. Printed fit remains unverified.

## Component and connectivity summary

- 41 schematic footprints + four intentional board-only M3 mounting holes.
- 128 physical PCB pads / 124 unique pad IDs checked against 123 schematic netlist nodes plus J2's explicitly allowlisted, unnetted `MP` hold-down ID; duplicate USB shell/VBUS, switch, and `MP` pads account for the higher physical-pad count.
- 40 named/generated nets.
- 332 track segments and 46 vias, including five GND vias.
- Track width distribution: 13 × 0.15 mm neck-down segments, 296 × 0.20 mm, 14 × 0.25 mm, 9 × 0.50 mm.
- Two filled solid-connected GND pours and four antenna rule areas.
- Zero native unrouted items.

## Power tree and current paths

```text
USB-C J1 VBUS
  -> D1 TVS + C11
  -> F1 500 mA hold PPTC
  -> D2 reverse-current Schottky
  -> +5V_XIAO (C1/C2, TP2)
  -> XIAO module regulator
  -> +3V3 (C3/C4/C5, TP3, J3)
     -> U2 DVDD
     -> U2 internal LDO -> AVDD_3V0/excitation (C6, TP5, J2 E+)
```

Raw-file layout checks show 0.50 mm trunks on VBUS and protected +5 V, short 0.20 mm branches/neck-downs, and 0.20 mm low-current 3.3 V distribution. This is a USB/SELV-only board; no mains creepage or isolation requirement applies. Actual current, diode dissipation, and inrush were not measured.

## Precision analog and return strategy

- `/LC_S+` = 10.01 mm and `/LC_S-` = 11.04 mm; **1.04 mm delta**.
- `/AIN+` = 37.71 mm and `/AIN-` = 30.91 mm, including filter branches; **6.80 mm delta**.
- Bridge routes are low-bandwidth measurement nets rather than timing-constrained digital pairs. They are kept in the U2/J2 region and away from the XIAO antenna area.
- B.Cu is the preferred GND return plane; F.Cu adds local ground copper. Solid pad connections avoid a starved thermal at edge-mounted J3 GND and provide low-impedance return paths.
- No split analog/digital ground domain was introduced; the NAU7802 application circuit and board use one GND domain.

## RF/antenna constraints

Four layer-specific KiCad rule areas enforce:

1. no copper pour, tracks, vias, or pads beneath the transformed XIAO antenna region; and
2. no components/copper in the module clearance region.

Native DRC passes with both pours filled. The OpenSCAD assembly marks a no-metal/no-fastener antenna volume. RF performance, enclosure detuning, and radiated/conducted EMC remain unmeasured.

## Mechanical and overload design

The top platform attaches only to the load-cell sensing end; the PCB attaches to independent base standoffs. Intended force flow is:

```text
bin -> top plate/cradle -> free load-cell end -> fixed load-cell end -> base -> feet
```

The PCB is not a structural link. Four M4 adjustable stops are modeled with a nominal 0.8 mm CAD gap, but the README requires bench adjustment under a conservative proof load rather than trusting printer tolerance. Cable clamp holes are separate from the strain element. No print, fit check, finite-element analysis, or real load test has occurred.

The fixed and free M5 passages are centered on the TAL220B drawing's −20 mm and +20 mm hole centers. Each nylon-tip M4 set screw faces a solid 12 mm-diameter, 2 mm-thick underside pad; no adjustment hole passes through the collision surface. The reference model uses a 6.2 × 6 mm insert pocket and 13.2 mm screw engagement/projection. OpenSCAD assertions bind each printed mount origin to the cell centers and verify the screw-tip-to-pad gap equals 0.8 mm. Purchased insert/screw dimensions and proof-load adjustment are still mandatory.

## Thermal and manufacturing assessment

- No high-power regulator, MOSFET, exposed thermal pad, or mains component is present. U2 is SOIC-16 and U1 is a module. A junction-temperature script was not run; actual USB-path losses remain load-dependent.
- Minimum route is 0.15 mm; general routing is 0.20 mm; vias are 0.60/0.30 mm. Fabricator capability has not yet been checked against a selected process.
- J1 VBUS uses two bottom-tented through via-in-pad transitions. This is the main assembly-process concern.
- Ten test points cover input/protected rails, GND, AVDD, I2C, bridge inputs, and VBG; J3 provides 3.3 V UART.
- Connector functions and pin 1 are labeled on F.SilkS. Review PNG/SVG artifacts are generated from the committed board.

## Sourcing and BOM

Schematic symbol properties remain the source of truth; `bom/bom.csv` is generated from them. `bom/non-schematic-items.csv` now separately includes printed base/platform, load-cell hardware, PCB standoffs, cable-clamp hardware, feet, and overload-stop hardware with TBD cost where no part was actually selected.

A 2026-08-26 public-search refresh confirmed current product mappings for J1, J2, U2, and U1 but did not provide API-grade quotes. Conflicting indexed prices and the dated J2 stock observation remain explicit. No stock, price, or lifecycle status is represented as guaranteed.

## False positives / reviewer overrides

- Early parity runs reported H1–H4 as extra footprints. They are intentional mechanical holes and are now marked board-only; final parity reports zero issues.
- KiCad library-sync checks report board-local overrides on footprints loaded by the deterministic generator, plus the project-local XIAO nickname in the headless container. `lib_footprint_mismatch` and `lib_footprint_issues` are explicitly ignored at project level; this does not suppress copper, clearance, connectivity, keepout, or footprint-placement DRC. `validate_hardware.py` protects the two-waiver set, resolves every populated footprint, checks critical pad sets, and `validate_pcb.py` compares every electrical pad to the exported schematic netlist.
- The two GND pours initially produced one starved thermal at J3. This was not waived: both planes now use solid pad connections and final DRC is clean.
- Early post-route GND stitch vias were reported dangling before fills. The generator no longer preplaces them; the final route has five connected GND vias and filled planes.
- FreeRouting’s internal “violations” count was not accepted as authoritative. The imported result was iterated until native KiCad DRC reported zero violations and zero opens.
- Issue #3’s I2C voltage-domain, DRDY pull-up, and RGB-limiting analyzer findings remain documented detector false positives; native ERC and the raw pin/net assertions pass.

## Not performed / review limits

- **KiCad MCP PCB audit:** attempted twice; failed because the MCP environment lacked the `pcbnew` module.
- **`analyze_schematic.py`, `analyze_pcb.py --full`, cross-analysis, thermal analyzer:** not present in the installed skill directory; no JSON claims were fabricated.
- **EMC analyzer:** not available locally. Plane continuity/antenna keepouts were checked through raw board structure and native DRC only.
- **SPICE:** not run; `ngspice`, `ltspice`, and `xyce` were unavailable.
- **Gerber/drill/CPL analysis:** intentionally not run because issue #6 does not create fabrication release files; issue #7 owns that gate.
- **Lifecycle audit:** not rerun; distributor APIs/bulk catalog were unavailable without credentials or accepting terms on the user’s behalf.
- **Full per-MPN extraction:** only the critical NAU7802 has a structured extraction; other manufacturer checks are inherited manual review.
- **Physical validation:** no continuity, power, USB, RF/EMC, thermal, noise, calibration, fit, overload, environmental, or field test.
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

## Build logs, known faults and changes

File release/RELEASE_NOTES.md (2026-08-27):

# Parts Tally v0.1.0-rc.1

This is the first integrated hardware/firmware/app **release candidate** for quote, peer review, fabrication review, and eventual physical bring-up.

## Compatibility

- carrier board A0
- firmware 0.2.0
- protocol `parts-tally/v1`
- companion app 0.1.0
- persistent-state schema 3 / calibration schema 2

## Included

- editable KiCad 9 schematic/PCB/project and project-local libraries;
- editable OpenSCAD fixture source and generated reference STLs;
- KiCad-generated Gerber X2, separate PTH/NPTH drill files, drill map, placement/CPL, schematic PDF, assembly drawings, and renders;
- schematic-backed BOM plus a JLCPCB-format parity-checked BOM;
- firmware/app source, protocol schemas, assembly/bring-up procedure, release manifest, license notices, reports, and SHA-256 checksums.

## Verification state

Static hardware validators, native KiCad ERC/DRC/parity, firmware native tests/static analysis/target compile, app lint/type/unit/accessibility/e2e/build, protocol contract tests, mechanical compilation/manifold checks, and archive integrity are required release gates. See `docs/release-verification.md` and the GitHub Actions run attached to the tag.

No physical prototype exists. Continuity, USB current, rails, bridge excitation, ADC raw behavior, noise, repeatability, hysteresis, warm-up drift, creep, off-center response, disconnect/saturation/overload handling, RF/EMC, thermal, calibration, known-count, and field tests remain pending. No render or software/static result is presented as physical evidence.

## Fabrication warnings

- J1 uses two bottom-tented but unfilled through-vias in VBUS pads. Obtain explicit assembler approval for solder-wicking risk or use documented hand rework/inspection.
- The JLCPCB BOM has blank LCSC IDs for user-sourced parts and is not a turnkey order.
- Public C189895 stock results remain contradictory. Re-check the exact JST connector and all sourcing facts at checkout.
- Preserve USB/SELV-only, non-certified, non-legal-for-trade scope and explicit uncertainty/fault states.

Closes #7.

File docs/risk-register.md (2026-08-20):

# Parts Tally risk register

**Register version:** 1.1
**Baseline date:** 2026-08-20

Likelihood and impact are design-time estimates (`Low`, `Medium`, `High`) rather than measured probabilities. Residual risk cannot be closed until the named evidence exists.

| ID | Hazard / failure mode | L | I | Consequence | Preventive/detective controls | Verification stage and evidence | Owner / issue | Residual status |
|---|---|---:|---:|---|---|---|---|---|
| RISK-ANALOG-01 | USB, digital, or RF noise corrupts the bridge measurement | High | High | Unstable or biased counts that appear plausible | Selected NAU7802 at initial 10 SPS/PGA128; 3.3 V DVDD/3.0 V AVDD boundary review; short paired bridge wiring; ground/return strategy; RF-condition measurements; stability/uncertainty gate | Datasheet review #2; NOISE-01; schematic/ERC #3; PCB/EMC/DRC #6 | Hardware/measurement (#2/#3/#4/#6) | Open; ADC selected and static checks complete, but excitation/noise/RF interaction unmeasured |
| RISK-RF-01 | Antenna is blocked by copper, cell metal, fasteners, or enclosure | Medium | Medium | Poor provisioning/reconnect, sampling interactions | XIAO 113991054 selected; preserve manufacturer antenna clearance; prototype clearance; enforceable all-layer/component/mechanical rule areas; avoid analog routing near antenna | Manufacturer guidance #2; layout audits #6; WIFI-01 and NOISE-01 | Hardware/mechanical (#2/#6) | Open; controller selected but fixture/enclosure geometry absent |
| RISK-MECH-01 | Overload/off-center force damages cell or routes load through PCB/connectors | Medium | High | Damage, sudden shift, misleading calibration, possible falling bin | TAL220B 5 kg selected; separate base/cell/top-plate load path; rated-load derating; rigid mounts; non-slip feet; adjustable stops; strain relief; prohibit unsupported loading | Datasheet/fixture review #2; CAD/DRC #6; OFFCENTER-01/OVR-01; post-test zero/span | Mechanical (#2/#6/#7) | Open; 120% safe-overload document exists but no fixture/stops/load evidence |
| RISK-CAL-01 | Wrong bin/sample count, unstable tare, or corrupt calibration is committed | Medium | High | Consistently wrong counts | Guided `Ncal >= 10`; stable/healthy gates; unit mass `>=20B`; atomic versioned storage; retain prior valid record; calibration audit metadata | Synthetic misuse/migration tests #4; COUNT-01; app E2E #5 | Firmware/app (#4/#5) | Open; domain and UI not implemented |
| RISK-CRED-01 | Lost/leaked local secret, unsafe reset, or insecure update locks out device or exposes mutation | Medium | Medium | Unauthorized changes or unrecoverable setup | Physical-presence setup/reset; per-device secret; no secrets in URL/log/export/cache; credential rotation; USB recovery; integrity/authenticity if OTA exists | Threat/protocol review #4; protocol tests; log/export tests; recovery procedure #7 | Firmware/app (#4/#5/#7) | Open; TLS/residual LAN decision pending |
| RISK-SOURCE-01 | Prototype candidate is retired, unavailable, wrong revision, or unsuitable for carrier | High | Medium | Unbuildable design or invalid pin/application assumptions | Exact 113991054/SEN-15242/NAU7802SGI/SEN-14729 selection; manufacturer source/hash manifest; 2026-08-20 price/stock snapshot; HX711 comparison; schematic properties as final BOM source | Selection record #2; BOM/datasheet audit #3/#7 | Hardware/BOM (#2/#3/#7) | Reduced but open: selection/source mismatch corrected; transient stock and actual purchased revisions must be rechecked |
| RISK-COUNT-01 | Unit variation, mixed/wet/corroded parts, drift, or rounding makes count misleading | High | High | User acts on incorrect stock state | Explicit uncertainty; no-count faults; minimum usable unit mass; known-count calibration; correction audit reason; unsuitable-part warning; non-certified disclaimer | Synthetic golden tests #4; REP-01/COUNT-01; accessible status tests #5; field evidence #7 | Measurement/product (#1/#4/#5/#7) | Open; only design model exists |

## Escalation rules

- A risk with High impact cannot be marked closed using only documentation or a render.
- A datasheet mitigates part-selection uncertainty but does not prove a specific assembly or layout.
- Synthetic tests prove deterministic policy behavior, not sensor performance.
- Bench tests require raw data and exact revisions; field evidence remains separate.
- Any newly discovered serious-harm use case is rejected rather than expanded into scope.

## Review cadence

Review this register at the start and end of issues #2 through #7. Each PR must update controls, evidence links, and residual status without deleting historical risks merely because work moved to another stage.

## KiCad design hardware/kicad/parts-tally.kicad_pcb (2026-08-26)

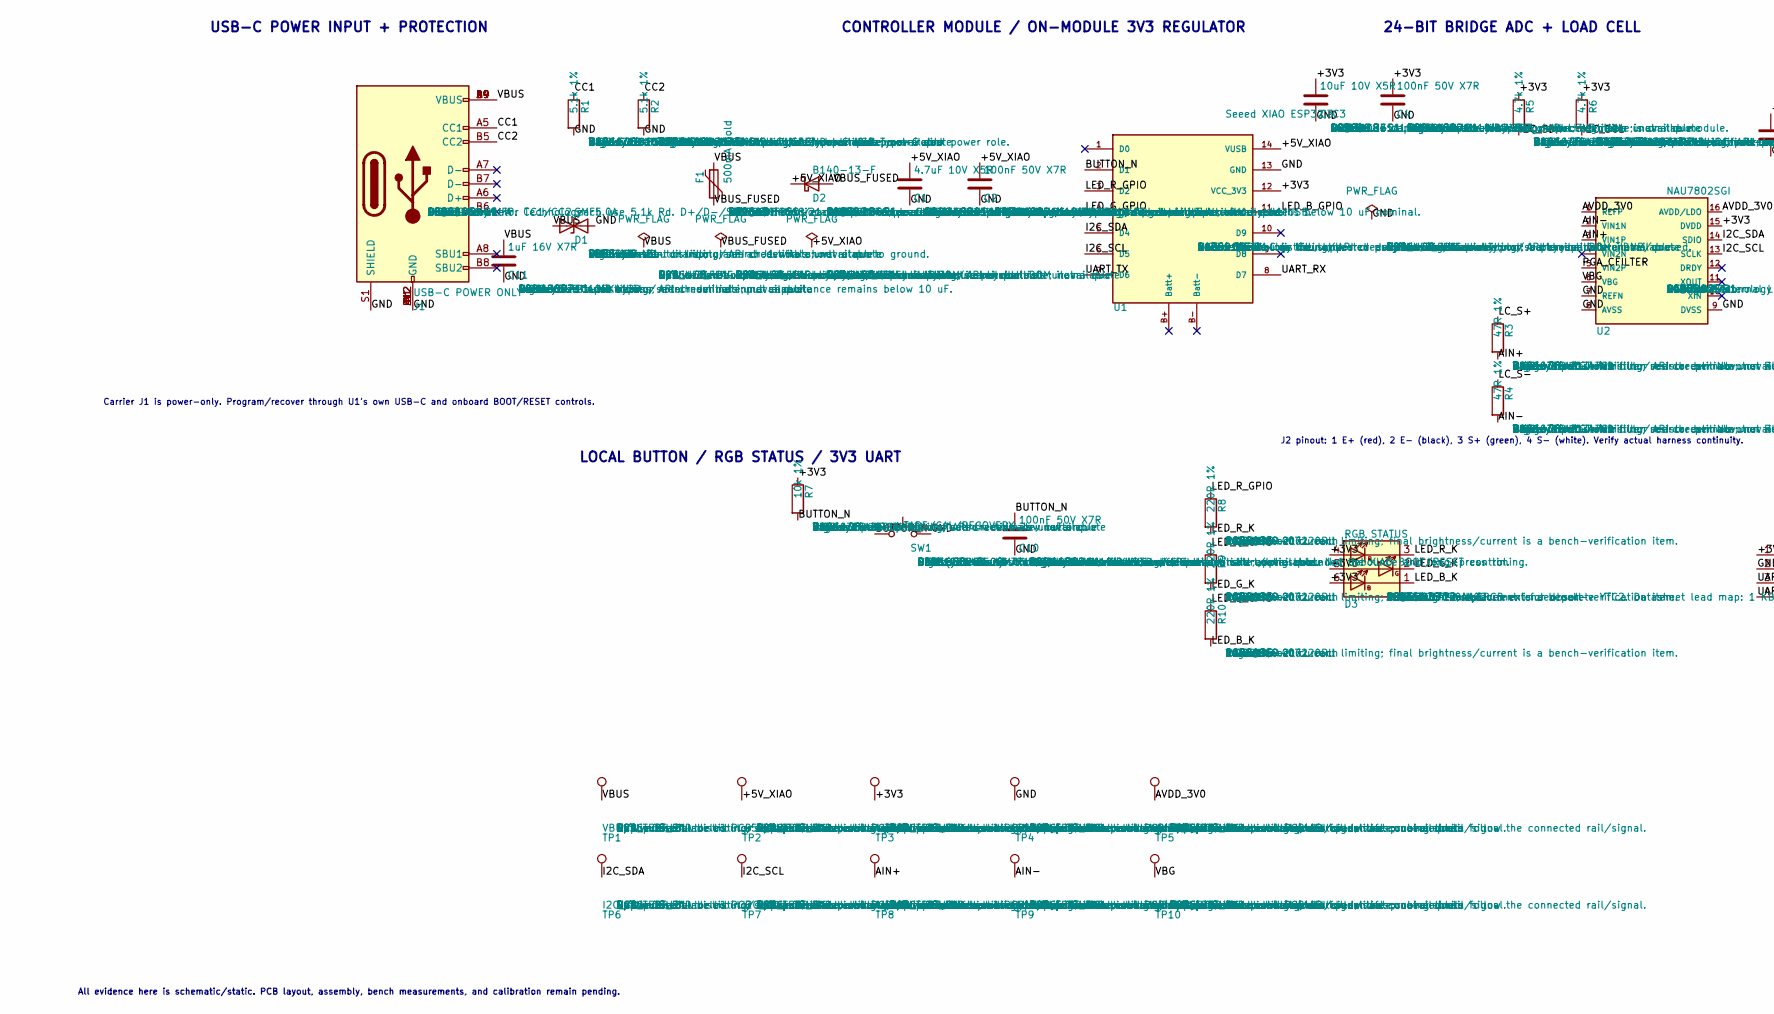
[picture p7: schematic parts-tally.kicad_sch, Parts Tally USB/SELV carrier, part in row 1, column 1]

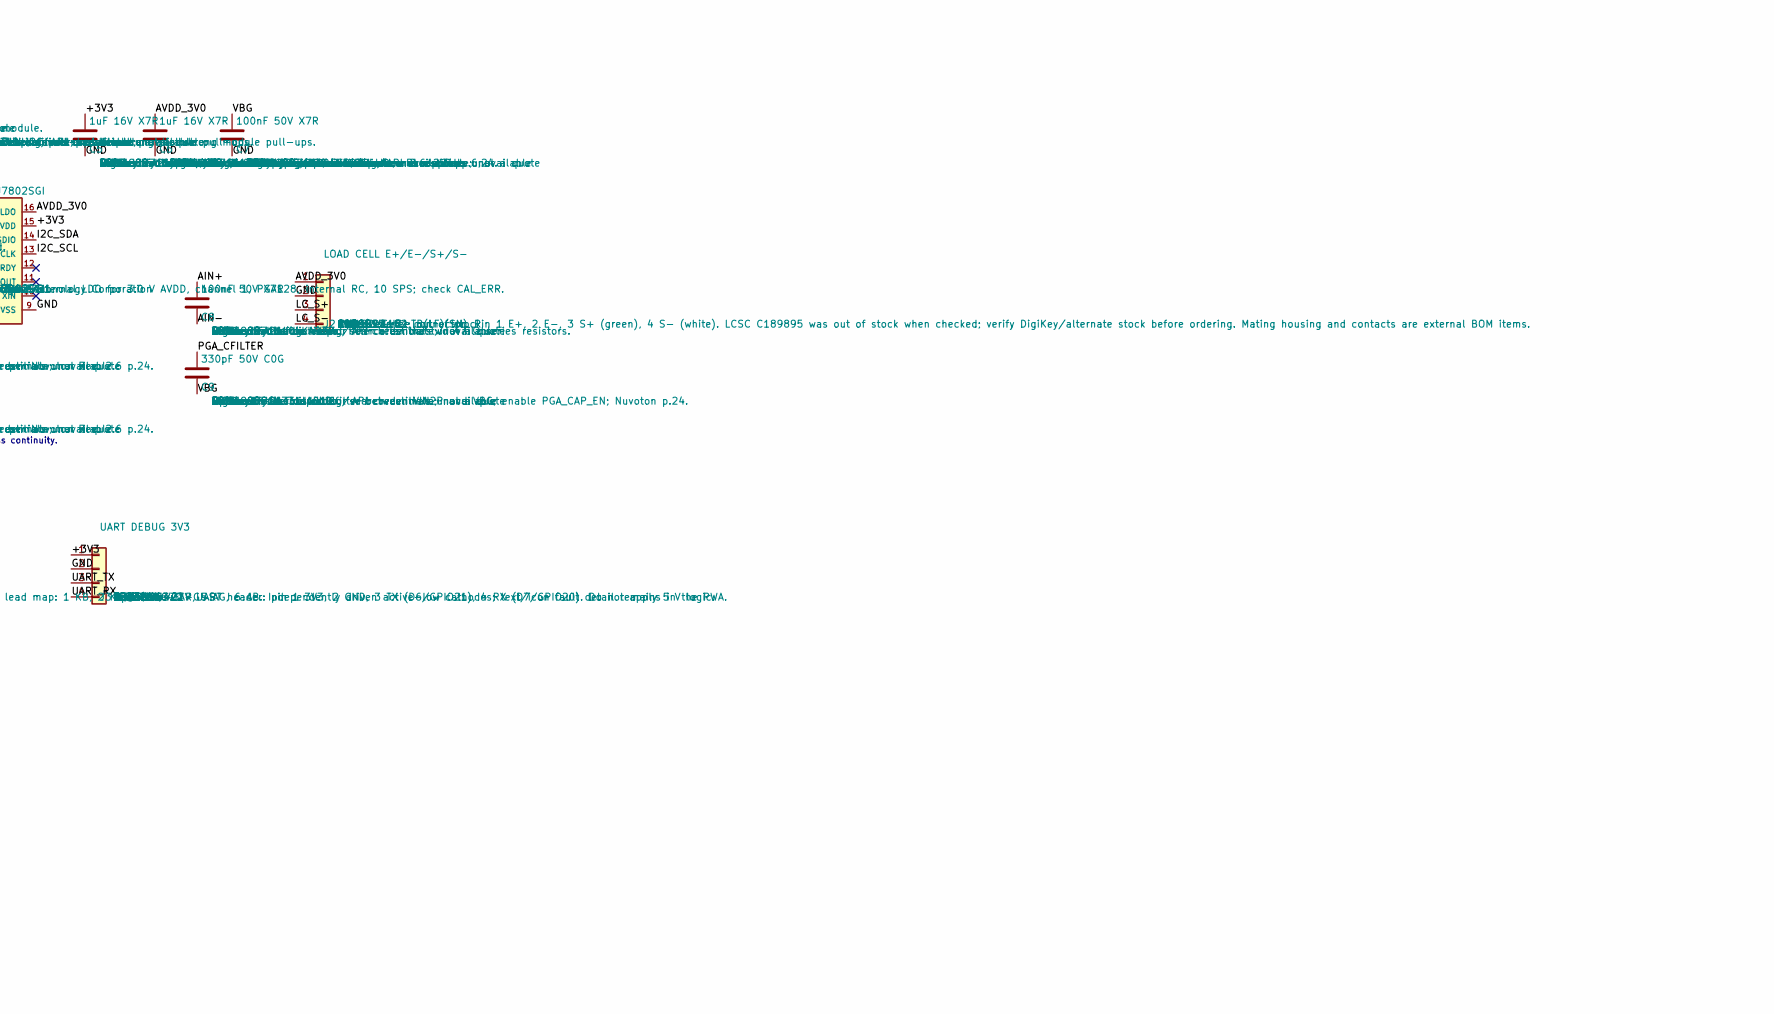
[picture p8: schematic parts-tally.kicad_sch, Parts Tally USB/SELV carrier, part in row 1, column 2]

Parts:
C1: 4.7uF 10V X5R; C_1206_3216Metric; MPN GRM31CR61A475KA01L
C2, C4, C7, C8, C10: 100nF 50V X7R; C_0603_1608Metric; MPN GRM188R71H104KA93D
C3: 10uF 10V X5R; C_1206_3216Metric; MPN GRM31CR61A106KA01L
C5, C6, C11: 1uF 16V X7R; C_0603_1608Metric; MPN GRM188R71C105KA12D
C9: 330pF 50V C0G; C_0603_1608Metric; MPN GRM1885C1H331JA01D
D1: SMF5.0A; D_SOD-123F; MPN SMF5.0A
D2: B140-13-F; D_SMA; MPN B140-13-F
D3: RGB STATUS; LED_Avago_PLCC6_3x2.8mm; MPN ASMT-YTC7-0AA02
F1: 500mA hold; Fuse_1812_4532Metric; MPN MF-MSMF050-2
J1: USB-C POWER ONLY; USB_C_Receptacle_GCT_USB4105-xx-A_16P_TopMnt_Horizontal; MPN USB4105-GF-A
J2: LOAD CELL E+/E-/S+/S-; JST_GH_SM04B-GHS-TB_1x04-1MP_P1.25mm_Horizontal; MPN SM04B-GHS-TB(LF)(SN)
J3: UART DEBUG 3V3; PinHeader_1x04_P2.54mm_Vertical; MPN TSW-104-07-G-S
R1, R2: 5.1k 1%; R_0603_1608Metric; MPN RC0603FR-075K1L
R3, R4: 47R 1%; R_0603_1608Metric; MPN RC0603FR-0747RL
R5, R6: 4.7k 1%; R_0603_1608Metric; MPN RC0603FR-074K7L
R7: 10k 1%; R_0603_1608Metric; MPN RC0603FR-0710KL
R8, R9, R10: 220R 1%; R_0603_1608Metric; MPN RC0603FR-07220RL
SW1: TARE/CAL/RECOVERY; SW_SPST_PTS810; MPN PTS810SJM250SMTRLFS
TP1: VBUS; TestPoint_Pad_D1.5mm; MPN PCB_TEST_PAD
TP2: +5V_XIAO; TestPoint_Pad_D1.5mm; MPN PCB_TEST_PAD
TP3: +3V3; TestPoint_Pad_D1.5mm; MPN PCB_TEST_PAD
TP4: GND; TestPoint_Pad_D1.5mm; MPN PCB_TEST_PAD
TP5: AVDD_3V0; TestPoint_Pad_D1.5mm; MPN PCB_TEST_PAD
TP6: I2C_SDA; TestPoint_Pad_D1.5mm; MPN PCB_TEST_PAD
TP7: I2C_SCL; TestPoint_Pad_D1.5mm; MPN PCB_TEST_PAD
TP8: AIN+; TestPoint_Pad_D1.5mm; MPN PCB_TEST_PAD
TP9: AIN-; TestPoint_Pad_D1.5mm; MPN PCB_TEST_PAD
TP10: VBG; TestPoint_Pad_D1.5mm; MPN PCB_TEST_PAD
U1: Seeed XIAO ESP32-C3; XIAO_ESP32C3; MPN 113991054
U2: NAU7802SGI; SOIC-16_3.9x9.9mm_P1.27mm; MPN NAU7802SGI

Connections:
/+3V3: C3.1, C4.1, C5.1, D3.4 (AR), D3.5 (AG), D3.6 (AB), J3.1, R5.1, R6.1, R7.1, TP3.1, U1.12 (VCC_3V3), U2.15 (DVDD)
/+5V_XIAO: C1.1, C2.1, D2.1 (K), TP2.1, U1.14 (VUSB)
/AIN+: C8.1, R3.2, TP8.1, U2.3 (VIN1P)
/AIN-: C8.2, R4.2, TP9.1, U2.2 (VIN1N)
/AVDD_3V0: C6.1, J2.1, TP5.1, U2.1 (REFP), U2.16 (AVDD/LDO)
/BUTTON_N: C10.1, R7.2, SW1.1, U1.2 (D1)
/CC1: J1.A5 (CC1), R1.1
/CC2: J1.B5 (CC2), R2.1
/GND: C1.2, C2.2, C3.2, C4.2, C5.2, C6.2, C7.2, C10.2, C11.2, D1.2 (A2), J1.A1 (GND), J1.A12 (GND), J1.B1 (GND), J1.B12 (GND), J1.S1 (SHIELD), J2.2, J3.2, R1.2, R2.2, SW1.2, TP4.1, U1.13 (GND), U2.7 (REFN), U2.8 (AVSS), U2.9 (DVSS)
/I2C_SCL: R6.2, TP7.1, U1.6 (D5), U2.13 (SCLK)
/I2C_SDA: R5.2, TP6.1, U1.5 (D4), U2.14 (SDIO)
/LC_S+: J2.3, R3.1
/LC_S-: J2.4, R4.1
/LED_B_GPIO: R10.1, U1.11 (D10)
/LED_B_K: D3.1 (KB), R10.2
/LED_G_GPIO: R9.1, U1.4 (D3)
/LED_G_K: D3.2 (KG), R9.2
/LED_R_GPIO: R8.1, U1.3 (D2)
/LED_R_K: D3.3 (KR), R8.2
/PGA_CFILTER: C9.1, U2.5 (VIN2P)
/UART_RX: J3.4, U1.8 (D7)
/UART_TX: J3.3, U1.7 (D6)
/VBG: C7.1, C9.2, TP10.1, U2.6 (VBG)
/VBUS: C11.1, D1.1 (A1), F1.1, J1.A4 (VBUS), J1.A9 (VBUS), J1.B4 (VBUS), J1.B9 (VBUS), TP1.1
/VBUS_FUSED: D2.2 (A), F1.2

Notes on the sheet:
USB-C POWER INPUT + PROTECTION
CONTROLLER MODULE / ON-MODULE 3V3 REGULATOR
24-BIT BRIDGE ADC + LOAD CELL
LOCAL BUTTON / RGB STATUS / 3V3 UART
Carrier J1 is power-only. Program/recover through U1's own USB-C and onboard BOOT/RESET controls.
J2 pinout: 1 E+ (red), 2 E- (black), 3 S+ (green), 4 S- (white). Verify actual harness continuity.
All evidence here is schematic/static. PCB layout, assembly, bench measurements, and calibration remain pending.

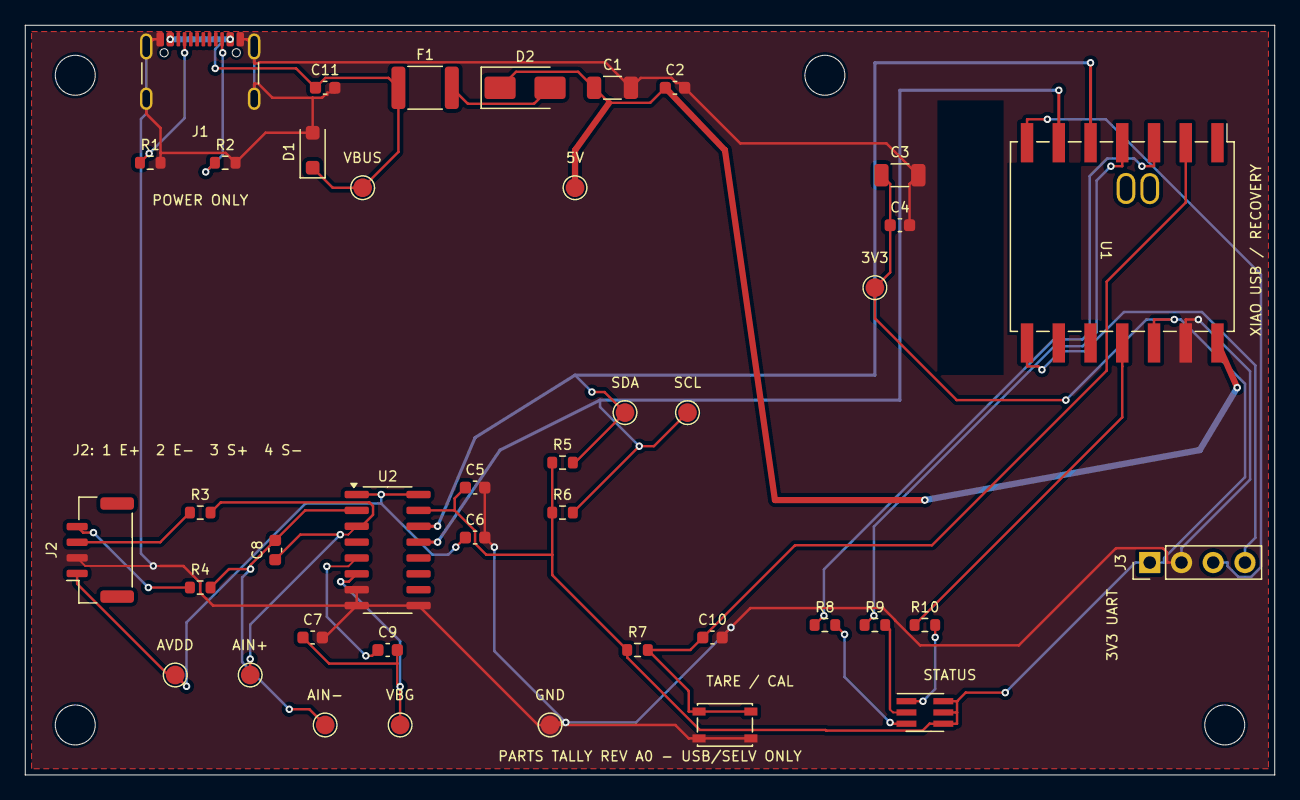
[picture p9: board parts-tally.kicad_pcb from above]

Board: 2 copper layers, 100.0 x 60.0 mm, 45 parts (0 on the bottom side), 25 nets.

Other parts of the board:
H1, H2, H3, H4: M3 PCB MOUNT - NOT IN SCALE FORCE PATH; MountingHole_3.2mm_M3

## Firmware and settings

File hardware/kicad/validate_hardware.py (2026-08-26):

#!/usr/bin/env python3
"""Static acceptance checks for the issue #3 editable KiCad schematic."""

from __future__ import annotations

import json
import os
import re
import sys
from collections import defaultdict
from pathlib import Path

ROOT = Path(__file__).resolve().parents[2]
SCHEMATIC = ROOT / "hardware" / "kicad" / "parts-tally.kicad_sch"
PROJECT = ROOT / "hardware" / "kicad" / "parts-tally.kicad_pro"
CUSTOM_LIBRARY = ROOT / "hardware" / "kicad" / "lib" / "parts-tally.kicad_sym"
XIAO_FOOTPRINT = ROOT / "hardware" / "kicad" / "lib" / "parts-tally.pretty" / "XIAO_ESP32C3.kicad_mod"
EXTRACTION = ROOT / "hardware" / "datasheets" / "extracted" / "NAU7802SGI.json"
BOM = ROOT / "bom" / "bom.csv"


def fail(message: str) -> None:
    print(f"ERROR: {message}", file=sys.stderr)
    raise SystemExit(1)


def prop(component, name: str) -> str:
    value = component.get_property(name)
    if isinstance(value, dict):
        value = value.get("value")
    return "" if value is None else str(value)


def rounded_point(x: float, y: float) -> tuple[float, float]:
    return (round(float(x), 2), round(float(y), 2))


def pin_point(component, symbol_definition, pin_number: str) -> tuple[float, float]:
    if component.rotation != 0:
        fail(f"{component.reference} is rotated; validator transform needs extension")
    pin = symbol_definition.get_pin(pin_number)
    if pin is None:
        fail(f"{component.reference} has no pin {pin_number}")
    return rounded_point(component.position.x + pin.position.x, component.position.y - pin.position.y)


def main() -> int:
    os.environ.setdefault("KICAD_SYMBOL_DIR", "/usr/share/kicad/symbols")
    from kicad_sch_api import get_symbol_cache, load_schematic

    if not SCHEMATIC.exists():
        fail(f"missing schematic: {SCHEMATIC}")
    project = json.loads(PROJECT.read_text(encoding="utf-8"))
    erc_severities = project.get("erc", {}).get("rule_severities", {})
    expected_waivers = {
        "footprint_link_issues": "ignore",
        "lib_symbol_mismatch": "ignore",
    }
    if erc_severities != expected_waivers:
        fail(
            "project must retain the two documented headless ERC waivers; "
            f"found {erc_severities!r}"
        )
    board_severities = project.get("board", {}).get("design_settings", {}).get(
        "rule_severities", {}
    )
    expected_board_waivers = {
        "lib_footprint_issues": "ignore",
        "lib_footprint_mismatch": "ignore",
    }
    actual_board_waivers = {
        rule: board_severities.get(rule) for rule in expected_board_waivers
    }
    if actual_board_waivers != expected_board_waivers:
        fail(
            "project must retain the two documented library-only DRC waivers; "
            f"found {actual_board_waivers!r}"
        )
    cache = get_symbol_cache()
    symbol_dir = Path(os.environ["KICAD_SYMBOL_DIR"])
    if symbol_dir.is_dir():
        cache.discover_libraries([str(symbol_dir)])
    cache.add_library_path(str(CUSTOM_LIBRARY))
    schematic = load_schematic(SCHEMATIC)
    components = {component.reference: component for component in schematic.components.all()}
    symbol_defs = {
        reference: cache.get_symbol(component.lib_id)
        for reference, component in components.items()
    }
    if missing_defs := [ref for ref, definition in symbol_defs.items() if definition is None]:
        fail(f"could not resolve symbol definitions for {missing_defs}")

    required_refs = {"J1", "J2", "J3", "U1", "U2", "F1", "D1", "D2", "D3", "SW1"}
    if missing := required_refs - components.keys():
        fail(f"missing required symbols: {sorted(missing)}")

    required_properties = [
        "Manufacturer", "MPN", "Supplier", "Datasheet",
        "Estimated Unit Cost USD", "Price Observed UTC", "BOM Comments",
    ]
    bom_components = [
        component for component in components.values()
        if component.in_bom and not component.reference.startswith("#")
    ]
    if len(bom_components) != 31:
        fail(f"expected 31 populated schematic components, found {len(bom_components)}")
    for component in bom_components:
        if not component.footprint:
            fail(f"{component.reference} has no footprint")
        for field in required_properties:
            if not prop(component, field).strip():
                fail(f"{component.reference} missing {field}")

    expected_u2_pins = {
        "1": "REFP", "2": "VIN1N", "3": "VIN1P", "4": "VIN2N",
        "5": "VIN2P", "6": "VBG", "7": "REFN", "8": "AVSS",
        "9": "DVSS", "10": "XIN", "11": "XOUT", "12": "DRDY",
        "13": "SCLK", "14": "SDIO", "15": "DVDD", "16": "AVDD/LDO",
    }
    for number, expected_name in expected_u2_pins.items():
        actual = symbol_defs["U2"].get_pin(number)
        if actual is None or actual.name != expected_name:
            fail(f"U2 pin {number}: expected {expected_name}, got {getattr(actual, 'name', None)}")

    expected_u1_pins = {
        "1": "D0", "2": "D1", "3": "D2", "4": "D3", "5": "D4",
        "6": "D5", "7": "D6", "8": "D7", "9": "D8", "10": "D9",
        "11": "D10", "12": "VCC_3V3", "13": "GND", "14": "VUSB",
        "B+": "Batt+", "B-": "Batt-",
    }
    for number, expected_name in expected_u1_pins.items():
        actual = symbol_defs["U1"].get_pin(number)
        if actual is None or actual.name != expected_name:
            fail(f"U1 pin {number}: expected {expected_name}, got {getattr(actual, 'name', None)}")

    expected_d3_pins = {
        "1": "KB", "2": "KG", "3": "KR", "4": "AR", "5": "AG", "6": "AB",
    }
    for number, expected_name in expected_d3_pins.items():
        actual = symbol_defs["D3"].get_pin(number)
        if actual is None or actual.name != expected_name:
            fail(f"D3 pin {number}: expected {expected_name}, got {getattr(actual, 'name', None)}")
    if prop(components["D3"], "MPN") != "ASMT-YTC7-0AA02":
        fail("D3 must use the current ASMT-YTC7-0AA02 replacement")

    footprint_text = XIAO_FOOTPRINT.read_text(encoding="utf-8")
    footprint_pads = set(re.findall(r'\(pad\s+"([^"]+)"', footprint_text))
    expected_xiao_pads = {str(number) for number in range(1, 15)} | {"B+", "B-"}
    if footprint_pads != expected_xiao_pads:
        fail(f"XIAO footprint pads differ from header/battery map: {sorted(footprint_pads)}")

    footprint_dir = Path(os.environ.get("KICAD_FOOTPRINT_DIR", "/usr/share/kicad/footprints"))

    def resolve_footprint(footprint: str) -> Path:
        library, name = footprint.split(":", 1)
        if library == "parts-tally":
            return ROOT / "hardware" / "kicad" / "lib" / "parts-tally.pretty" / f"{name}.kicad_mod"
        return footprint_dir / f"{library}.pretty" / f"{name}.kicad_mod"

    for component in bom_components:
        footprint_path = resolve_footprint(component.footprint)
        if not footprint_path.exists():
            fail(f"{component.reference} footprint does not resolve: {component.footprint}")

    expected_critical_pad_sets = {
        "J1": {"A1", "A4", "A5", "A6", "A7", "A8", "A9", "A12", "B1", "B4", "B5", "B6", "B7", "B8", "B9", "B12", "S1"},
        "J2": {"1", "2", "3", "4", "MP"},
        "J3": {"1", "2", "3", "4"},
        "U1": expected_xiao_pads,
        "U2": {str(number) for number in range(1, 17)},
        "D3": {str(number) for number in range(1, 7)},
    }
    for reference, expected_pads in expected_critical_pad_sets.items():
        footprint_path = resolve_footprint(components[reference].footprint)
        actual_pads = set(re.findall(r'\(pad\s+"([^"]+)"', footprint_path.read_text(encoding="utf-8")))
        if actual_pads != expected_pads:
            fail(f"{reference} footprint pad set mismatch: {sorted(actual_pads)}")

    text = SCHEMATIC.read_text(encoding="utf-8")
    label_pattern = re.compile(r'\(label\s+"([^"]+)"\s*\n\s*\(at\s+([-0-9.]+)\s+([-0-9.]+)')
    labels_at: dict[tuple[float, float], set[str]] = defaultdict(set)
    for net, x, y in label_pattern.findall(text):
        labels_at[rounded_point(float(x), float(y))].add(net)
    if len(labels_at) < 35:
        fail(f"expected at least 35 labeled connection points, found {len(labels_at)}")
    for point, names in labels_at.items():
        if len(names) > 1:
            fail(f"conflicting labels at {point}: {sorted(names)}")

    expected_connections = {
        ("J1", "A5"): "CC1", ("J1", "B5"): "CC2", ("J1", "A4"): "VBUS",
        ("U1", "14"): "+5V_XIAO", ("U1", "12"): "+3V3", ("U1", "13"): "GND",
        ("U1", "5"): "I2C_SDA", ("U1", "6"): "I2C_SCL",
        ("U1", "2"): "BUTTON_N", ("U1", "7"): "UART_TX", ("U1", "8"): "UART_RX",
        ("U2", "1"): "AVDD_3V0", ("U2", "2"): "AIN-", ("U2", "3"): "AIN+",
        ("U2", "5"): "PGA_CFILTER", ("U2", "6"): "VBG", ("U2", "7"): "GND",
        ("U2", "13"): "I2C_SCL", ("U2", "14"): "I2C_SDA",
        ("U2", "15"): "+3V3", ("U2", "16"): "AVDD_3V0",
        ("J2", "1"): "AVDD_3V0", ("J2", "2"): "GND",
        ("J2", "3"): "LC_S+", ("J2", "4"): "LC_S-",
        ("J3", "1"): "+3V3", ("J3", "2"): "GND",
        ("J3", "3"): "UART_TX", ("J3", "4"): "UART_RX",
        ("D3", "1"): "LED_B_K", ("D3", "2"): "LED_G_K", ("D3", "3"): "LED_R_K",
        ("D3", "4"): "+3V3", ("D3", "5"): "+3V3", ("D3", "6"): "+3V3",
        ("R8", "1"): "LED_R_GPIO", ("R8", "2"): "LED_R_K",
        ("R9", "1"): "LED_G_GPIO", ("R9", "2"): "LED_G_K",
        ("R10", "1"): "LED_B_GPIO", ("R10", "2"): "LED_B_K",
    }
    for (reference, pin), expected_net in expected_connections.items():
        point = pin_point(components[reference], symbol_defs[reference], pin)
        if expected_net not in labels_at.get(point, set()):
            fail(f"{reference}.{pin} at {point}: expected label {expected_net}, got {labels_at.get(point)}")

    nc_pattern = re.compile(r'\(no_connect\s*\n\s*\(at\s+([-0-9.]+)\s+([-0-9.]+)')
    nc_points = {rounded_point(float(x), float(y)) for x, y in nc_pattern.findall(text)}
    expected_nc = {
        ("J1", "A6"), ("J1", "A7"), ("J1", "A8"),
        ("J1", "B6"), ("J1", "B7"), ("J1", "B8"),
        ("U1", "1"), ("U1", "9"), ("U1", "10"), ("U1", "B+"), ("U1", "B-"),
        ("U2", "4"), ("U2", "10"), ("U2", "11"), ("U2", "12"),
    }
    for reference, pin in expected_nc:
        point = pin_point(components[reference], symbol_defs[reference], pin)
        if point not in nc_points:
            fail(f"{reference}.{pin} at {point} lacks an intentional no-connect marker")

    extraction = json.loads(EXTRACTION.read_text(encoding="utf-8"))
    if extraction["source"]["mpn"] != "NAU7802SGI":
        fail("NAU7802 extraction MPN mismatch")
    extracted_pins = {
        number: pin["name"]
        for pin in extraction["base"]["pinout"]
        for number in pin["numbers"]
    }
    if extracted_pins != expected_u2_pins:
        fail("NAU7802 cached datasheet pinout differs from the checked symbol map")
    if extraction["extraction"]["quality_score"] < 90:
        fail("NAU7802 extraction quality score is below 90")

    if not BOM.exists() or BOM.stat().st_size < 1000:
        fail("bom/bom.csv is missing or unexpectedly small")
    if "Estimated Unit Cost USD" not in BOM.read_text(encoding="utf-8").splitlines()[0]:
        fail("BOM lacks cost provenance columns")

    print(
        "hardware validation passed: "
        f"{len(components)} symbols, {len(bom_components)} BOM components, "
        f"{len(labels_at)} labeled points, {len(nc_points)} intentional NC points, "
        f"{len(extracted_pins)} datasheet-checked NAU7802 pins, "
        f"{len(expected_d3_pins)} datasheet-checked RGB LED pins, "
        f"{len(footprint_pads)} checked XIAO footprint pads, "
        f"{len({component.footprint for component in bom_components})} resolved populated footprints"
    )
    return 0


if __name__ == "__main__":
    raise SystemExit(main())

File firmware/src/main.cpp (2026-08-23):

#include <Arduino.h>
#include <WiFi.h>
#include <esp_system.h>

#include <cstdio>
#include <string>

#include "drivers/arduino_adapters.hpp"
#include "drivers/target_transport.hpp"
#include "parts_tally/factory_reset.hpp"
#include "parts_tally/measurement.hpp"
#include "parts_tally/persistence.hpp"
#include "parts_tally/protocol.hpp"

using namespace parts_tally;

namespace {

std::string random_token();
void start_sta(const std::string& ssid, const std::string& password);

ArduinoClock clock_source;
CarrierButton button;
ActiveLowRgb indicator;
Nau7802Adc adc;
MeasurementPipeline pipeline;
PreferencesStorage storage;
Persistence persistence(storage);
PersistentState state;
ProtocolGuard guard("http://192.168.4.1");
ApiService api("pt-esp32c3", guard, pipeline, state, []() { return persistence.save(state); },
               random_token, start_sta);
LocalTransport transport(api);
ButtonPolicy button_policy(storage);
std::uint64_t last_event_ms{};
MeasurementState last_event_state{MeasurementState::stale};

std::string random_token() {
  char token[33]{};
  std::snprintf(token, sizeof(token), "%08lx%08lx%08lx%08lx",
                static_cast<unsigned long>(esp_random()), static_cast<unsigned long>(esp_random()),
                static_cast<unsigned long>(esp_random()), static_cast<unsigned long>(esp_random()));
  return token;
}

void start_sta(const std::string& ssid, const std::string& password) {
  transport.begin_sta(ssid, password);
}

void show_reset_progress(ResetProgress progress, std::uint64_t now_ms) {
  if (progress == ResetProgress::warning) {
    const bool phase = ((now_ms / 250) % 2) == 0;
    indicator.set(phase, false, !phase);
  } else if (progress == ResetProgress::holding) {
    indicator.set(false, false, true);
  }
}

}  // namespace

void setup() {
  Serial.begin(115200);
  button.begin();
  indicator.begin();

  const std::uint64_t now = clock_source.monotonic_ms();
  const bool initially_pressed = button.pressed();
  button_policy.begin(initially_pressed, now);
  if (initially_pressed) {
    api.set_session(guard.open_setup_session(true, now, random_token()));
  }

  const LoadResult loaded = persistence.load(state);
  if (loaded == LoadResult::corrupt || loaded == LoadResult::unsupported) {
    indicator.set(true, false, false);
  }
  if (!state.profiles.empty()) {
    pipeline.set_calibration(state.profiles.front().calibration);
  }

  // The direct AP is the recovery/control plane on every boot. STA association
  // is asynchronous and never removes AP access.
  transport.begin("Parts-Tally-Direct");
  transport.begin_sta(state.wifi_ssid, state.wifi_password);

  if (!adc.begin()) {
    indicator.set(true, false, false);
  }
}

void loop() {
  const std::uint64_t now = clock_source.monotonic_ms();
  const bool pressed = button.pressed();
  const ButtonAction action = button_policy.update(pressed, now);
  const ResetProgress reset = action == ButtonAction::reset_warning
                                  ? ResetProgress::warning
                                  : (action == ButtonAction::reset_holding ? ResetProgress::holding
                                                                           : ResetProgress::idle);
  show_reset_progress(reset, now);
  if (action == ButtonAction::factory_erased) {
    transport.broadcast(api.event("device.restarting", "{}", now));
    WiFi.disconnect(true, true);
    delay(100);
    ESP.restart();
  }

  AdcSample sample;
  if (adc.read(sample)) {
    pipeline.ingest(sample, now);
  }
  const Measurement measurement = pipeline.evaluate(now);
  if (!state.profiles.empty()) {
    api.record_stable_count(state.profiles.front().id, measurement, now);
  }
  if (reset == ResetProgress::idle) {
    indicator.set(measurement.state != MeasurementState::stable,
                  measurement.state == MeasurementState::stable,
                  measurement.state == MeasurementState::unstable);
  }

  if (action == ButtonAction::tare && pipeline.tare(now)) {
    if (!state.profiles.empty()) state.profiles.front().calibration = pipeline.calibration();
    persistence.save(state);
    transport.broadcast(api.event("status.updated", "{\"localTare\":true}", now));
  }

  if (now - last_event_ms >= 250) {
    char payload[192]{};
    std::snprintf(payload, sizeof(payload),
                  "{\"state\":\"%s\",\"stable\":%s,\"netGrams\":%.6g}",
                  state_name(measurement.state), measurement.stable ? "true" : "false",
                  measurement.net_grams);
    transport.broadcast(api.event("measurement.updated", payload, now));
    if (measurement.state != last_event_state) {
      const bool fault = measurement.state == MeasurementState::disconnected ||
                         measurement.state == MeasurementState::saturated ||
                         measurement.state == MeasurementState::overload_indicated;
      transport.broadcast(api.event(fault ? "fault.raised" : "status.updated", payload, now));
      last_event_state = measurement.state;
    }
    last_event_ms = now;
  }

  transport.poll();
  delay(2);
}

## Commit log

2026-08-18 docs: scaffold Parts Tally product plan
    [preliminary-bom.csv]
2026-08-19 docs: baseline measurable architecture contract (#8)
    Define reviewed requirements, system boundaries, counting semantics, prototype verification plans, and risk controls. Add a fail-closed machine-readable contract validator, unit tests, and CI.
2026-08-20 feat: select and validate prototype measurement chain (#9)
    Document the XIAO ESP32-C3, NAU7802 module, and TAL220B load-cell
    selection with manufacturer evidence, add the planned wiring/bench
    procedure, and provide integrity-bound raw capture analysis tooling.
    [preliminary-bom.csv, synthetic_capture.csv]
2026-08-22 feat(hardware): add reviewed KiCad schematic and BOM (#10)
    * feat(hardware): add reviewed KiCad schematic and BOM
    * fix(hardware): resolve native KiCad ERC findings
    * docs(hardware): record successful native ERC
    ---------
    [bom.csv, non-schematic-items.csv, parts-tally.kicad_sch]
2026-08-23 feat(firmware): establish device runtime and protocol (#11)
    * [verified] feat(firmware): establish device runtime and protocol
    * ci: install protocol schema test dependencies
    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
2026-08-24 feat(app): add accessible offline companion PWA (#12)
    Implements authenticated device workflows, fail-closed count states, profile and calibration management, bounded history, validated import/export, offline caching, accessibility coverage, and mobile/desktop browser tests.\n\nCloses #5\n\n[verified]
2026-08-26 feat(hardware): add carrier PCB and mechanical platform (#13)
    * feat(hardware): add carrier PCB and mechanical platform
    Add the routed KiCad carrier, enforceable antenna keepouts, PCB parity and DRC automation, editable OpenSCAD mechanics, mesh validation, review renders, and evidence-backed layout documentation for issue #6.
    * fix(ci): retain documented ERC waivers
    Preserve the two reviewed headless-library warnings in the KiCad project and make static validation fail if project regeneration drops them again.
    * fix(ci): allowlist unnetted connector hold-downs
    Treat J2's duplicate MP tabs as an explicit board-only mechanical pad ID while continuing to require that both tabs remain unnet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
    [non-schematic-items.csv, parts-tally-base.stl, parts-tally-platform.scad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]
2026-08-27 feat(release): add v0.1.0-rc.1 integration pipeline (#14)
    * feat(release): add integrated release candidate pipeline
    - freeze carrier, firmware, protocol, and app compatibility
    - generate and validate fabrication and source archives
    - add assembly, bring-up, licensing, and verification docs
    - gate tag publication on hardware, firmware, app, and archive checks
    Refs #7
    * fix(release): preserve KiCad container library configuration
    * fix(release): grant KiCad temp output ownership
    * fix(release): merge docs into generated archive
    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
